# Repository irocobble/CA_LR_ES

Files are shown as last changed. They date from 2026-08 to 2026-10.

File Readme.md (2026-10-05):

# Acoustic Sensing Node

**Team:** Aninda Majumdar ([@irocobble](https://github.com/irocobble)) · Subham Basak · Kartik Kajra

A **two-board, field-deployable acoustic sensor** for search-and-rescue. The node
is placed in rubble or debris and listens for signs of a trapped person (voice,
tapping, banging). It works out **which direction** the sound came from and
sends a GPS-tagged alert over LoRa to a rescue dashboard.

Searching collapsed structures is a race against time, and the hardest question
is *where to dig*. Instead of sending people onto unstable rubble to listen, the
node sends the ears in first.

<p align="center">
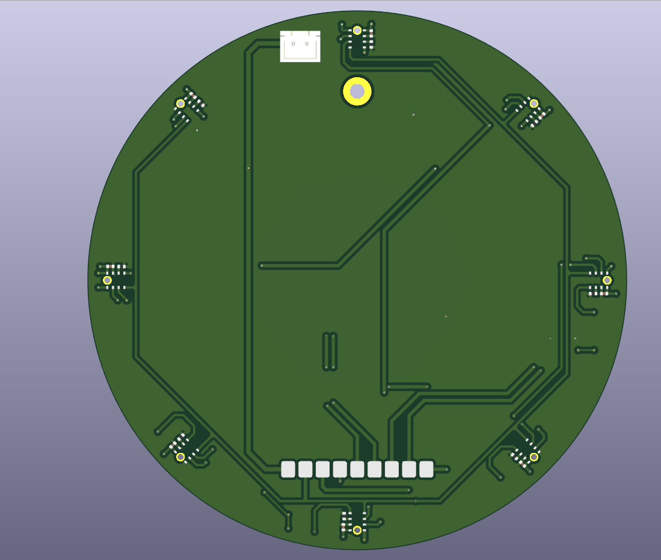
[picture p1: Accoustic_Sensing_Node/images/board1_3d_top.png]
Board 1 - microphone array, 3D render
  
  &nbsp;
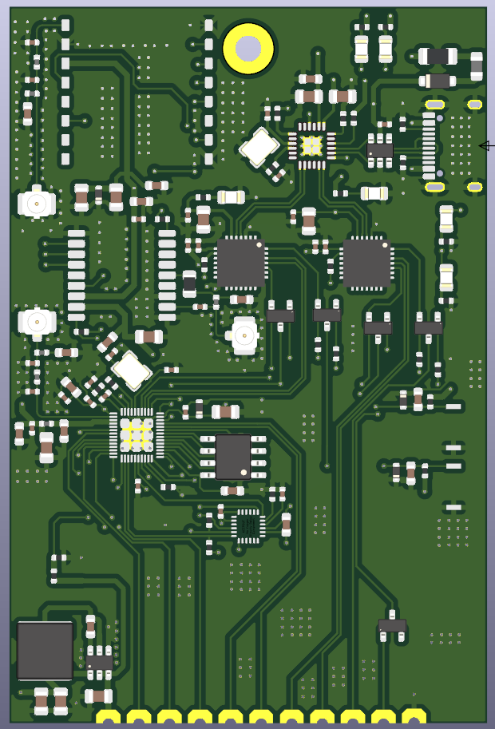
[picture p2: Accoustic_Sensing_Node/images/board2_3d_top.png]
Board 2 - main board, 3D render
  
  <br>
  <em>Left: Board 1, the 8-mic array (2-layer, Ø100 mm). Right: Board 2, the main board (4-layer, 50 × 75 mm).</em>
</p>

---

## Contents

1. [How it works](#how-it-works)
2. [Architecture](#architecture)
3. [Why two boards](#why-two-boards)
4. [Hardware](#hardware)
5. [Microphone array](#microphone-array)
6. [Board-to-board interface](#board-to-board-interface)
7. [Power](#power)
8. [Signal processing on the K210](#signal-processing-on-the-k210)
9. [Voice detection model](#voice-detection-model)
10. [Host software and dashboard](#host-software-and-dashboard)
11. [Prototype results](#prototype-results)
12. [Project status](#project-status)
13. [Open items](#open-items)
14. [Repository layout](#repository-layout)
15. [Getting started](#getting-started)
16. [Engineering notes](#engineering-notes)
17. [Roadmap](#roadmap)
18. [References](#references)

---

## How it works

```
 sound ──▶ 8 MEMS mics ──▶ K210 ──────────────────────────▶ ESP32 ──▶ LoRa ──▶ rescue dashboard
                           │ 1. capture all channels,          │ adds GPS position,
                           │    sampled on the same clock      │ IMU data, timestamp
                           │ 2. "is this a human voice?"       │
                           │ 3. "which direction?"             │
                           └─ sends only the result ───────────┘
                              (angle, confidence, voice yes/no)
```

1. **Listen.** Eight digital microphones sit on a 90 mm circle. They all run
   off one shared clock, so the tiny arrival-time differences between them are
   real and measurable.
2. **Decide.** A small voice-detection model running on the K210 decides
   continuously whether the sound looks like a human voice.
3. **Locate.** The K210 compares the signals from opposite microphones
   (GCC-PHAT) to find the arrival-time difference, then turns it into a bearing.
4. **Report.** Only the result (angle, confidence, level, voice flag) goes to the
   ESP32. No raw audio crosses between the boards.

The K210 stays **powered and listening all the time**. It is not duty-cycled.

---

## Architecture

The system is split across **two boards** that solder together along an 11-pin
castellated edge.

| Board | Layers | Size | Carries |
|---|---|---|---|
| **Board 1: Mic array** | 2 | Ø100 mm | 8× INMP441, Kendryte K210 (Sipeed M1), 12 V→5 V and 12 V→3V3 regulators |
| **Board 2: Main** | 4 | 50 × 75 mm | ESP32 (QFN-48), SX1262 LoRa, MAX-M10S GNSS, MPU-9250 IMU, USB-C hub + 2× USB-UART, 12 V→3V3 regulator |

| Processor | Role |
|---|---|
| **Kendryte K210** (Sipeed M1) | Everything acoustic: I2S master for the array, voice detection, direction finding |
| **ESP32** (QFN-48, 5 × 5 mm) | System host: LoRa, GNSS, IMU, USB, alert formatting |

**Why the K210?** A single K210 I2S peripheral has **four data inputs driven by
one clock generator**. With two microphones per data line, that is eight
channels sampled on exactly the same clock edges. Direction finding depends
entirely on that, and the K210 provides it with nothing to synchronise. It also
has a hardware FFT unit and an audio processor (APU) that can do beamforming,
which we plan to evaluate later.

```
                 ┌──────────────────────────────────────────┐
                 │  BOARD 1: Mic array  (2-layer, Ø100 mm)  │
   8× INMP441 ───┤                                          │
   circle,       │  I2S: 4 data lines, 1 shared clock       │
   r = 45 mm     │            ↓                             │
                 │  K210 / Sipeed M1  (always on)           │
                 │   · voice detection (3-feature model)    │
                 │   · direction of arrival (GCC-PHAT)      │
                 └───────────────┬──────────────────────────┘
                                 │  11-pin castellated edge
                                 │  12 V · mic clock · 2× UART · boot/reset
                 ┌───────────────┴──────────────────────────┐
                 │  BOARD 2: Main  (4-layer, 50 × 75 mm)    │
                 │  ESP32 ── SX1262 LoRa      → U.FL        │
                 │        ── MAX-M10S GNSS    → U.FL        │
                 │        ── MPU-9250 IMU                   │
                 │        ── Wi-Fi/BLE        → U.FL        │
                 │  USB-C → CH334F hub → 2× CP2102N         │
                 └──────────────────────────────────────────┘
```

The IMU is there on purpose. Tapping on rubble produces both a sound and a
vibration. Requiring both reduces false alarms in a way an acoustic-only system
cannot.

---

## Why two boards

The two halves of the design have **opposite needs**:

| | Mic array | Main electronics |
|---|---|---|
| What sets the size | **Physics**: the mics must be far apart to measure direction | **Density**: as small as routing allows |
| Area | Ø100 mm (≈ 7,850 mm²) | 50 × 75 mm (3,750 mm²) |
| Signals | Slow I2S lines, no RF | 3 RF paths, USB, fine-pitch parts |
| Layers needed | **2** | **4** |

On a single board, the whole area would have to be 4-layer, because the LoRa,
GNSS and Wi-Fi antenna feeds need a solid ground plane and 50 Ω traces. We
would be paying 4-layer prices for a large area whose only job is holding
microphones 45 mm from the centre.

### Real cost (as ordered)

Both boards were ordered from **Robu.in**. Prices include shipping.

| Board | Layers | Area | Price paid | Price per mm² |
|---|---|---|---|---|
| Board 1: Mic array | 2 | ≈ 7,850 mm² | **₹900** | ≈ ₹0.115 |
| Board 2: Main | 4 | 3,750 mm² | **₹1,800** | ≈ ₹0.48 |
| **Total (split design)** | | | **₹2,700** | |

On our order, **4-layer cost ≈ 4.2× more per mm² than 2-layer.**

What a single 4-layer board would have cost, at the same ₹0.48/mm²:

| Single-board option | Area | Estimated price | Saving from splitting |
|---|---|---|---|
| Ø100 mm round (smallest that holds the array) | ≈ 7,850 mm² | ≈ ₹3,770 | ≈ 28% |
| 100 × 100 mm (more realistic once both boards' parts fit) | 10,000 mm² | ≈ ₹4,800 | ≈ 44% |

**The split saves roughly 28–44% on bare PCBs.** This is an estimate: fabs have
minimum charges and quantity tiers, so price is not exactly proportional to area.
It is still a fair comparison because both quotes came from the same supplier.

Benefits that do not show up on the invoice:

- **Cheap iteration.** The array geometry is the least certain part of the
  design. Changing it means a new 2-layer board, not a new 4-layer one.
- **Contained failure.** A damaged mic board does not scrap the main board.
- **Assembly yield.** The finest-pitch parts (ESP32 QFN-48 at 0.35 mm,
  2× QFN-28, QFN-24) are all on the small board.
- **RF kept away from audio.** The three antennas are physically separated from
  the microphone traces.

**The trade-off:** the castellated joint is a new failure point and cannot be
probed once soldered. That is why only slow signals cross it: no RF, no
high-speed bus.

---

## Hardware

### Board 1: Mic array (`Board1_2layers/Mic+MPU/`)

| Function | Device | Ref |
|---|---|---|
| Acoustic processor | Sipeed M1 (Kendryte K210) | U12 |
| Microphones | 8× INMP441 I2S MEMS | U1–U6, U15, U16 |
| Buck 12 V → 5 V (K210) | AP63205WU | U14 |
| Buck 12 V → 3V3 (mics) | AP63203WU | U10 |
| Power input | JST-XH 2-pin, polarised | J1 |
| Board interface | 11-pin castellated, 3.2 mm pitch | J3 |
| Buttons | Boot, Reset | SW4, SW3 |

> The `Mic+MPU` folder name is historical. The MPU-9250 is on Board 2.

<p align="center">
  Board 1 top
  &nbsp;
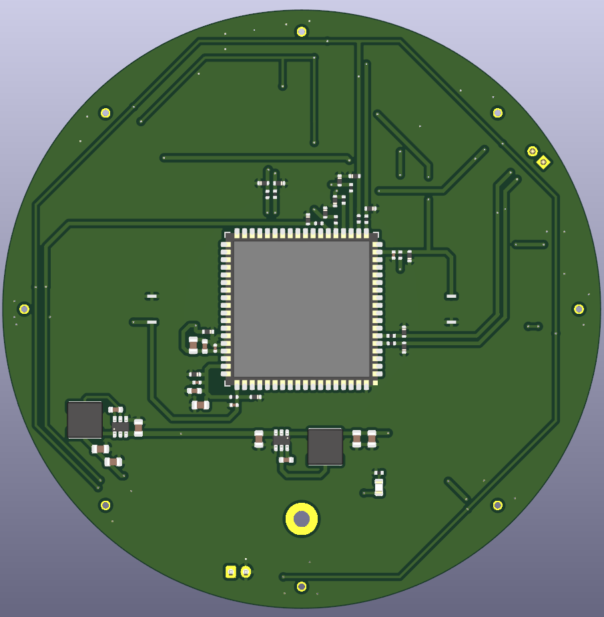
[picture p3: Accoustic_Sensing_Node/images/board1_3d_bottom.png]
Board 1 bottom, mic ports
  
  <br><em>Board 1, top and bottom. The microphone sound holes are on the bottom face.</em>
</p>

<p align="center">
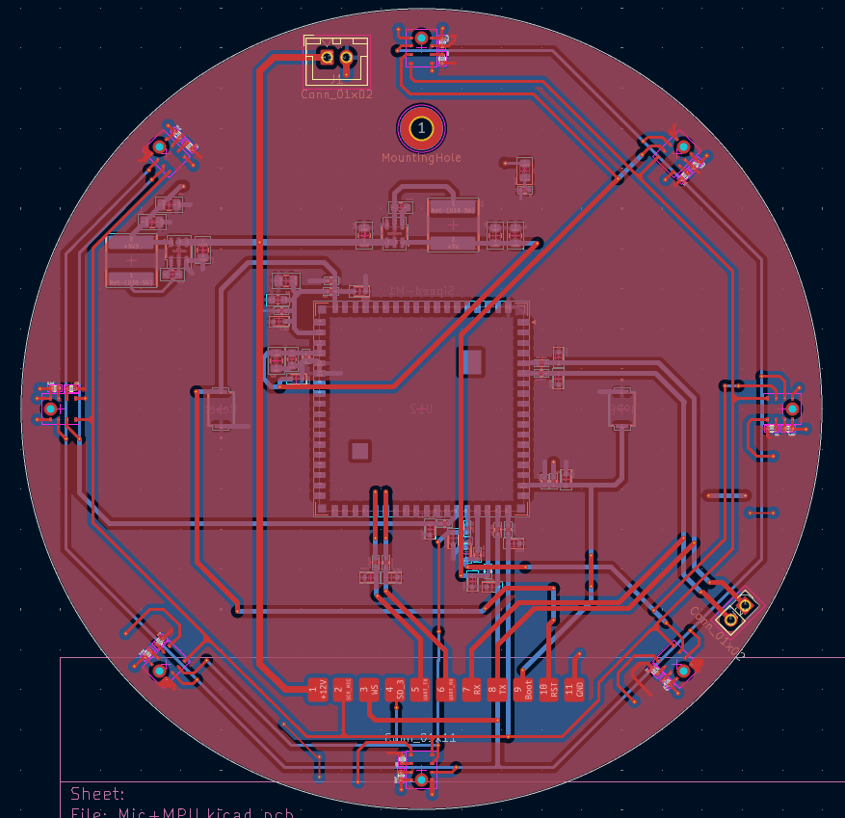
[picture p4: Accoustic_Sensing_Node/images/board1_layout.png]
Board 1 PCB layout
  
  <br><em>Board 1 layout in KiCad.</em>
</p>

### Board 2: Main (`board2_4layers/`)

| Function | Device | Ref |
|---|---|---|
| Host MCU | ESP32 (QFN-48, 5 × 5 mm) | U7 |
| External SPI flash | SPI NOR, SOIC-8 | U6 |
| LoRa transceiver | SX1262 module | U1 |
| GNSS receiver | u-blox MAX-M10S | U3 |
| IMU | MPU-9250 (9-axis) | U4 |
| USB hub | CH334F | CH334F1 |
| USB-UART bridges (ESP32 + K210) | 2× CP2102N | U8, U9 |
| USB ESD protection | USBLC6-4SC6 | U2 |
| Buck 12 V → 3V3 | AP63203WU | U5 |
| Antennas | 3× U.FL: LoRa, GNSS, Wi-Fi | J2, J4, J5 |
| USB connector | USB Type-C | J1 |
| Crystals | 40 MHz (ESP32), 12 MHz (hub) | Y2, Y1 |
| Buttons | EN, BOOT | SW1, SW2 |

Stack-up: GND on F.Cu, In1.Cu and B.Cu; +3V3 on In2.Cu.

<p align="center">
  Board 2 top
  &nbsp;
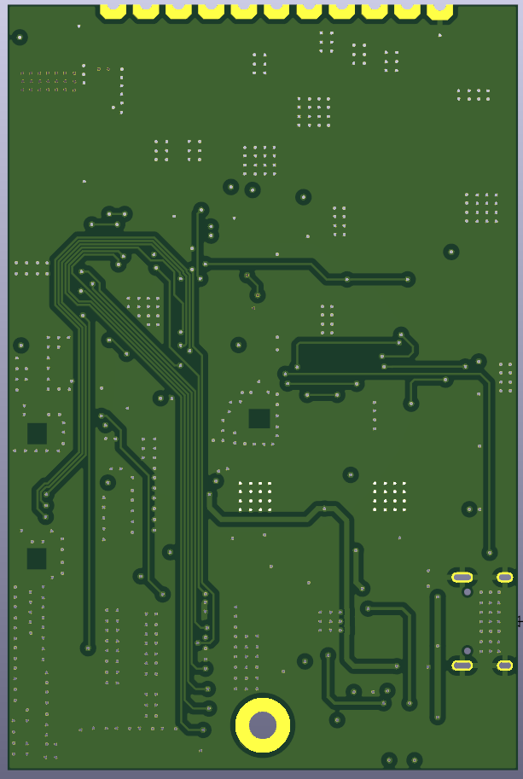
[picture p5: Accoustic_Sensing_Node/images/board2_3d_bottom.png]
Board 2 bottom
  
  <br><em>Board 2, top and bottom.</em>
</p>

<p align="center">
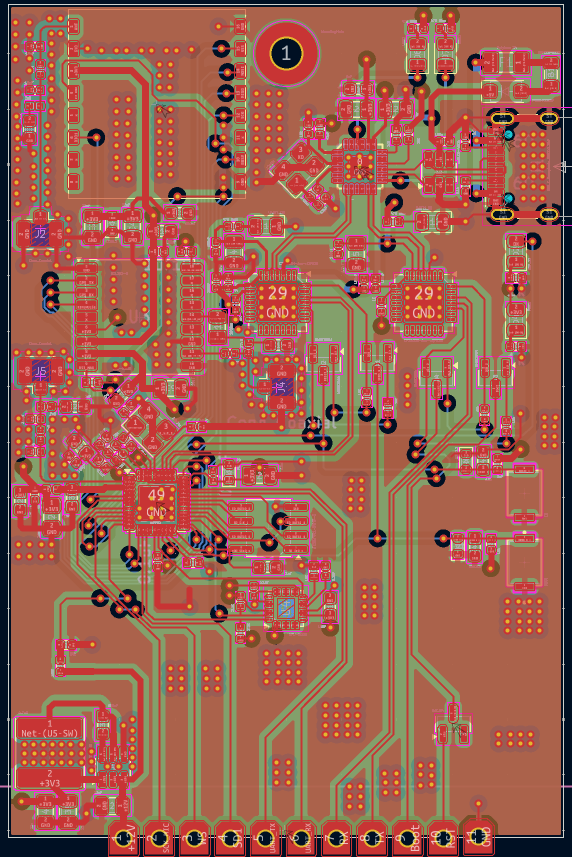
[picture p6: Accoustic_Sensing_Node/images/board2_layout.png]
Board 2 PCB layout
  
  <br><em>Board 2 layout in KiCad.</em>
</p>

---

## Microphone array

Eight INMP441 digital microphones on a circle of **radius 45.00 mm**, spaced
45° apart. Each one is rotated to face the centre, so every microphone has the
same trace shape back to the K210.

Two microphones share each data line. The INMP441's `L/R` pin decides which
half of the stereo frame each one uses: one takes the left slot, the other the
right.

| Data line | K210 pin | Mics | Angles |
|---|---|---|---|
| `SD_1` | IO20 | U1, U2 | 90°, 45° |
| `SD_2` | IO21 | U5, U6 | 0°, 315° |
| `SD_3` | IO22 | U15, U16 | 270°, 225° |
| `SD_4` | IO23 | U3, U4 | 180°, 135° |
| `SCK_MIC` | IO18 | shared bit clock | |
| `WS` | IO19 | shared word select | |

All eight sample on the same bit clock, so every channel is **phase-coherent**.
This is exactly what direction finding needs, and it is why digital MEMS mics
were chosen over analog mics behind a multiplexed ADC.

Every K210 IO used has a **200 Ω series resistor and an ESD diode**, as Sipeed
requires for the M1 module.

> **Sound enters from the bottom.** Each mic sits over a 1.05 mm hole through
> the PCB, so the openings in the enclosure must be on the bottom face.

**Geometry numbers:**

| Quantity | Value | Why it matters |
|---|---|---|
| Adjacent mic spacing | 2r·sin(22.5°) = 34.4 mm | Spatial aliasing above c / (2 × 0.0344) ≈ **5.0 kHz** |
| Opposite mic spacing | 90 mm | Longest baseline, best angle resolution |
| Max arrival-time difference | 90 mm / 343 m/s ≈ 262 µs | Only ≈ **4.2 samples** at 16 kHz, so sub-sample timing is required |

> **About IO20.** On the Sipeed **Maix development board**, IO20 is wired to the
> board's own onboard microphone, so it cannot be used for an external mic there.
> On our PCB the bare **M1 module** is used, which has no onboard microphone, so
> IO20 is free. This only matters if you test the firmware on a Maix board.

---

## Board-to-board interface

11 positions, 3.2 mm pitch, castellated. Board 2 solders directly onto Board 1,
with no connector and no cable.

| Pin | Net | Direction | Purpose |
|---|---|---|---|
| 1 | `+12V` | → Board 2 | Unregulated; each board regulates locally |
| 2 | `SCK_MIC` | K210 → ESP32 | Mic bit clock |
| 3 | `WS` | K210 → ESP32 | Mic word select |
| 4 | `SD1` | mics → ESP32 | Lets the ESP32 hear one mic pair (spare / diagnostics) |
| 5 | `UART_TX` | ESP32 → K210 | Commands |
| 6 | `UART_RX` | K210 → ESP32 | Results: voice flag, confidence, bearing |
| 7 | `RX` | K210 → CP2102N | K210 programming, transmit |
| 8 | `TX` | CP2102N → K210 | K210 programming, receive |
| 9 | `Boot` | CP2102N → K210 | IO16 boot-mode select |
| 10 | `RST` | CP2102N → K210 | Reset (1.8 V domain) |
| 11 | `GND` | | Return |

`TX` and `RX` on pins 7–8 are named **from the USB bridge's point of view** on
both boards.

Pins 2–4 were originally intended for a low-power wake detector on the ESP32.
Since the K210 now stays on all the time, that wake path is not needed. The
pins stay as a spare way for the ESP32 to listen to one mic pair. If used, the
ESP32 must be an I2S **slave**, because the K210 drives the clock.

**No raw audio crosses the joint in normal operation.** The mics feed the K210
directly; the UART carries only results.

---

## Power

```
12 V in (JST-XH, polarised)
   │
   ├── Board 1 ── AP63205 ──▶ +5V   → Sipeed M1 (K210)
   │           └─ AP63203 ──▶ +3V3  → 8× INMP441
   │
   └── via J3 pin 1 ──▶ Board 2 ── AP63203 ──▶ +3V3
                                     → ESP32, SX1262, MAX-M10S, MPU-9250, flash
```

Only 12 V and GND cross the joint, so no regulated rail loses voltage across it
and the RF and audio sections do not share regulator noise.

**Estimated ≈ 3.3 W total (≈ 320 mA at 12 V)**, mostly the K210 (≈ 1.5 W).
This is an estimate and will be measured once the boards are assembled.

---

## Signal processing on the K210

The firmware is plain C on the **kendryte-standalone-sdk**, in two CMake projects:

| Project | Build flag | Output | Use |
|---|---|---|---|
| Recorder | `-DPROJ=Recorder` | `Recorder.bin` | Streams raw mic audio to the PC for datasets and calibration |
| Detector | `-DPROJ=Detector` | `Detector.bin` | Runs voice detection and direction finding on the chip |

### Capture

- 16 kHz nominal. The K210's PLL gives a real rate of about **15,986 Hz**. The
  difference is small and does not affect the results.
- Samples are 32-bit from the INMP441, shifted down to 16-bit
  (`SAMPLE_SHIFT = 13`, the smallest shift where no channel clips).
- The conversion to 16-bit **saturates** instead of wrapping. A wrapped sample
  looks like a loose wire, which is very confusing during debugging.
- A **100 Hz high-pass filter** (4th-order Butterworth) removes rumble and DC
  before anything else.

### Direction of arrival (GCC-PHAT)

For each pair of opposite microphones:

1. Take a **1024-point FFT (64 ms)** of both channels.
2. Compute the cross-spectrum and divide each bin by its own magnitude
   (the **PHAT** weighting). This keeps only phase, which is what carries timing.
3. **Keep only 300–3400 Hz** (the speech band). Without this mask, the empty
   bins are amplified to the same weight as real ones and the answer is
   essentially random. Measured: a true delay of 1.50 samples was estimated as
   0.14 unmasked and 1.49 masked.
4. **Search for the delay directly at fractional lags.** A coarse pass in
   0.10-sample steps, then a fine pass in 0.01-sample steps around the best one.
   Each lag is evaluated with the FFT shift theorem, so no curve-fitting is
   needed. This matters because the whole array spans only about 4 samples of
   delay; whole-sample steps would give very coarse bearings.
5. The search range comes from the spacing:
   `max lag = spacing / c × fs × 1.4` (40% extra for echoes and measurement error).
6. Two perpendicular pairs give `lag_x` and `lag_y`, and the bearing is
   `atan2(lag_y, lag_x)`.
7. Results are rejected if the sound is too quiet (`-45 dB` level gate), the
   correlation is too weak (`< 0.08`), or the delay is impossibly large.

Direction finding runs on **any loud enough sound**, not only on speech. The
voice flag is reported alongside it.

**Calibration matters.** On the prototype, two I2S channels start on different
word-select edges, which adds a constant offset between them. We measured
`lag_x` bias = **−0.93** and `lag_y` bias = **+0.95** samples, and the firmware
subtracts them (`DOA_LAG_X_BIAS`, `DOA_LAG_Y_BIAS`).

### What the array can and cannot do

- It reports **one bearing per update**: the dominant sound source. Separating
  several people talking at once needs a much larger array (roughly 0.5 m or
  more across), which is not practical for a node this size.
- It gives **direction, not distance**. On the dashboard, how far a dot is from
  the centre shows **how old** the detection is, not how far away the source is.
- Distance comes from **combining several nodes** (triangulation), which is on
  the roadmap.

### Result packet (K210 → host)

20 bytes, sent at `REPORT_HZ = 20`:

```
[5A A6] [len=0x10] [seq] [angle×10 : i16] [conf×1000 : u16] [score×100 : i16]
[level_db×10 : i16] [speech : u8] [warm : u8] [lag_x×100 : i16] [lag_y×100 : i16] [xor] [pad]
```

Raw-audio frames from the Recorder use:

```
[5A A5] [seq : u8] [blk : u16] [nch : u8] [int16 samples × blk·nch] [sum16]
```

The sequence number lets the PC detect and count dropped bytes. Before framing,
one lost byte silently turned the rest of a recording into noise while the WAV
file still looked valid.

---

## Voice detection model

A **logistic regression on 3 hand-picked features**, small enough to run on the
K210 as a single dot product.

| Feature | What it measures |
|---|---|
| `harmonicity` | Strength of the pitch peak in the autocorrelation (human pitch range, lags 40–266 samples) |
| `voice_band_ratio` | Share of energy in 300–3400 Hz (512-point Hann-window FFTs) |
| `snr_db` | Level above a rolling noise floor (20th percentile over the last 8 s) |

- Trained in Python (`Accoustic_Sensing_Node/ML/`). The feature scaler is folded into the weights and
  exported as `vad3_model.h`, so the chip does no extra scaling.
- Decision threshold (logit) **2.389**, then smoothed over **3** consecutive
  decisions (`VAD_SMOOTH_K = 3`).
- `FEATURE_VERSION = 4`. The firmware and Python feature code must match. The
  version number makes a mismatch obvious.
- Evaluation uses **grouped cross-validation by recording file**, so clips from
  the same recording never appear in both training and test. The main metric is
  **recall at 5% false-positive rate**, because false alarms are what make
  rescuers stop trusting a sensor.

### Dataset status

Our own recordings (`INMP_441_Dataset/`) are combined with public datasets
(`Public_Dataset/`). Every file goes through a quality check (dropped bytes,
clipping, DC offset, rumble, SNR) before it is used.

We also run a **confound check**: a classifier trained only on the *background*
of each recording, with the speech removed. If it can still tell the classes
apart, the model could be learning *which session* a clip came from instead of
*whether someone is speaking*.

| Dataset version | Background-only AUC | Target |
|---|---|---|
| First dataset | 0.905 – 0.94 | < 0.65 |
| Latest | **0.812** | < 0.65 |

It is improving, but still above target. Recording speech and non-speech
**interleaved in the same session, room and distance** is the fix in progress.

---

## Host software and dashboard

Python tools on the PC, all reachable from one entry point:

```
python capstone.py --help
```

| Command | What it does |
|---|---|
| `status`, `devices`, `linktest`, `inspect` | Check setup, list serial ports, test the link, inspect captures |
| `record` | Record labelled clips from the board |
| `qc`, `filters` | Dataset quality check, filter tests |
| `train`, `train-corpus`, `export` | Train the model and export `vad3_model.h` |
| `predict` | Run the model on WAV files |
| `serve`, `monitor`, `gui` | Live API + dashboard, console monitor, desktop GUI (`sar_gui.py`) |

**API server** (`api_server.py`): reads the K210's result packets from serial
and serves them over HTTP on all interfaces (port 8000 by default), so a phone
on the same Wi-Fi hotspot can open the dashboard.

| Endpoint | Returns |
|---|---|
| `/api/detections` | Detections from the last 15 s |
| `/api/state` | Latest bearing, level, voice flag |
| `/api/threshold` | Read or change the detection threshold |
| `/api/health` | Server and serial-link status |
| `/` | `dashboard.html`, the radial display |

It uses a threaded server with HTTP/1.1 keep-alive, which fixed the lag we saw
on phones over a hotspot.

<p align="center">
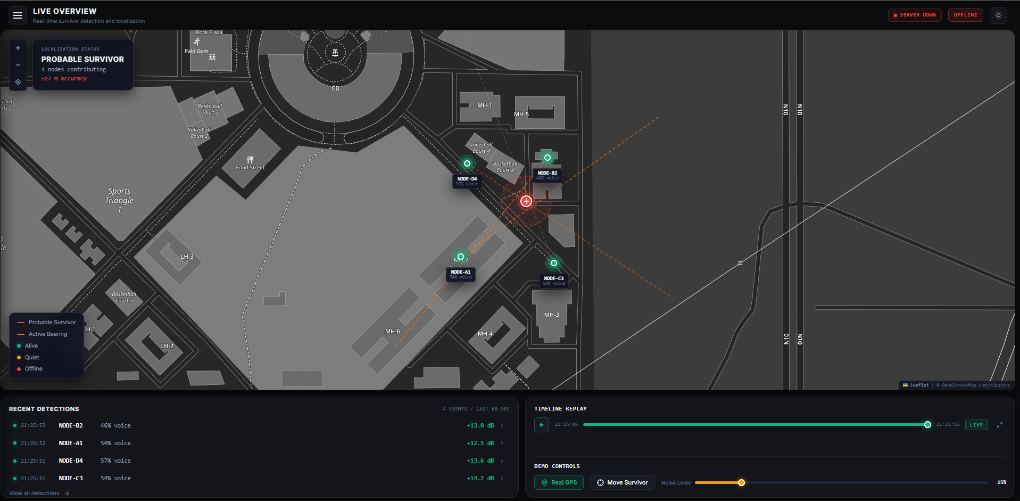
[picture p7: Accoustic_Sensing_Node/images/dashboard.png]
Live dashboard
  
  <br><em>Live dashboard in the browser.</em>
</p>

---

## Prototype results

Before the PCBs, the full pipeline was built on a breadboard: a Sipeed Maix
board with **4 INMP441 mics in a 40 mm square**. Opposite corners are paired, so
the baseline is the square's diagonal, **56.6 mm**.

<!-- Add the photo later: save it as Accoustic_Sensing_Node/images/prototype_breadboard.jpg and delete these comment markers
<p align="center">
  <img src="Accoustic_Sensing_Node/images/prototype_breadboard.jpg" width="60%" alt="Breadboard prototype">
  <br><em>Breadboard prototype: Maix board + 4 INMP441 in a 40 mm square.</em>
</p>
-->

What works on the prototype:

- Phase-coherent 4-channel capture on one I2S peripheral
- On-chip voice detection and GCC-PHAT bearing, streamed live to the dashboard
- North and West bearings accurate before calibration; East and South were
  tilted until the cross-channel bias correction was added

**A measured accuracy table (true angle vs reported angle, several distances)
will be added once the PCB is assembled.** Numbers from the breadboard are not
representative of the final board, so they are not published here.

---

## Project status

### Hardware

- [x] Board 1 schematic and layout complete; 8 mics at exact geometry (r = 45.000 mm)
- [x] Board 1: K210 power, programming, boot/reset, 1.8 V reset domain; 200 Ω + ESD on every IO
- [x] Board 2 schematic and layout complete, DRC clean
- [x] Board 2: ESP32 core, LoRa, GNSS (active-antenna bias-T), IMU, USB-C hub with auto boot/reset for both processors
- [x] **Both boards ordered** (Robu.in)
- [ ] Assembly and bring-up
- [ ] Measured power consumption

### Firmware (K210)

- [x] `Recorder` and `Detector` CMake projects
- [x] Framed, checksummed audio stream with sequence numbers
- [x] On-chip 3-feature voice detector (`vad3_model.h`, `FEATURE_VERSION = 4`)
- [x] Working 4-mic GCC-PHAT direction finding on the prototype, with bias calibration
- [ ] 8-channel capture on the new array
- [ ] Re-measure all DOA constants on the circular array
- [ ] Evaluate the K210 APU hardware beamformer

### Firmware (ESP32)

- [ ] LoRa, GNSS and IMU drivers
- [ ] UART link to the K210 and alert formatting
- [ ] Sound + vibration fusion

### Host software

- [x] `capstone.py` single entry point, `sar_gui.py` desktop GUI
- [x] API server + dashboard, 15 s detection window, keep-alive
- [x] Dataset QC, training, grouped evaluation, C-header export
- [ ] Multi-node triangulation view

---

## Open items

| # | Item | Where | What to do |
|---|---|---|---|
| 1 | **DOA constants are for the 4-mic breadboard** | Firmware | `DOA_SPACING_MM`, `SAMPLE_SHIFT` and both lag biases must be re-measured on the circular array (opposite pair = 90 mm) |
| 2 | **Every opposite pair spans two data lines** | Firmware | e.g. 0° is on `SD_2` and 180° on `SD_4`. Each data line may have its own timing offset, so calibrate a **per-data-line offset** at bring-up (the prototype needed ≈ ±0.9 samples) |
| 3 | **Channel order is not ring order** | Firmware | K210 inputs D0–D3 = `SD_4`, `SD_3`, `SD_2`, `SD_1`. Build the channel→angle table and confirm it with a tap test at each mic |
| 4 | Dataset confound | ML | Background-only AUC 0.812, target < 0.65. Record both classes interleaved in the same session |
| 5 | Measured DOA accuracy table | Testing | After PCB assembly |
| 6 | Flash part name | Board 2 | U6 value field shows `AT25SF081`; update it to the part actually fitted |
| 7 | CP2102N no-connect pins | Board 2 | Add no-connect flags on U8/U9 pin 10 (cosmetic, clean ERC) |
| 8 | Stale BOM export | Board 2 | `Accoustic_Sensing_Node.csv` is from an older revision; re-export from KiCad |
| 9 | Battery operation | Both | Node runs from 12 V only; battery + boost planned |
| 10 | One M2.5 mounting hole per board | Both | Add more before the enclosure is fixed |
| 11 | Enclosure | Mechanical | Sound openings on the bottom face, antenna clearance, survives drops |

---

## Repository layout

Everything for the acoustic node lives in the `Accoustic_Sensing_Node/` folder:

```text
Accoustic_Sensing_Node/
├── README.md                     ← copy of this file
├── images/                       ← all pictures used in this README
│
├── Board1_2layers/
│   ├── Mic+MPU/                  KiCad project: mic array board (2-layer)
│   │   ├── Mic.pretty/           INMP441 footprint (with sound hole)
│   │   ├── Connectors.pretty/    11-pin castellated footprint
│   │   └── output/               Gerbers as ordered
│   └── mic/INMP441.kicad_mod
│
├── board2_4layers/               KiCad project: main board (4-layer)
│   ├── *.pretty/                 custom footprints (LoRa, GNSS, USB hub, edge pads)
│   └── Output/                   Gerbers + drill as ordered
│
├── Recording_Via_IOT_Devices/
│   ├── firmware/
│   │   ├── K210/src/Recorder/    raw multi-channel streaming
│   │   ├── K210/src/Detector/    main_detector.c, sar_features.c, sar_doa.c, vad3_model.h
│   │   └── esp32_1mic/           single-mic ESP32 recorder (dataset collection)
│   ├── record.py, devices.py     recorder and per-board serial settings
│   ├── api_server.py             HTTP API + serial reader
│   ├── dashboard.html            radial live display
│   ├── detector_monitor.py       console monitor
│   └── link_test.py              serial link test
│
├── ML/                           features, training, QC, export to C header
├── capstone.py                   single entry point for all tools
├── sar_gui.py                    desktop GUI
├── requirements.txt
├── run_gui.bat, build_exe.bat
└── BUILD.md                      building the firmware and the .exe
```

Datasets (`INMP_441_Dataset/`, `Public_Dataset/`) are **not** stored in the repo
because of their size.

---

## Getting started

Run everything from inside the acoustic folder:

```bash
cd Accoustic_Sensing_Node
```

### 1. Python tools

```bash
pip install -r requirements.txt
python capstone.py status
```

Try the dashboard with no hardware:

```bash
python Recording_Via_IOT_Devices/api_server.py --demo
# open http://localhost:8000
```

### 2. Build and flash the K210 firmware

```bash
cd Recording_Via_IOT_Devices/firmware/K210
mkdir build && cd build
cmake .. -DPROJ=Detector -DTOOLCHAIN=/opt/kendryte-toolchain/bin
make
kflash -p COM12 -b 1500000 Detector.bin
```

> **Delete the `build/` folder when switching between `Recorder` and
> `Detector`.** CMake caches the project name, so otherwise it silently builds
> the old one again.

See `BUILD.md` for Windows details.

### 3. Run live

```bash
python Recording_Via_IOT_Devices/api_server.py --port COM12
# optional: --capture session.bin  (save the raw stream to replay later)
#           --wav heard.wav        (save what the detector is hearing)
#           --replay session.bin   (replay a saved session, no hardware)
```

Then open `http://<pc-ip>:8000` on any device on the same network.

---

## Engineering notes

Things learned the hard way, kept here so they are not learned twice:

- **Measure, don't assume.** Every DOA constant on the prototype came from
  measurement, not a datasheet. Mic spacing is measured between the actual
  sound holes, in **millimetres**.
- **Serial port settings.** pyserial asserts DTR and RTS by default. That
  resets the ESP32 and puts the K210 into its bootloader, where it sends
  nothing. `devices.py` clears both before opening the port.
- **UART pins.** The ESP32 transmits on GPIO5, so the K210 uses **IO31 as RX and
  IO30 as TX**.
- **ESP32 GPIO12 stays unconnected.** It sets the flash voltage at reset; high
  selects 1.8 V.
- **K210 IO voltages.** IO0–IO35 are 3.3 V, IO36–IO47 are 1.8 V. Every signal
  used is IO35 or below.
- **ESP32 flash mode.** Start in DIO; QIO needs chip-specific setup.
- **Faulty mics happen.** During prototyping one INMP441 was dead and one had
  a blocked sound hole (≈ 6.6 dB quieter). Check every channel's level before
  trusting a bearing.

---

## Roadmap

- Assemble both boards; bring up 8-channel capture
- Re-calibrate DOA on the circular array and publish a measured accuracy table
- Compare the K210 APU hardware beamformer with software GCC-PHAT
- Move the voice model to the 8-mic front end
- ESP32: LoRa, GNSS, IMU and the end-to-end alert path
- Combine sound and vibration (IMU) to reduce false alarms
- Multi-node triangulation on the dashboard
- Battery power (the K210 stays always on, so battery size is set by its ≈ 1.5 W)
- Enclosure: sound openings, antenna clearance, drop survival

---

## Applications

**Main use:** search-and-rescue: locating people trapped under collapsed
buildings. Several nodes across a site turn a large, uncertain search area into
a short list of places worth digging.

**Other uses:** perimeter and intrusion detection, wildlife monitoring, noise
source mapping, remote sensor networks with human-presence detection.

---

## References

- C. Knapp and G. Carter, *The Generalized Correlation Method for Estimation of
  Time Delay*, IEEE Trans. ASSP, 1976 (GCC-PHAT)
- J. DiBiase, *A High-Accuracy, Low-Latency Technique for Talker Localization
  in Reverberant Environments Using Microphone Arrays*, PhD thesis, Brown
  University, 2000 (SRP-PHAT)
- Sipeed M1 datasheet: module pinout, IO voltages, reset constraints
- Kendryte K210 datasheet and kendryte-standalone-sdk
- InvenSense INMP441 datasheet
- Espressif *ESP32 Hardware Design Guidelines*

---

## License

Under active development. License to be decided.

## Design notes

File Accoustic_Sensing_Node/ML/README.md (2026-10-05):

# ML

Three features. That is the whole input.

```
python qc.py                      check the dataset first
python train_basic.py             fit and cross-validate
python predict.py --wav x.wav     run it on a file
python predict.py --port COM12    run it live
```

## Files

- `features3.py` — the three features, written to be read. Each one has the
  idea in plain words, the steps, and a note on what the C version looks like.
- `qc.py` — per-file health plus the confound probe.
- `train_basic.py` — your own recordings only. Grouped cross-validation,
  recall@5%FPR, and a single-threshold baseline for comparison.
- `train_corpus.py` — your recordings plus `Public_Dataset`, every source
  budgeted by window count.
- `predict.py` — file and live inference, with smoothing and hangover.
- `filter_test.py` — compares front-end filter settings against your data
  and against synthetic confusers. Run it before changing the filtering.

## The high-pass is not optional

Everything is filtered at 100 Hz before any feature is computed. Without it,
`harmonicity` measures the microphone's low-frequency rumble instead of the
voice. Measured on the first dataset:

| | speech | non-speech | d-prime |
|---|---|---|---|
| no high-pass | 0.691 | 0.696 | **0.03** |
| 100 Hz high-pass | 0.660 | 0.377 | **2.43** |

The firmware removes DC only, at about 5 Hz, so this has to happen here.
Filtering on the device is irreversible; filtering here is a line you can
change.

## Read the d-prime table before the accuracy

`train_basic.py` prints how well each feature separates the classes on its
own. Above 1 is useful, above 2 is strong. If a feature sits near 0 it is
contributing nothing and something upstream is wrong — that table is what
caught the missing high-pass.

## Why not accuracy

Accuracy on an imbalanced, cost-asymmetric problem rewards guessing the
majority class. Report **recall at 5% false-alarm rate**: how many voices you
catch, at a stated cost in false alarms.

Also: PR-AUC is only comparable between runs with the same class balance,
because its chance baseline *is* the positive rate. Use ROC-AUC or
recall@FPR when comparing across datasets.

## Growing past three features

Add a fourth only when you can name the failure it fixes. The previous
version of this project reached 52 features, and an ablation showed the two
largest-weighted ones could be deleted with a cost of 0.001 — they were
collinear with features already present. More features mostly buys more ways
to be wrong.

## Budget by windows, never by files

`train_corpus.py` caps each source by **window count**, and this is the whole
reason it exists. Window yield per file differs by three orders of magnitude:

| source | typical file | windows per file |
|---|---|---|
| MUSAN speech | ~8 min | ~1000 |
| MUSAN music | ~2 min | ~450 |
| ESC-50 | 5 s | 9 |
| Speech Commands | 1 s | 1 |

Cap every source at 1200 *files* and MUSAN takes 99.4% of the positive
windows while Speech Commands contributes 0.6% — the speaker diversity that
was the entire reason for adding it never reaches the model. The per-source
percentage table printed at startup is there so this is visible immediately.

Two other things it handles that a naive loader would not: ESC-50 is 44.1 kHz
while everything else is 16 kHz, so it resamples; and Speech Commands clips
are exactly one window long, which makes `snr_db` degenerate, so short clips
are concatenated into longer pseudo-recordings first.

## The feature-subset table

Every run prints recall@5%FPR for all seven combinations of the three
features. If a two-feature row is within about 0.02 of all three, drop the
third — one fewer feature is one fewer thing to port to C and one fewer thing
to test for numerical parity.

## Should you add a low-pass?

Run `python filter_test.py` rather than guessing. The measured answer so far:

**A low-pass does not help, and can backfire.** Narrowband signals
autocorrelate well, so restricting the band makes *everything* look more
periodic. Measured on synthetic confusers, white noise harmonicity climbs
from 0.152 to 0.330 as the low-pass tightens from none to 1 kHz — the feature
becomes less able to reject the thing it exists to reject.

**Pre-emphasis is the change that helps.** `y[n] = x[n] - 0.97·x[n-1]`, one
multiply-add, flattens a 1/f spectrum. 1/f noise is concentrated at low
frequencies and therefore looks narrowband, which is why rumble scores as
"periodic" when it is nothing of the sort:

| confuser | HP100 only | HP100 + pre-emphasis |
|---|---|---|
| pink noise | 0.625 | **0.182** |
| wind rumble | 0.452 | **0.142** |
| speech | 0.812 | 0.787 |

Margin against the worst confuser goes from −0.038 to **+0.058**, the only
configuration tested that reaches positive.

**But the two tests disagree, so this is not settled.** On the first dataset,
pre-emphasis *lowered* harmonicity d-prime from 2.43 to 1.57 — because that
dataset's negatives are rumble-dominated room tone, and its confound is partly
rumble, so removing rumble removes some of the (spurious) separation. Believe
the synthetic test until your own negatives contain wind, machinery and 1/f
rumble, and re-run both once `qc.py`'s probe passes.

## The limit no filter fixes

A steady tonal source — a generator, the canonical rubble-site confuser —
scores **0.850** harmonicity against speech's 0.812, under every filter
setting tested. That is not a bug: a generator genuinely is periodic.

The cue that separates them is syllable-rate modulation. Speech fluctuates at
2–8 Hz because of syllables; a generator does not. Add that fourth feature
when you have recorded a generator and can show it is needed — not before.

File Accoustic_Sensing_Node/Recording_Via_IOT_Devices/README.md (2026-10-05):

# Recording_Via_IOT_Devices

```
python record.py --list
python record.py --device esp32 --port COM12 --label speech --minutes 2 \
                 --speaker 1 --room lab --set 1 --distance 2m
```

## Files

- `record.py` — the recorder. Handles all three boards.
- `devices.py` — baud rate, frame format and DTR/RTS policy per board.
  Adding a board means adding one entry here.
- `firmware/esp32_1mic/esp32_1mic.ino` — one INMP441, framed output.
- `firmware/k210_1mic/k210_1mic.c` — same, for the Kendryte SDK.

## Wire formats

ESP32 / STM32 (`v2`):
```
[0x5A][0xA5][seq16][count16][int16 payload × count][xor8]
```

K210 (`k210`):
```
[0x5A][0xA5][seq8][blk16][nch8][int16 payload × blk·nch][sum16]
```

The magic word alone is **not** a sync point: `0x5A 0xA5` occurs by chance
inside int16 audio in about 1.6% of blocks, and locking onto a false one at an
odd byte offset shifts every sample boundary afterwards. So four things are
checked before a frame is accepted — the shape fields are sane, the channel
count matches, the checksum matches, and the sequence advanced by exactly one.
A false magic fails at least one of them nearly always.

The sequence number is the point. Raw unframed PCM has no way to recover from
a dropped byte: lose one and the 16-bit sample boundary flips, so every
sample afterwards is noise at the Nyquist frequency — while the WAV header
stays valid and the file still plays. Three files in the first dataset failed
exactly this way and it took weeks to notice. With sequence numbers the
recorder **counts** what was lost and tells you while you are still standing
there.

Watch the `dropped=` counter during capture. If it climbs, stop: lower the
baud rate or shorten the USB cable before recording anything you intend to
keep.

## Two board-specific traps

**Both boards must have DTR and RTS deasserted before the port opens.**
pyserial asserts both by default. On the ESP32 that reboots the board
mid-capture; on the K210 it drops into the ISP bootloader, where it sends
nothing at all and the capture reads zero bytes forever. `devices.py` sets
both to `False`.

**The CH552/CH340 bridge on the K210 ignores the configured baud rate.**
Throughput is fixed and lower than requested regardless of what you ask for,
which makes the K210 a poor choice for streaming audio. Prefer the ESP32 for
dataset collection.

## Before trusting any audio

The firmware prints `#` diagnostic lines at boot: which I2S slot the mic is
actually in, the min/max sample values, and the measured sample rate.
`record.py` shows them. Healthy means min and max swing on both sides of
zero, not all-zero, not pinned at the rails. Slot and shift are worth
observing rather than assuming — on the earlier bring-up the datasheet alone
was not enough and both had to be settled by dumping raw words.

## K210: only one slot is transmitted

One I2S data line always carries two slots — 64 bit-clocks per frame, not
configurable. So `k210_1mic.c` still *captures* both and keeps the one the
microphone is in. That halves the payload:

| | frame | throughput | share of the 921600 link |
|---|---|---|---|
| both slots | 1032 B | 64.5 kB/s | 70% |
| one slot | 520 B | 32.5 kB/s | **35%** |

The CH552-class bridge has no flow control back to the K210, so headroom is
the only defence against drops. This is the largest reliability gain available
without changing hardware.

**Set `MIC_SLOT` from the tap test, not from the datasheet.** The diagnostic
window reads both slots and marks the one being kept with `*`. Tap the
housing: exactly one should jump. The wrong slot records the undriven line —
near-silence, valid header, plays fine, trains a useless model.

## The K210 high-pass was moved from 300 Hz to 20 Hz

The array firmware filtered at 300 Hz, which was correct there: across a
100 mm baseline a 1 m wavelength carries no usable timing information.

For single-microphone voice detection it breaks the main feature. Harmonicity
finds the pitch period, and 300 Hz sits *above* the fundamental of every adult
voice — 85–155 Hz male, 165–255 Hz female. Autocorrelation can still work off
the harmonics, but it weakens and becomes prone to octave errors.

So the firmware now removes DC and nothing else. The real 100 Hz high-pass
lives in `ML/features3.py`, where it is a line you can change rather than a
reflash.

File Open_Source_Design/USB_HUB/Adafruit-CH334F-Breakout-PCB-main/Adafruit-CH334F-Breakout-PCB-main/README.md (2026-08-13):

## Adafruit CH334F Mini USB Hub Breakouts PCB

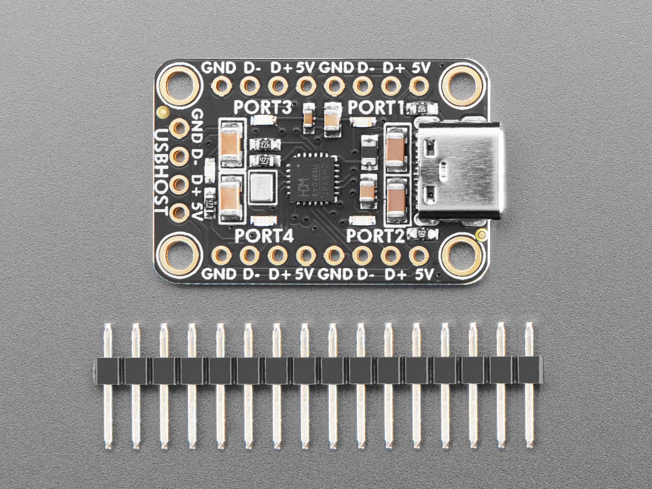
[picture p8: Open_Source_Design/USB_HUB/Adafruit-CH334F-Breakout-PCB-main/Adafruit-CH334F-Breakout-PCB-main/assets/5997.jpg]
<a href="http://www.adafruit.com/products/5997"><br/>
Click here to purchase one from the Adafruit shop</a>
<br>
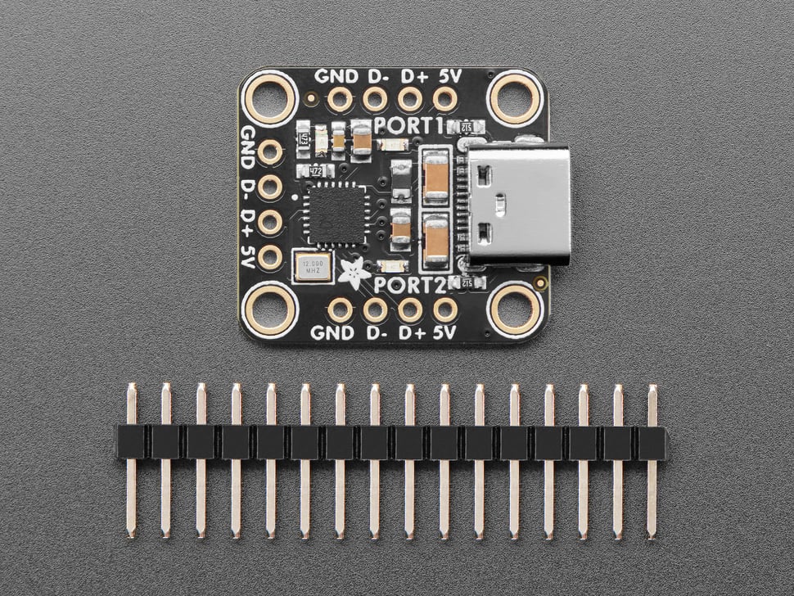
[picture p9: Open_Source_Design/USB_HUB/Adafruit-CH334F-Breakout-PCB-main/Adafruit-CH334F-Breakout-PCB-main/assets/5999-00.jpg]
<a href="http://www.adafruit.com/products/5999"><br/>
Click here to purchase one from the Adafruit shop</a>

PCB files for the Adafruit CH334F Mini USB Hub Breakouts

Format is EagleCAD schematic and board layout
* https://www.adafruit.com/product/5997
* https://www.adafruit.com/product/5999

### Description

Sometimes you've got something with USB host, like a embedded linux board, and you want to connect more than one thing. Or maybe you want to turn something like a keyboard into a multi-device USB peripheral. The Adafruit CH334F Mini 4-Port USB Hub Breakout will do that for you! it features a CH334F USB 2.1 hub chip which converts one high-speed port into four.

Most folks who use a USB hub get one that comes in an enclosure with connectors or cables included. But, those hubs are going to be bulky - they're meant for external use. This breakout board is designed to be compact, so it can easily be embedded into an enclosure or existing device. There's four mounting holes but other than that, we tried to keep it as compact as possible.

Part of how we kept it small is not including downstream ports! The breakout has either 0.1" header or USB C for the upstream, and then four 4-pin ports for peripheral connections. We expect folks to solder directly to the pads or use our 'simple' USB-breakout cables.

You get one fully assembled/tested boards and some extra header if you happen to want to plug it into a breadboard. Other than that, just keep in mind there's no USB ports for the 4 downstreams - if you need those take a look at some of the other hubs we stock.

### License

Adafruit invests time and resources providing this open source design, please support Adafruit and open-source hardware by purchasing products from [Adafruit](https://www.adafruit.com)!

Designed by Limor Fried/Ladyada for Adafruit Industries.

Creative Commons Attribution/Share-Alike, all text above must be included in any redistribution. 
See license.txt for additional details.

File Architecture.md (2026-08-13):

# System Architecture

## Introduction

The **Acoustic Sensing Node** is a single-board embedded platform for acoustic
search-and-rescue. It is designed to be physically inserted into rubble or
debris, detect human distress signals, estimate the direction those signals came
from, and relay a GPS-tagged alert over a long-range radio link — fully
self-contained, with no cable, no network, and no operator nearby.

All subsystems — microphone array, edge inference, positioning, inertial sensing,
radio, and power — are consolidated onto one PCB. Integration over modularity is
deliberate: a unit that gets thrown or dropped into debris has fewer failure
points with fewer interconnects.

---

## Design Goals

### Direction, Not Just Detection

The node's headline output is a **bearing**, not a boolean. A rescue team acting
on "survivor at bearing 42° from node 3" can dig in a specific place; a team
acting on "sound detected" cannot. This drove the choice of a six-microphone
phase-coherent array and a processor with hardware array-processing support.

### Hardware-Accelerated Acoustic Processing

The Kendryte K210's **APU (Audio Processing Unit)** implements microphone-array
processing in silicon: sound source localization, beamforming, and voice
detection, backed by a dedicated FFT accelerator. Doing direction-of-arrival in
hardware rather than in a DSP loop keeps the compute budget available for
classification.

### Split of Concerns Across Two Processors

The K210 owns the acoustic path end-to-end — it is the I2S master for the mic
array and runs beamforming and classification. The ESP32-S3 owns everything else
— radio, positioning, inertial sensing, USB and power. Neither processor
duplicates the other's work, and the link between them carries results only.

### Cross-Modal False-Positive Rejection

A 9-axis IMU sits alongside the acoustic front end. Tapping and banging produce
both an acoustic signature and a mechanical impact signature; requiring both
substantially reduces false alarms from wind, settling debris, and machinery.

### Field Deployability

GNSS positioning and timestamping, LoRa reporting, onboard power regulation, and
a ruggedized enclosure allow the node to operate unattended in an outdoor,
uncontrolled environment.

---

## System Overview

The schematic is organized into five functional blocks:

| Block | Contents |
|---|---|
| **ESP32** | ESP32-S3 MCU, 40 MHz crystal, W25Q128 flash, decoupling |
| **K210 Module** | Sipeed M1 module, CP2102N USB-UART bridge, boot/reset |
| **Communication** | SX1262 LoRa, MAX-M10S GNSS, CH334F USB hub |
| **Other** | 6× INMP441 microphone array, MPU-9250 IMU, status LEDs |
| **USB + Power** | USB-C receptacle, ESD, 12 MHz crystal, AP63203 buck |

```text
        ┌──────────────────────────────────────────────────────────┐
        │                   ACOUSTIC SENSING NODE                  │
        │                                                          │
        │   ┌──────────────┐                                       │
        │   │ 6x INMP441   │                                       │
        │   │ mic array    │   SCK_MIC · WS · SD_1 · SD_2 · SD_3   │
        │   └──────┬───────┘                                       │
        │          │ I2S (K210 = master)                           │
        │          ▼                                               │
        │   ┌──────────────────────┐                               │
        │   │  K210 / Sipeed M1    │◀── CP2102N ◀── USB hub        │
        │   │  · APU beamforming   │      (ISP)         ▲          │
        │   │  · DoA estimation    │                    │          │
        │   │  · classification    │                    │          │
        │   └──────────┬───────────┘                    │          │
        │              │ QSPI ×6 (results only)         │          │
        │              ▼                                │          │
        │   ┌──────────────────────┐                    │          │
        │   │     ESP32-S3         │◀── native USB ─────┤          │
        │   │  · alert formatting  │                    │          │
        │   │  · system control    │              ┌─────┴──────┐   │
        │   └──┬────────┬───────┬──┘              │  CH334F    │   │
        │      │ SPI    │ UART  │ I2C             │  USB hub   │   │
        │      ▼        ▼       ▼                 └─────┬──────┘   │
        │  ┌───────┐ ┌──────┐ ┌──────────┐              │          │
        │  │SX1262 │ │MAX-  │ │MPU-9250  │        ┌─────┴──────┐   │
        │  │ LoRa  │ │M10S  │ │  IMU     │        │  USB-C     │   │
        │  └───┬───┘ └──┬───┘ └──────────┘        │  + ESD     │   │
        │      │        │                         └─────┬──────┘   │
        │     J4       J1                               │          │
        │   (ANT)    (GNSS)                        AP63203 buck    │
        │                                          5V → 3V3        │
        └──────────────────────────────────────────────────────────┘
```

---

# Hardware Architecture

## Processing Subsystem

### K210 / Sipeed M1 — Acoustic Processor

**Responsibilities**

- I2S master for the six-microphone array — drives `SCK_MIC` and `WS`, reads
  three data lines
- Beamforming and direction-of-arrival estimation via the APU
- Spectrogram generation and acoustic event classification
- Reporting results to the ESP32-S3 over QSPI

The module accepts **5 V** and generates its own internal 1.8 V and 3.3 V rails.
Pins 53 and 54 are regulator *outputs*, not inputs.

The K210's FPIOA (Field Programmable IO Array) maps any peripheral function to
any of IO0–IO47 in firmware, so pin assignment was chosen for layout convenience
rather than fixed silicon constraints. Pins 56–71 (LCD_D0–7, DVP_D0–7) are
dedicated interfaces outside the FPIOA and are unused in this design.

### ESP32-S3 — System Host

**Responsibilities**

- Receiving detection results from the K210 over QSPI
- Driving the SX1262 LoRa radio over SPI
- Reading GNSS position and time from the MAX-M10S over UART
- Reading the MPU-9250 IMU over I2C for impact cross-validation
- Formatting and queueing GPS-tagged alerts for transmission
- USB enumeration, status indication, and power sequencing

Programming and debug use the **native USB Serial/JTAG controller** on GPIO19/20,
reached through port 1 of the CH334F hub. No external bridge is required for the
S3.

---

## Acoustic Sensing Subsystem

### Microphone Array

Six INMP441 digital I2S MEMS microphones in a fixed-geometry array. Each
microphone's `L/R` pin selects which half of a stereo frame it drives, allowing
two microphones to share one data line:

| Data line | K210 pin | Left (L/R → GND) | Right (L/R → 3V3) |
|---|---|---|---|
| `SD_1` | IO24 | U1 | U2 |
| `SD_2` | IO25 | U5 | U6 |
| `SD_3` | IO26 | U15 | U16 |

| Clock | K210 pin |
|---|---|
| `WS` (word select) | IO23 |
| `SCK_MIC` (bit clock) | IO27 |

All six microphones sample off a single shared bit clock, so every channel is
**phase-coherent by construction**. This is the property direction-of-arrival
estimation depends on, and it is why digital MEMS microphones were selected over
an analog array behind a multiplexed SAR ADC — a multiplexed converter samples
channels sequentially, injecting inter-channel skew directly into the timing
measurement the algorithm is trying to recover.

Each microphone has a local 0.1 µF decoupling capacitor and a 10 k pull-up on
`EN`.

### Direction-of-Arrival

Direction is recovered from **time difference of arrival** across the array: a
wavefront reaches each microphone at a slightly different instant, and the
inter-microphone delays determine the source angle. The K210's APU implements
this in hardware.

### Classification

A lightweight classifier distinguishes human distress signatures (tapping,
banging, shouting) from background noise, consuming spectrogram features
generated on the K210. The `gray8` library produces 8-bit palette-indexed
spectrogram images for training-data capture and offline inspection; the dB
window (`g8_scale_init`) is the dominant readability parameter.

---

## Wireless Communication Subsystem

An SX1262 LoRa transceiver driven by the ESP32-S3 over SPI.

| Signal | ESP32-S3 | SX1262 |
|---|---|---|
| `NSS` | GPIO4 | pin 15 |
| `SCK` | GPIO5 | pin 12 |
| `MOSI` | GPIO6 | pin 14 |
| `MISO` | GPIO7 | pin 13 |
| `BUSY` | GPIO9 | pin 10 |
| `DIO1` (IRQ) | GPIO10 | pin 6 |

The antenna path leaves via `ANT` (pin 1) through a matching network to coaxial
connector J4.

**Payload constraints.** LoRa is a low-bandwidth link. Only derived results cross
it — event class, confidence, bearing, GNSS fix and timestamp. Spectrograms and
raw audio are never transmitted; a full spectrogram BMP is roughly 51 KB and is
suitable only for local storage.

**Planned:** migration to a pre-certified LoRa module to simplify RF design and
regulatory compliance.

---

## Positioning Subsystem

A u-blox MAX-M10S GNSS receiver on UART to the ESP32-S3.

| Signal | GNSS | ESP32-S3 |
|---|---|---|
| GNSS TXD | pin 2 | GPIO16 |
| GNSS RXD | pin 3 | GPIO15 |

An active-antenna bias-T (L1 27 nH, R8 10 Ω) feeds `VCC_RF` from the antenna
node at coaxial connector J1.

**Available data:** latitude, longitude, altitude, UTC time, ground speed,
satellite count, fix status. GNSS time timestamps detected events; position
geotags them before transmission.

---

## Inertial Subsystem

An MPU-9250 9-axis IMU (accelerometer, gyroscope, magnetometer) in I2C mode —
`CS` is strapped to 3V3, with 2.2 k pull-ups on SDA and SCL.

Its role is cross-modal validation: an impact signature coincident with an
acoustic detection is far stronger evidence of a survivor tapping than either
alone. It also detects the node's own settling or displacement within the rubble.

---

## Storage Subsystem

A W25Q128JVS 128 Mbit QSPI flash on the ESP32-S3's dedicated SPI0 pins, with
series termination resistors (R15–R19) on the bus. Used for firmware,
configuration, OTA images, and model storage.

---

## USB Interface

A single USB Type-C receptacle feeds a CH334F hub, giving both processors
programming access over one physical connection without opening the enclosure.

| Hub port | Endpoint | Purpose |
|---|---|---|
| Port 1 | ESP32-S3 GPIO19/20 | Native USB — flash, serial, JTAG |
| Port 4 | CP2102N | Serial ISP for the K210 |

The K210 has no USB peripheral; it boots over serial, which is why the CP2102N
bridge exists. Type-C CC1/CC2 carry 5.1 k sink resistors; a USBLC6-4SC6 provides
ESD protection on the upstream data pair.

---

## Power Management

```text
USB-C VBUS ──▶ F2 (2 A polyfuse) ──▶ FB2 ──▶ D11 ──▶ +5V
                                    (ferrite)  (Schottky,
                                                reverse block)
                                                    │
                        ┌───────────────────────────┤
                        ▼                           ▼
                 AP63203WU buck              K210 module (5V in)
                        │
                        ▼
                      +3V3 ──▶ ESP32-S3, SX1262, MAX-M10S,
                               MPU-9250, flash, mic array
```

Local decoupling is placed at every subsystem, which matters given the mixed
digital/RF/analog nature of the board.

**Planned for the next revision**

- Li-Po connector, charge IC and protection, OR-ed into the system rail at D11
- Battery voltage monitoring via a divider into **ADC1** (GPIO1–GPIO10 only;
  ADC2 is unusable while Wi-Fi is active)
- 5 V boost from battery plus a load switch gating the K210, enabling duty-cycled
  operation — the K210 draws roughly 300–400 mW under load, so gating it is the
  difference between half a day and weeks of runtime
- RTC backup supply for GNSS warm starts

---

## Inter-Processor Link — QSPI

A six-wire quad SPI bus between the K210 and the ESP32-S3, ESD-protected on every
line (D15–D20).

| Signal | ESP32-S3 GPIO | S3 pin | K210 IO | M1 pin |
|---|---|---|---|---|
| `QSPI_CLK` | GPIO37 | 42 | IO36 | 37 |
| `QSPI_CS` | GPIO38 | 43 | IO37 | 38 |
| `QSPI_D0` | GPIO33 | 38 | IO32 | 33 |
| `QSPI_D1` | GPIO34 | 39 | IO33 | 34 |
| `QSPI_D2` | GPIO35 | 40 | IO34 | 35 |
| `QSPI_D3` | GPIO36 | 41 | IO35 | 36 |

**Direction: K210 is master, ESP32-S3 is slave.** The K210's SPI slave peripheral
supports standard mode only — it has no quad slave mode — so making the ESP32 the
master would silently degrade the link to a single data line. On the ESP32-S3
this requires **SPI Slave HD** (half-duplex) mode, which does support quad lines.
A handshake line should be added so the slave can signal data-ready rather than
being polled blind.

GPIO33–37 are the ESP32-S3's `SPIIO4`–`SPIIO7`/`SPIDQS` pins. They are free on a
bare die and on quad-PSRAM variants, but are consumed internally on **octal**
PSRAM variants (R8). The chosen variant must be confirmed before layout. Because
these pins belong to the flash/PSRAM controller, the link is driven by **SPI2
through the GPIO matrix**, not by the flash peripheral.

**No raw audio crosses this link.** The microphone array feeds the K210 directly,
so the bus carries only derived results.

---

## Known Open Items

Outstanding in the current schematic; all must be closed before layout.

| # | Item |
|---|---|
| 1 | K210 pins 53/54 (1V8 and 3V3 module **outputs**) are tied to rails already driven by U12 and U14 — two regulators output-to-output on each rail |
| 2 | No battery or charging block; `+5V` is USB-only, so the K210 cannot run untethered |
| 3 | The `RST` net is shared between LoRa reset, K210 reset and CP2102N RTS — no independent reset control, and opening a serial port resets the radio |
| 4 | CP2102N TXD / RXD / DTR are unconnected — the K210 cannot be flashed |
| 5 | GNSS `RF_IN` (U4.11) is unconnected; the bias-T feeds `VCC_RF` but no DC-blocked path reaches the receiver input |
| 6 | LoRa DIO2/DIO3 drive status LEDs — on most SX1262 modules DIO2 is RF-switch control and DIO3 is the TCXO supply |
| 7 | LoRa `TX_EN` / `RX_EN` are no-connect |
| 8 | IMU SDA/SCL never reach the ESP32-S3; `AD0` (address select) and `INT` are floating |
| 9 | Approximately 52 K210 pins lack no-connect flags, making ERC output unusable |
| 10 | GNSS UART nets are still named `C+` / `C-`, colliding with USB-C naming conventions |

---

## Mechanical

A custom enclosure protects the assembly during insertion into rubble while
allowing sound to reach the microphone ports with minimal attenuation or
reflection.

**Requirements**

- Acoustic ports aligned to all six microphone locations, sealed against dust and
  water without damping the acoustic path
- Clearance and keep-out for the GNSS and LoRa antennas
- Impact tolerance — the node is thrown or dropped into debris
- Ingress protection appropriate to a wet, dusty, unstable environment
- Mounting holes and board retention that survive shock loading

Mounting holes, mic port cutouts, and antenna keep-out regions must be placed
during PCB layout, not retrofitted afterwards.

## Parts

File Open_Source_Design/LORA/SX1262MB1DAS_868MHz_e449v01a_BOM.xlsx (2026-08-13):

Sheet: SX1262MB1DAS
 |  |  | SX1262MB1DAS RF Module - 4-Layers 868MHz BOM |  |  | BOM # V1a
 |  |  |  |  |  | SCH # e449v01a
 |  |  | 2023-09-25 | EMr | Version e449v01a | PCB # e449v01a
RefDes | MPN | Geom | Value | Qty | Description | Manufacturer
U1 | SX1262IMLTRT | VQFN24 4x4mm | SX1262 | 1 | 150MHz to 960MHz Low Power Long Range Transceiver | Semtech
U2 | PE4259 | SC70-6 | PE4259 | 1 | SPDT High Power UltraCMOS 10 MHz - 3.0 GHz RF Switch | Peregrine
Resistors
R2 | CRCW06030000Z0EAHP | 0603 | 0R | 1 | Thick Film Resistor ±1%, 1/4W | Vishay/Dale
R3 | CRCW0402100RFKED | 0402 | 100R | 1 | Thick Film Resistor ±1%, 1/16W | Vishay/Dale
R4 | CRCW0402100RFKED | 0402 | 100R | 1 | Thick Film Resistor ±1%, 1/16W | Vishay/Dale
R5 | CRCW0402220RJNED | 0402 | 220R | 1 | Thick Film Resistor ±5%, 1/16W | Vishay/Dale
R12 | CRCW04020000Z0ED | 0402 | 0R | 1 | Thick Film Resistor ±1%, 1/16W | Vishay/Dale
R13 | CRCW040210K0FKED | 0402 | 10k | 1 | Thick Film Resistor ±1%, 1/16W | Vishay/Dale
R15 | CRCW0402330RFKED | 0402 | 330R | 1 | Thick Film Resistor ±1%, 1/16W | Vishay/Dale
R16 | CRCW0402330RFKED | 0402 | 330R | 1 | Thick Film Resistor ±1%, 1/16W | Vishay/Dale
R18 | CRCW04020000Z0ED | 0402 | 0R | 1 | Thick Film Resistor ±1%, 1/16W - Configuration for SX1262 | Vishay/Dale
R868 | CRCW04020000Z0ED | 0402 | 0R | 1 | Thick Film Resistor ±1%, 1/16W | Vishay/Dale
SX1262 | CRCW040210K0FKED | 0402 | 10k | 1 | Thick Film Resistor ±1%, 1/16W | Vishay/Dale
FR0 | CRCW040210K0FKED | 0402 | 10k | 1 | Thick Film Resistor ±1%, 1/16W | Vishay/Dale
TCXO | CRCW04020000Z0ED | 0402 | 0R | 1 | Thick Film Resistor ±1%, 1/16W | Vishay/Dale
Capacitors
C1 | GRM155R71C473KA01D | 0402 | 47nF | 1 | Multilayer ceramic capacitors X7R ±10%, 16V | Murata
C2 | GJM1555C1H470JB01D | 0402 | 47pF | 1 | Multilayer ceramic capacitors C0G ±5%, 50V | Murata
C4 | GJM1555C1H3R3BB01D | 0402 | 3.3pF | 1 | Multilayer ceramic capacitors C0G ±0.1pF, 50V | Murata
C5 | GJM1555C1H5R6CB01D | 0402 | 5.6pF | 1 | Multilayer ceramic capacitors C0G ±0.25pF, 50V | Murata
C6 | GJM1555C1H390JB01D | 0402 | 39pF | 1 | Multilayer ceramic capacitors C0G ±5%, 50V | Murata
C7 | GJM1555C1H2R2BB01D | 0402 | 2.2pF | 1 | Multilayer ceramic capacitors C0G ±0.1pF, 50V | Murata
C8 | GJM1555C1H390JB01D | 0402 | 39pF | 1 | Multilayer ceramic capacitors C0G ±5%, 50V | Murata
C9 | GJM1555C1H3R3BB01D | 0402 | 3.3pF | 1 | Multilayer ceramic capacitors C0G ±0.1pF, 50V | Murata
C10 | GJM1555C1H3R3BB01D | 0402 | 3.3pF | 1 | Multilayer ceramic capacitors C0G ±0.1pF, 50V | Murata
C11 | GJM1555C1H2R4BB01D | 0402 | 2.4pF | 1 | Multilayer ceramic capacitors C0G ±0.1pF, 50V | Murata
C12 | GJM1555C1H1R8BB01D | 0402 | 1.8pF | 1 | Multilayer ceramic capacitors C0G ±0.1pF, 50V | Murata
C14 | GRM155R72A102KA01D | 0402 | 1nF | 1 | Multilayer ceramic capacitors X7R ±10%, 100V | Murata
C15 | GRM155R72A102KA01D | 0402 | 1nF | 1 | Multilayer ceramic capacitors X7R ±10%, 100V | Murata
C16 | GRM155R61C105KA12D | 0402 | 1uF | 1 | Multilayer ceramic capacitors X5R ±10%, 16V | Murata
C17 | GRM155R71A474KE01D | 0402 | 470nF | 1 | Multilayer ceramic capacitors X7R ±10%, 10V | Murata
C18 | GRM155R71H104KE14D | 0402 | 100nF | 1 | Multilayer ceramic capacitors X7R ±10%, 50V | Murata
C20 | GRM155R61C105KA12D | 0402 (0603) | 1uF | 1 | Multilayer ceramic capacitors X5R ±10%, 16V | Murata
C21 | GRM155R61C105KA12D | 0402 (0603) | 1uF | 1 | Multilayer ceramic capacitors X5R ±10%, 16V | Murata
C22 | GRM188Z71A106KA73D | 0603 (0805) | 10uF | 1 | Multilayer ceramic capacitors X7R ±10%, 10V | Murata
C23 | GRM155R71H104KE14D | 0402 | 100nF | 1 | Multilayer ceramic capacitors X7R ±10%, 50V | Murata
C24 | GRM155R61C105KA12D | 0402 | 1uF | 1 | Multilayer ceramic capacitors X5R ±10%, 16V | Murata
C26 | GRM188Z71A106KA73D | 0603 (0805) | 10uF | 1 | Multilayer ceramic capacitors X7R ±10%, 10V | Murata
C27 | GJM1555C1H100JB01D | 0402 | 10pF | 1 | Multilayer ceramic capacitors C0G ±5%, 50V | Murata
C28 | GRM155R71H104KE14D | 0402 | 100nF | 1 | Multilayer ceramic capacitors X7R ±10%, 50V | Murata
Inductors & Ferrites
L1 | LQW15AN47NJ00D | 0402 | 47nH | 1 | Wirewound Inductor ±5% | Murata
L2 | CRCW04020000Z0ED | 0402 | 0R | 1 | Thick Film Resistor ±1%, 1/16W | Vishay/Dale
L3 | LQW15AN2N5C00D | 0402 | 2.5nH | 1 | Wirewound Inductor ±0.2nH | Murata
L4 | LQW15AN4N7C00D | 0402 | 4.7nH | 1 | Wirewound Inductor ±0.2nH | Murata
L5 | LQW15AN9N1H00D | 0402 | 9.1nH | 1 | Wirewound Inductor ±3% | Murata
L6 | LQW15AN15NH00D | 0402 | 15nH | 1 | Wirewound Inductor ±3% | Murata
L7 | MLZ2012M150W | 0805 | 15uH | 1 | MLZ2012 Multilayer Shielded Inductor ±20% (populated) | TDK
or | MLZ1608N100LT000 | 0603 (0805) | 10uH | - | MLZ1608 Multilayer Shielded Inductor ±20% (recommended for new design) | TDK
or | MLZ1608N150LT000 | 0603 (0805) | 15uH | - | MLZ1608 Multilayer Shielded Inductor ±20% (recommended for new design) | TDK
FB1 | BLM15PG100SN1D | 0402 | 10R @100MHz | 1 | Ferrite Bead 1A | Murata
LEDs and Diodes
Rx | LTST-C193KGKT-5A | SMT 1.6x0.8mm | GREEN | 1 | SMD LED 20mA or equivalent LED type | Lite ON
Tx | LTST-C193KRKT-5A | SMT 1.6x0.8mm | RED | 1 | SMD LED 20mA or equivalent LED type | Lite ON
Crystal & TCXO
Q2 | NT2016SF 32MHz END4263D | 2.0x1.6mm | 32.000MHz | - | 32.000MHz TCXO - NDK Reference: END4263D (new reference) | NDK
or | RST2016N | 2.0x1.6mm | 32.000MHz | - | 32.000MHz TCXO - Rakon Reference: T6393 (new reference) | Rakon
Connectors and others (or P/N equivalent)
RFIO | 142-0701-841 | SMA End Launch | 50 Ohms | 1 | SMA End launch jack receptacle for PCB mount | Cinch Connectivity Sol Johnson
J1 | 68000-108HLF | Header 1x8 | 8 pins | 1 | 8 Pins - Through hole single row male connector, Bottom side | FCI
J2 | 68000-110HLF | Header 1x10 | 10 pins | 1 | 10 Pins - Through hole single row male connector, Bottom side | FCI
J3 | 68000-108HLF | Header 1x8 | 8 pins | 1 | 8 Pins - Through hole single row male connector, Bottom side | FCI
J4 | 68000-106HLF | Header 1x6 | 6 pins | 1 | 6 Pins - Through hole single row male connector, Bottom side | FCI
J1_DISP | 75915-308LF | Receptacle 1x8 | 8 pins | 1 | 8 Pins - Through hole single row female receptacle, Top side | FCI
J2_DISP | 75915-310LF | Receptacle 1x10 | 10 pins | 1 | 10 Pins - Through hole single row female receptacle, Top side | FCI
J3_DISP | 75915-308LF | Receptacle 1x8 | 8 pins | 1 | 8 Pins - Through hole single row female receptacle, Top side | FCI
J4_DISP | 75915-306LF | Receptacle 1x6 | 6 pins | 1 | 6 Pins - Through hole single row female receptacle, Top side | FCI
VDD_RADIO | 68000-102HLF | Bridge 2p 2.54mm | 2 pins | 1 | 2 Pins - Through hole single row male connector, Top side | FCI
Additional or optional components
- | M7566-05 | Jumper 2.54mm | - | 1 | Red Jumper Socket 2.54mm on VDD_RADIO for DC supply or equivalent | Harwin
- | BMI-S-209-F | Shield | - | 0 | Standard Surface Mount Shield in two parts with BMI-S-209-C cover (optional) | Laird Technologies
Remarks: components not listed in the BOM or 0 quantity, are not populated on the module.
It is recommended to use Semtech TVS diode model RClamp2451ZA placed close to the antenna connectors, to protect sensitive RF ports from damage or latch-up due to ESD, EFT, and EOS.
Murata GRM15 Multilayer ceramic capacitors series with values ≤ 47pF were replaced from previous BOM to new GJM15 series, as replacement with same capacitance value, voltage rating and tolerance.
GRM15 series ≤ 47pF are not recommended for new designs according to Murata.

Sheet: Release
 |  | SX1262MB1DAS RF Module - 4-Layers 868MHz BOM |  |  |  | BOM # V1a
 |  |  |  |  |  | SCH # e449v01a
 |  | 2023-09-25 | EMr | Version e449v01a |  | PCB # e449v01a
Release history
Version | Change notes |  |  |  | By
pcb_e449v01a | Based on PCB_E428V03A BOM version - SX1262 module - 4-layers with TCXO only |  |  |  | EMr
 | Updated BOM for 868 Operations only
 | Changed R868 (instead of R915) and FR0 for 868MHz freq band - 22.03.18 |  |  |  | EMr
 | Updated obsolete P/N for large capacitor values (>1.0uF) |  |  |  | EMr
 | Updated GJM capacitor type |  |  |  | 2023-09-25

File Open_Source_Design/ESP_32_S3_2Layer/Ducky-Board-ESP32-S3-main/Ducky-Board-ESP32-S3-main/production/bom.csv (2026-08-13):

Designator | Footprint | Quantity | Value | LCSC Part #
+3V3 | TestPoint_Pad_D1.0mm | 1 | +3V3
AE1 | Texas_SWRA117D_2.4GHz_Left | 1 | Antenna
BTN1 | SW_Push_1P1T_XKB_TS-1187A | 1 | BTN
C10, C11, C15, C18, C19, C22, C32, C35 | 0402 | 8 | 0.1uF
C13, C26, C39 | 0402 | 3 | 1uF
C16, C17, C2, C20, C25, C3, C36, C6, C7, C8 | 0402 | 10 | 10uF
C31, DNP1 | 0402 | 2 | 15pF
C33, C37, C38, C4 | 0402 | 4 | 12pF
C40 | 0402 | 1 | 10nF
D1, D2, D3 | 0603 | 3 | LED
D4 | D_SMA | 1 | SS14
FLASH1 | SW_Push_1P1T_XKB_TS-1187A | 1 | Flash
GND1 | TestPoint_Pad_D1.0mm | 1 | GND
J1 | USB_C_Receptacle_HCTL_HC-TYPE-C-16P-01A | 1 | USB_C_Receptacle_USB2.0_14P
J2 | PinSocket_1x02_P2.54mm_Vertical | 1 | Conn_01x02_Pin
J3, J5 | PinHeader_1x18_P2.54mm_Vertical | 2 | Conn_01x18_Pin
L3 | 0402 | 1 | 2nH
L6 | 0402 | 1 | 4.7nH
Q1 | SOT-23 | 1 | AO3401A
R1 | 0402 | 1 | 2K
R12, R19 | 0402 | 2 | 200K
R14, R17 | 0402 | 2 | 5.1K
R15 | 0402 | 1 | 1K
R16, R24, R25 | 0402 | 3 | 470R
R18, R2 | 0402 | 2 | 33R
R20 | 0402 | 1 | 100K
R21, R22, R4 | 0402 | 3 | 10K
R23, R26, R27, R28, R29, R30 | 0402 | 6 | 0R
RESET1 | SW_Push_1P1T_XKB_TS-1187A | 1 | Reset
U1 | QFN-56-1EP_7x7mm_P0.4mm_EP4x4mm | 1 | ESP32-S3
U2 | SOIC-8_5.3x5.3mm_P1.27mm | 1 | W25Q128JVS
U3 | SOT-23-5 | 1 | MCP73831-2-OT
U4 | SOT-223-3_TabPin2 | 1 | AMS1117-3.3
Y1 | Crystal_SMD_3215-2Pin_3.2x1.5mm | 1 | 32.768 kHz
Y2 | Crystal_SMD_2520-4Pin_2.5x2.0mm | 1 | 40MHz(10ppm)

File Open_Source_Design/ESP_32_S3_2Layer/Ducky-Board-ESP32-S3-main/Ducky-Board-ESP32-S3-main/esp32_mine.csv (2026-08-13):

Reference | Qty | Value | DNP | Footprint | Datasheet | MNF PART NUMBER | LCSC Part #
+3V3 | 1 | +3V3 |  | TestPoint:TestPoint_Pad_D1.0mm | ~
AE1 | 1 | Antenna |  | RF_Antenna:Texas_SWRA117D_2.4GHz_Left | ~
C14 | 1 | DNP |  | Capacitor_SMD:C_0402_1005Metric | ~
GND1 | 1 | GND |  | TestPoint:TestPoint_Pad_D1.0mm | ~
J2 | 1 | Conn_01x02_Pin |  | Connector_PinSocket_2.54mm:PinSocket_1x02_P2.54mm_Vertical | ~
J3,J5 | 2 | Conn_01x18_Pin |  | Connector_PinHeader_2.54mm:PinHeader_1x18_P2.54mm_Vertical | ~
L5 | 1 | DNP |  | Inductor_SMD:L_0402_1005Metric | ~
R31 | 1 | DNP |  | Resistor_SMD:R_0402_1005Metric | ~ | 1 | 1
C10,C11,C15,C18,C19,C22,C32,C35 | 8 | 0.1uF |  | Capacitor_SMD:C_0402_1005Metric | ~ | C1525 | C1525
C4,C33,C37,C38 | 4 | 12pF |  | Capacitor_SMD:C_0402_1005Metric | ~ | C1547 | C1547
C31,DNP1 | 2 | 15pF |  | Capacitor_SMD:C_0402_1005Metric | ~ | C1548 | C1548
D1,D2,D3 | 3 | LED |  | LED_SMD:LED_0603_1608Metric | ~ | C2286 | C2286
D4 | 1 | SS14 |  | Diode_SMD:D_SMA | https://www.vishay.com/docs/88746/ss12.pdf | C2480 | C2480
R1 | 1 | 2K |  | Resistor_SMD:R_0402_1005Metric | ~ | C4109 | C4109
U4 | 1 | AMS1117-3.3 |  | Package_TO_SOT_SMD:SOT-223-3_TabPin2 | http://www.advanced-monolithic.com/pdf/ds1117.pdf | C6186 | C6186
R15 | 1 | 1K |  | Resistor_SMD:R_0402_1005Metric | ~ | C11702 | C11702
L6 | 1 | 4.7nH |  | Inductor_SMD:L_0402_1005Metric | ~ | C13595 | C13595
Q1 | 1 | AO3401A |  | Package_TO_SOT_SMD:SOT-23 | http://www.aosmd.com/pdfs/datasheet/AO3401A.pdf | C15127 | C15127
C40 | 1 | 10nF |  | Capacitor_SMD:C_0402_1005Metric | ~ | C15195 | C15195
C2,C3,C6,C7,C8,C16,C17,C20,C25,C36 | 10 | 10uF |  | Capacitor_SMD:C_0402_1005Metric | ~ | C15525 | C15525
R23,R26,R27,R28,R29,R30 | 6 | 0R |  | Resistor_SMD:R_0402_1005Metric | ~ | C17168 | C17168
R2,R18 | 2 | 33R |  | Resistor_SMD:R_0402_1005Metric | ~ | C25105 | C25105
R16,R24,R25 | 3 | 470R |  | Resistor_SMD:R_0402_1005Metric | ~ | C25117 | C25117
R20 | 1 | 100K |  | Resistor_SMD:R_0402_1005Metric | ~ | C25741 | C25741
R4,R21,R22 | 3 | 10K |  | Resistor_SMD:R_0402_1005Metric | ~ | C25744 | C25744
R12,R19 | 2 | 200K |  | Resistor_SMD:R_0402_1005Metric | ~ | C25764 | C25764
R14,R17 | 2 | 5.1K |  | Resistor_SMD:R_0402_1005Metric | ~ | C25905 | C25905
Y1 | 1 | 32.768 kHz |  | Crystal:Crystal_SMD_3215-2Pin_3.2x1.5mm | ~ | C32346 | C32346
C13,C26,C39 | 3 | 1uF |  | Capacitor_SMD:C_0402_1005Metric | ~ | C52923 | C52923
L3 | 1 | 2nH |  | Inductor_SMD:L_0402_1005Metric | ~ | C77103 | C77103
U2 | 1 | W25Q128JVS |  | Package_SO:SOIC-8_5.3x5.3mm_P1.27mm | https://www.winbond.com/resource-files/w25q128jv_dtr%20revc%2003272018%20plus.pdf | C97521 | C97521
BTN1 | 1 | BTN |  | Button_Switch_SMD:SW_Push_1P1T_XKB_TS-1187A | ~ | C318884 | C318884
Flash1 | 1 | Flash |  | Button_Switch_SMD:SW_Push_1P1T_XKB_TS-1187A | ~ | C318884 | C318884
Reset1 | 1 | Reset |  | Button_Switch_SMD:SW_Push_1P1T_XKB_TS-1187A | ~ | C318884 | C318884
U1 | 1 | ESP32-S3 |  | Package_DFN_QFN:QFN-56-1EP_7x7mm_P0.4mm_EP4x4mm | https://www.espressif.com/sites/default/files/documentation/esp32-s3_datasheet_en.pdf | C2913196 | C2913196
Y2 | 1 | 40MHz(10ppm) |  | Crystal:Crystal_SMD_2520-4Pin_2.5x2.0mm | ~ | C5261125 | C5261125
U3 | 1 | MCP73831-2-OT |  | Package_TO_SOT_SMD:SOT-23-5 | http://ww1.microchip.com/downloads/en/DeviceDoc/20001984g.pdf | C7472804 | C7472804
J1 | 1 | USB_C_Receptacle_USB2.0_14P |  | Connector_USB:USB_C_Receptacle_HCTL_HC-TYPE-C-16P-01A | https://www.usb.org/sites/default/files/documents/usb_type-c.zip | C19274016 | C19274016

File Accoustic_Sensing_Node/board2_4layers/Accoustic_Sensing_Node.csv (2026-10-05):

Reference | Qty | Value | DNP | Exclude from BOM | Exclude from Board | Footprint | Datasheet
C1,C2,C10,C11,C16,C17,C18,C19,C20,C22,C24,C30,C31,C33,C52,C53,C54,C56,C60 | 19 | 0.1uF |  |  |  | Capacitor_SMD:C_0402_1005Metric | ~
C3,C5,C8,C21,C42 | 5 | 100nF |  |  |  | Capacitor_SMD:C_0603_1608Metric | ~
C4,C6,C13,C34,C39,C50 | 6 | 10uF |  |  |  | Capacitor_SMD:C_0603_1608Metric | ~
C7,C15,C51 | 3 | 1uF |  |  |  | Capacitor_SMD:C_0402_1005Metric | ~
C9,C29 | 2 | 10nF |  |  |  | Capacitor_SMD:C_0603_1608Metric | ~
C12,C14 | 2 | 18pF |  |  |  | Capacitor_SMD:C_0402_1005Metric | ~
C23 | 1 | 10nF |  |  |  | Capacitor_SMD:C_0402_1005Metric | ~
C25,C26,C32 | 3 | 1uF |  |  |  | Capacitor_SMD:C_0603_1608Metric | ~
C27,C28 | 2 | 100nF |  |  |  | Capacitor_SMD:C_0402_1005Metric | ~
C35 | 1 | 33pF |  |  |  | Capacitor_SMD:C_0402_1005Metric | ~
C36 | 1 | 22uF |  |  |  | Capacitor_SMD:C_0603_1608Metric | ~
C38 | 1 | 100n |  |  |  | Capacitor_SMD:C_0402_1005Metric | ~
C40,C41 | 2 | 12pF |  |  |  | Capacitor_SMD:C_0402_1005Metric | ~
C43,C44 | 2 | 22u |  |  |  | Capacitor_SMD:C_0603_1608Metric | ~
C55 | 1 | 4.7uF |  |  |  | Capacitor_SMD:C_0603_1608Metric | ~
C57,C58,C61,C62 | 4 | 1.5pF |  |  |  | Capacitor_SMD:C_0402_1005Metric | ~
C59,C63 | 2 | 1uF | DNP |  |  | Capacitor_SMD:C_0603_1608Metric | ~
CH334F1 | 1 | ~ |  |  |  | USB_HUB:QFN24_4MM
D1,D2,D4,D5,D7,D8,D12,D14,D17,D18,D19,D20,D21 | 13 | ESD3.3 |  |  |  | Diode_SMD:SODFL1006X40N | https://www.onsemi.com/pub/Collateral/ESD9B-D.PDF
D3 | 1 | Power |  |  |  | LED_SMD:LED_0805_2012Metric | ~
D6 | 1 | UART1_ON |  |  |  | LED_SMD:LED_0805_2012Metric | ~
D9 | 1 | USB1 |  |  |  | LED_SMD:LED_0805_2012Metric | ~
D10 | 1 | USB2 |  |  |  | LED_SMD:LED_0805_2012Metric | ~
D11 | 1 | PMEG4020EP |  |  |  | Diode_SMD:D_SOD-123F | http://www.vishay.com/docs/88946/b120.pdf
D13 | 1 | ESD5 |  |  |  | Diode_SMD:SODFL1006X40N | https://www.onsemi.com/pub/Collateral/ESD9B-D.PDF
F2 | 1 | Polyfuse 2A |  |  |  | Fuse:Fuse_1206_3216Metric | ~
FB2 | 1 | BLM21PG220 |  |  |  | Inductor_SMD:L_0805_2012Metric | ~
J1 | 1 | Conn_Coaxial |  |  |  |  | ~
J2,J4 | 2 | Conn_Coaxial |  |  |  | Connector_Coaxial:SMA_Amphenol_132289_EdgeMount | ~
J3 | 1 | USB_C_Receptacle_USB2.0_16P |  |  |  | Connector_USB:USB_C_Receptacle_HCTL_HC-TYPE-C-16P-01A | https://www.usb.org/sites/default/files/documents/usb_type-c.zip
L1 | 1 | 27nH |  |  |  | Inductor_SMD:L_0402_1005Metric | ~
L2,L3,L5 | 3 | 2nH |  |  |  | Inductor_SMD:L_0402_1005Metric | ~
L4 | 1 | 4.7uH |  |  |  | Inductor_SMD:L_Coilcraft_XAL4030-XXX | ~
L6,L7 | 2 | 2nH | DNP |  |  | Inductor_SMD:L_0402_1005Metric | ~
R1,R2,R6,R7,R9,R10,R12,R20,R23,R27,R31,R32,R33,R34,R35 | 15 | 10k |  |  |  | Resistor_SMD:R_0402_1005Metric | ~
R3,R4,R36,R37,R38,R39,R40,R41,R42 | 9 | 100 Ohms |  |  |  | Resistor_SMD:R_0402_1005Metric | ~
R5 | 1 | 1k |  |  |  | Resistor_SMD:R_0402_1005Metric | ~
R8 | 1 | 10Ohm |  |  |  | Resistor_SMD:R_0805_2012Metric | ~
R11 | 1 | 0 Ohms |  |  |  | Resistor_SMD:R_0402_1005Metric | ~
R13 | 1 | 1K |  |  |  | Resistor_SMD:R_0402_1005Metric | ~
R14,R24,R25 | 3 | 470 Ohm |  |  |  | Resistor_SMD:R_0402_1005Metric | ~
R15,R16,R17,R18,R19 | 5 | 0kOhm |  |  |  | Resistor_SMD:R_0402_1005Metric | ~
R21,R22 | 2 | 2.2K |  |  |  | Resistor_SMD:R_0402_1005Metric | ~
R26 | 1 | 10k | DNP |  |  | Resistor_SMD:R_0402_1005Metric | ~
R28,R29 | 2 | 5.1k |  |  |  | Resistor_SMD:R_0402_1005Metric | ~
R30 | 1 | 0 Ohm |  |  |  | Resistor_SMD:R_0402_1005Metric | ~
SW1 | 1 | BOOT |  |  |  | Button_Switch_SMD:SW_CS1213AGF260_CRS | ~
SW2,SW3 | 2 | Reset |  |  |  | Button_Switch_SMD:SW_CS1213AGF260_CRS | ~
SW4 | 1 | Boot |  |  |  | Button_Switch_SMD:SW_CS1213AGF260_CRS | ~
U1 | 1 | MIC1 |  |  |  | Mic:INMP441
U2 | 1 | MIC3 |  |  |  | Mic:INMP441
U3 | 1 | SX1262 |  |  |  | LORA:SX1262-B
U4 | 1 | MAX-M10S |  |  |  | RF_GPS:ublox_MAX | https://content.u-blox.com/sites/default/files/MAX-M10S_DataSheet_UBX-20035208.pdf
U5,U15 | 2 | MIC2 |  |  |  | Mic:INMP441
U6,U16 | 2 | MIC4 |  |  |  | Mic:INMP441
U7 | 1 | W25Q128JVS |  |  |  | Package_SO:SOIC-8_5.3x5.3mm_P1.27mm | https://www.winbond.com/resource-files/w25q128jv_dtr%20revc%2003272018%20plus.pdf
U8 | 1 | ESP32-S3 |  |  |  | Package_DFN_QFN:QFN-56-1EP_7x7mm_P0.4mm_EP4x4mm | https://www.espressif.com/sites/default/files/documentation/esp32-s3_datasheet_en.pdf
U9 | 1 | Sipeed-M1 |  |  |  | Module:Sipeed-M1 | https://dl.sipeed.com/MAIX/HDK/Sipeed-M1&M1W/Specifications
U10 | 1 | MPU-9250 |  |  |  | Sensor_Motion:InvenSense_QFN-24_3x3mm_P0.4mm | https://invensense.tdk.com/wp-content/uploads/2015/02/PS-MPU-9250A-01-v1.1.pdf
U11 | 1 | CP2102N-Axx-xQFN28 |  |  |  | Package_DFN_QFN:QFN-28-1EP_5x5mm_P0.5mm_EP3.35x3.35mm | https://www.silabs.com/documents/public/data-sheets/cp2102n-datasheet.pdf
U13 | 1 | USBLC6-4SC6 |  |  |  | Package_TO_SOT_SMD:SOT-23-6 | https://www.st.com/resource/en/datasheet/usblc6-4.pdf
U14 | 1 | AP63203WU |  |  |  | Package_TO_SOT_SMD:TSOT-23-6 | https://www.diodes.com/assets/Datasheets/AP63200-AP63201-AP63203-AP63205.pdf
Y1 | 1 | 40MHz |  |  |  | Crystal:Crystal_SMD_3225-4Pin_3.2x2.5mm | ~
Y2 | 1 | 12MHz |  |  |  | Crystal:Crystal_SMD_3225-4Pin_3.2x2.5mm | ~

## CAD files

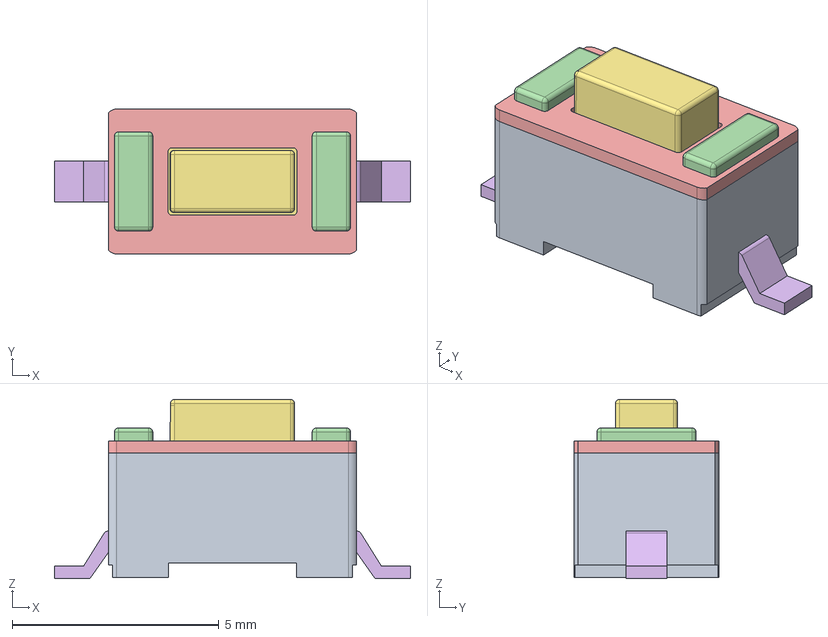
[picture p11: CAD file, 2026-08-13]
Assets/3dmodels/Button.stp
8.60 x 3.50 x 4.33 mm
PTS636SM43SMTRLFS_PART1
PTS636SM43SMTRLFS_PART2
PTS636SM43SMTRLFS_PART3
PTS636SM43SMTRLFS_PART4
PTS636SM43SMTRLFS_PART5
PTS636SM43SMTRLFS_PART6
PTS636SM43SMTRLFS_PART7
PTS636SM43SMTRLFS_PART8
PTS636SM43SMTRLFS_PART9
PTS636SM43SMTRLFS_PART10

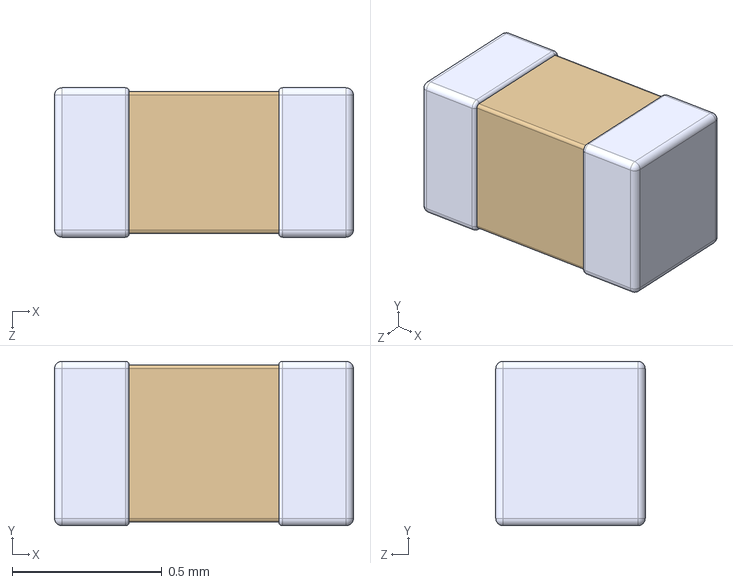
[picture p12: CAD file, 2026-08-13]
Assets/3dmodels/Polyfuse.step
1.00 x 0.55 x 0.5 mm

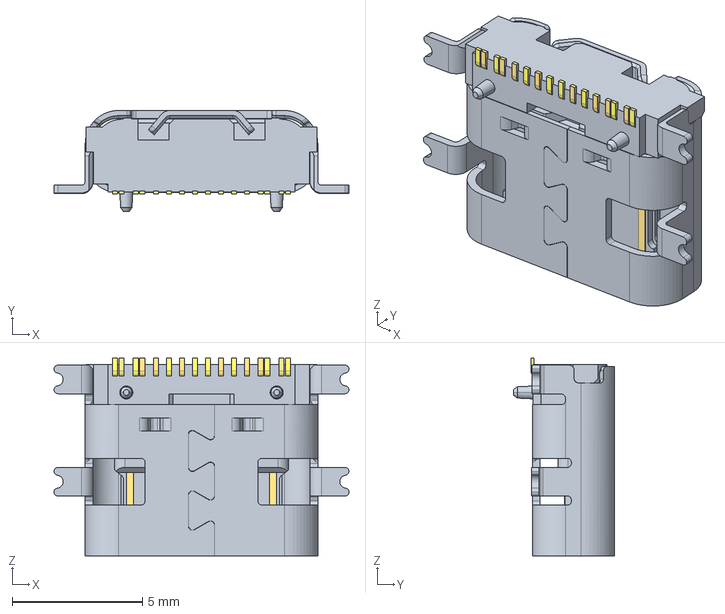
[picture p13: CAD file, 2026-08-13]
Assets/3dmodels/USB_C.stp
11.3 x 3.89 x 7.60 mm

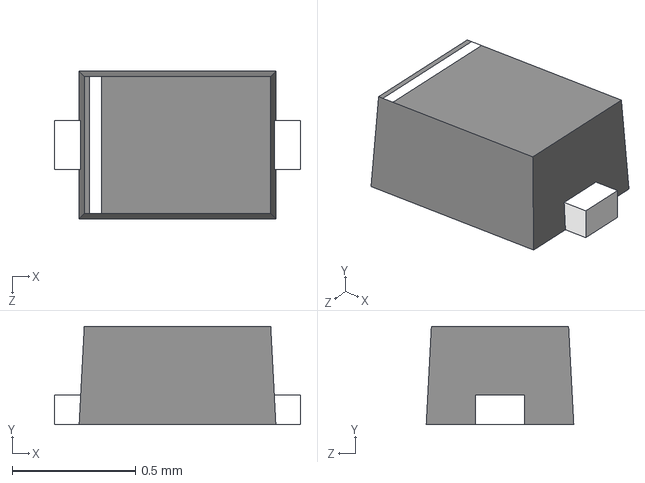
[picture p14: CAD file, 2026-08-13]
Assets/3dmodels/ESD.step
1 x 0.4 x 0.6 mm

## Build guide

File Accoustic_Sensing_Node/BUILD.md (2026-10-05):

# Build and run, step by step

Two firmware projects share one SDK tree. Pick one with `-DPROJ=`.

| project | what it does | when |
|---|---|---|
| `Recorder` | probes the mics, streams ONE at a time to the PC | wiring checks, dataset collection |
| `Detector` | 4 mics simultaneously, VAD + DOA on device, sends 16-byte results | the actual system |

---

## 0. One-time setup

```
pip install -r requirements.txt
```

Toolchain at `C:\Code\Cmake\kendryte-toolchain\bin` (adjust paths below to match).
Adding that folder to PATH saves typing `-DTOOLCHAIN` every time.

---

## 1. Verify the microphones — `Recorder`

Skip this only if all four slots have already passed.

```
cd Recording_Via_IOT_Devices\firmware\K210
rmdir /s /q build
mkdir build
cd build
cmake .. -DPROJ=Recorder -G "Unix Makefiles" -DTOOLCHAIN=C:/Code/Cmake/kendryte-toolchain/bin
C:\Code\Cmake\kendryte-toolchain\bin\make.exe
kflash -p COM12 -b 1500000 Main.bin
```

Press the board's reset button after flashing — kflash leaves it in ISP mode,
where it sends nothing and a capture reads zero bytes forever.

```
python -m serial.tools.miniterm COM12 1500000
```

Read, in this order:

1. `#i2s rate=15986 OK` — if this is bad, nothing below it means anything.
2. `#shift` table — pick the **smallest** `sh` with `clip=0` on **every** slot,
   set `SAMPLE_SHIFT`, rebuild.
3. `#stat` lines — tap each mic. Each slot must respond to **its own** mic.

| verdict | meaning |
|---|---|
| both slots move together | reading one mic twice — L/R strapping fault |
| `FLOATING/RANDOM` | nothing driving that half-frame |
| `CLIPPING` | raise `SAMPLE_SHIFT` |
| `UNDRIVEN` | no clock, no power, or wrong pin |

Keys while it runs: `0`–`3` lock to one mic, `c` cycle, `p` stats, `?` help.

**Do not continue until all four slots respond independently.** A wrong slot
map gives a confident bearing rotated by an unknown amount, and nothing on
screen will hint at it.

---

## 2. Collect a dataset — still `Recorder`

```
cd ..\..\..\..
python capstone.py record --device k210 --port COM12 --label speech ^
  --minutes 2 --speaker 1 --room lab --set 1 --distance 2m
python capstone.py record --device k210 --port COM12 --label non_speech ^
  --minutes 2 --speaker 1 --room lab --set 1 --distance 2m
```

Alternate the two **without touching the mic, gain or position**. Watch the
`dropped=` counter: if it climbs, the recording is not trustworthy.

---

## 3. Check the dataset — the gate

```
python capstone.py qc
```

The confound probe at the bottom trains on background noise only, with
speech removed and level divided out. **It must come back under 0.65.**
Above 0.80 means your two classes differ by recording conditions rather
than by speech, and every number after that is fiction.

---

## 4. Train and export

```
python capstone.py train
python capstone.py train-corpus --budget 6000     (optional, needs Public_Dataset)
python ML\export_to_c_header.py --model ML\vad3_model.joblib ^
       --out Recording_Via_IOT_Devices\firmware\K210\src\Detector\vad3_model.h
```

`features3.py` is at `FEATURE_VERSION = 4`. If you change it, delete
`feature_cache`, retrain, and regenerate the header — otherwise the weights
describe features the device no longer computes.

---

## 5. Build the detector

Set the slot map in `src/Detector/main_detector.c` from what step 1 showed:

```c
#define MIC_EAST   0
#define MIC_WEST   1
#define MIC_NORTH  2
#define MIC_SOUTH  3
#define SAMPLE_SHIFT 13
```

East/West must be one opposing pair, North/South the other, and **both
baselines equal** — the bearing comes from a ratio of two delays, so the
absolute 40 mm cancels but a mismatch between the axes does not.

```
cd Recording_Via_IOT_Devices\firmware\K210
rmdir /s /q build
mkdir build
cd build
cmake .. -DPROJ=Detector -G "Unix Makefiles" -DTOOLCHAIN=C:/Code/Cmake/kendryte-toolchain/bin
C:\Code\Cmake\kendryte-toolchain\bin\make.exe
kflash -p COM12 -b 1500000 Main.bin
```

Delete `build` between switching projects. A stale `CMakeCache.txt` pins the
old `PROJ` and will happily rebuild and flash the wrong firmware.

---

## 6. Read the output

```
python -m serial.tools.miniterm COM12 1500000
```

16-byte packets, `5A A5 10 seq | angle×10 | conf×1000 | score×100 | level×10 |
speech | warm | xor | pad`.

`warm=0` for the first ~8 s while the noise floor fills — scores before that
are not trustworthy. `angle=-1` means no confident bearing.

---

## What to expect

| | |
|---|---|
| bearing accuracy | 2–3° at broadside, 5–12 dB SNR |
| worst case | 45° diagonals, ~6° |
| near endfire | degrades sharply — sensitivity is `(d/c)·sin θ` |
| CPU | under 2% of a 400 MHz core |

Beamforming is **not** included and is not worth building at this size: the
array spans 57 mm diagonally, which at 1 kHz is 0.17 of a wavelength. Delay-
and-sum would sum four nearly identical signals — 6 dB of noise averaging,
no directivity. Call it 4-channel averaging if you use it at all.

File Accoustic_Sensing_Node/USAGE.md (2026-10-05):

# Acoustic Survivor Detection

Detecting trapped people by sound, on a K210 at the edge. Four INMP441
microphones in a 40 mm square: a three-feature voice detector decides
*whether* someone is there, and GCC-PHAT time-difference-of-arrival decides
*which direction*. No audio leaves the device — just a 16-byte result packet.

---

## Why three features and not fifty-two

An earlier version of this project used 52 features. An ablation showed the
two largest-weighted ones could be deleted at a cost of 0.001 — they were
collinear with features already present. More features mostly bought more
ways to be wrong, and every one is another thing to reimplement in C and
verify for numerical parity.

| feature | question it answers | why it earns its place |
|---|---|---|
| `harmonicity` | does the waveform repeat? | a voice is periodic; a door slam and a packet header are not |
| `voice_band_ratio` | is the energy at 300–3400 Hz? | rejects hum, rumble and wind |
| `snr_db` | is it above this room's background? | ignores what is too quiet to matter |

All three are ratios, so microphone gain cancels. All three are a short loop
in C. `ML/features3.py` explains each one line by line with a note on what
the C version looks like.

The model is logistic regression: three weights, one bias, one dot product.
`ML/export_to_c_header.py` folds the scaler into the weights and emits
`vad3_model.h`, so the device does no normalisation at all.

---

## What the array can and cannot do

40 mm spacing at 16 kHz gives a maximum delay of **1.87 samples** across one
axis. Integer-lag correlation would give four distinguishable values in
total, so sub-sample interpolation is the entire mechanism, not a
refinement.

Simulated GCC-PHAT accuracy, 64 ms windows, 300–3400 Hz:

| SNR | delay RMSE | bearing RMSE at broadside |
|---|---|---|
| 20 dB | 0.020 samples | 0.6° |
| 10 dB | 0.055 | 1.7° |
| 5 dB | 0.102 | 3.1° |
| 0 dB | 0.226 | 6.9° |

Measured across nine known bearings at 10 dB: **mean error 2.6°**, worst at
the 45° diagonals where both axes work at reduced sensitivity.

**Beamforming is deliberately not implemented.** The array spans 57 mm
diagonally; at 1 kHz that is 0.17 of a wavelength. Delay-and-sum would sum
four nearly identical signals — √4 = 6 dB of noise averaging and no
directivity. If you use it, call it 4-channel averaging and be honest.

Near endfire the array goes blind: sensitivity is `(d/c)·sin θ`, which
vanishes as θ → 0. The firmware reports a confidence value; use it.

---

## Layout

```
capstone.py                 one entry point for the host-side pipeline
sar_gui.py                  desktop app: live detection, per-mic recording
BUILD.md                    step-by-step build and flash

ML/                         features, training, QC, C-header export
INMP_441_Dataset/           your own recordings (speech / non_speech)
Public_Dataset/             MUSAN, ESC-50, Speech Commands (optional)

Recording_Via_IOT_Devices/
  record.py                 capture audio, any of three boards
  detector_monitor.py       read the Detector's result packets
  devices.py                per-board baud, framing, DTR/RTS policy
  firmware/K210/
    src/Recorder/           probe the mics, stream one at a time
    src/Detector/           4 mics at once, VAD + DOA on device
```

Two firmware projects share one SDK tree. `-DPROJ=Recorder` or
`-DPROJ=Detector`. Delete `build/` between them — a stale `CMakeCache.txt`
pins the old `PROJ` and will rebuild the wrong firmware without complaint.

---

## Quick start

```bash
pip install -r requirements.txt
python capstone.py status          # what exists, and what to do next
```

Full sequence in [BUILD.md](BUILD.md): probe → record → QC → train → export
→ flash → monitor.

---

## The measurement discipline

This is the part worth copying, more than the code.

**A confound probe gates every dataset.** `capstone.py qc` trains a
classifier on background noise only — quietest frames, level divided out, no
speech present at all. If it can still separate the two folders, they differ
by recording conditions rather than by speech, and any accuracy measured
afterwards is fiction. The first dataset scored **0.905**. It should be near
0.500.

**Splits are grouped by source file, never by window.** Windows cut from one
recording are near-duplicates; splitting them randomly grades the model on
data it has already seen.

**Recall at 5% false-alarm rate, not accuracy.** A missed victim and a false
alarm are not the same cost, so one accuracy figure cannot describe both.
PR-AUC is only comparable between runs of equal prevalence — its chance
baseline *is* the positive rate — so cross-run comparisons use ROC-AUC or
recall@FPR.

**Corpora are budgeted by window count, not file count.** One MUSAN speech
file yields ~1000 analysis windows; one Speech Commands clip yields 1. An
equal file cap left MUSAN with 99.4% of the positive mass and the speaker
diversity never reached the model.

---

## Things that cost real time, recorded so they don't again

**Unframed PCM cannot survive a dropped byte.** Lose one and the 16-bit
sample boundary flips: every sample afterwards is noise near Nyquist, while
the WAV header stays valid and the file still plays. Three files failed this
way and it went unnoticed for weeks. Every frame now carries a sequence
number and a checksum, so a loss is *counted* instead of silent.

**The magic word is not a sync point.** `0x5A 0xA5` occurs by chance inside
int16 audio in about 1.6% of blocks. Four things are checked before a frame
is accepted: shape fields sane, channel count matching, checksum good, and
sequence advancing by exactly one.

**`(int16_t)x` truncates, it does not clamp.** An overloaded sample wraps to
the opposite rail, so a sine becomes a sawtooth — and a sawtooth has
mean|x|/peak near 0.5, the same fingerprint as random noise. A wrapping
channel looks exactly like a floating pin while the clip counter reads zero.

**A floating pin reads as random bits**, not as a constant, so checks for
all-zero and all-ones both miss it. Its signature is mean|x| ≈ 16384 with
peak-to-peak pinned at full scale, unchanging no matter what you do to the
microphones.

**PHAT must be band-masked.** Whitening divides every bin by its own
magnitude, so bins outside the signal band — holding only numerical noise —
get amplified to unit weight alongside the real ones. Unmasked, a true delay
of 1.50 samples was estimated as 0.14. Masked: 1.49.

**`i2s_set_sample_rate` returns the bit clock**, 64× the sample rate.
Comparing it against 16000 reports a mismatch on a perfectly healthy chain.

**16000 is not a power of two.** `voice_band_ratio` originally took one
16000-point FFT, which no K210 implementation reproduces. The framed
approximation differed by 0.065 — against a model weight of 4.03, that is
0.26 of logit, roughly 11% of the decision margin, lost silently on device.
Both sides now use 512-point frames and agree to 9.3e-6.

---

## Status

| | |
|---|---|
| 4-mic capture, per-slot diagnostics | working on hardware |
| 3-feature VAD, host and device | parity verified to 1e-6 (harmonicity), 0.013 dB (SNR) |
| DOA | verified in simulation, **not yet on hardware** |
| Dataset confound | 0.812 on the latest recordings — still above the 0.65 target |
| Beamforming | not implemented, and not worth it at this aperture |

The open item is the dataset. Until the confound probe passes, device-side
accuracy numbers are not measurements.

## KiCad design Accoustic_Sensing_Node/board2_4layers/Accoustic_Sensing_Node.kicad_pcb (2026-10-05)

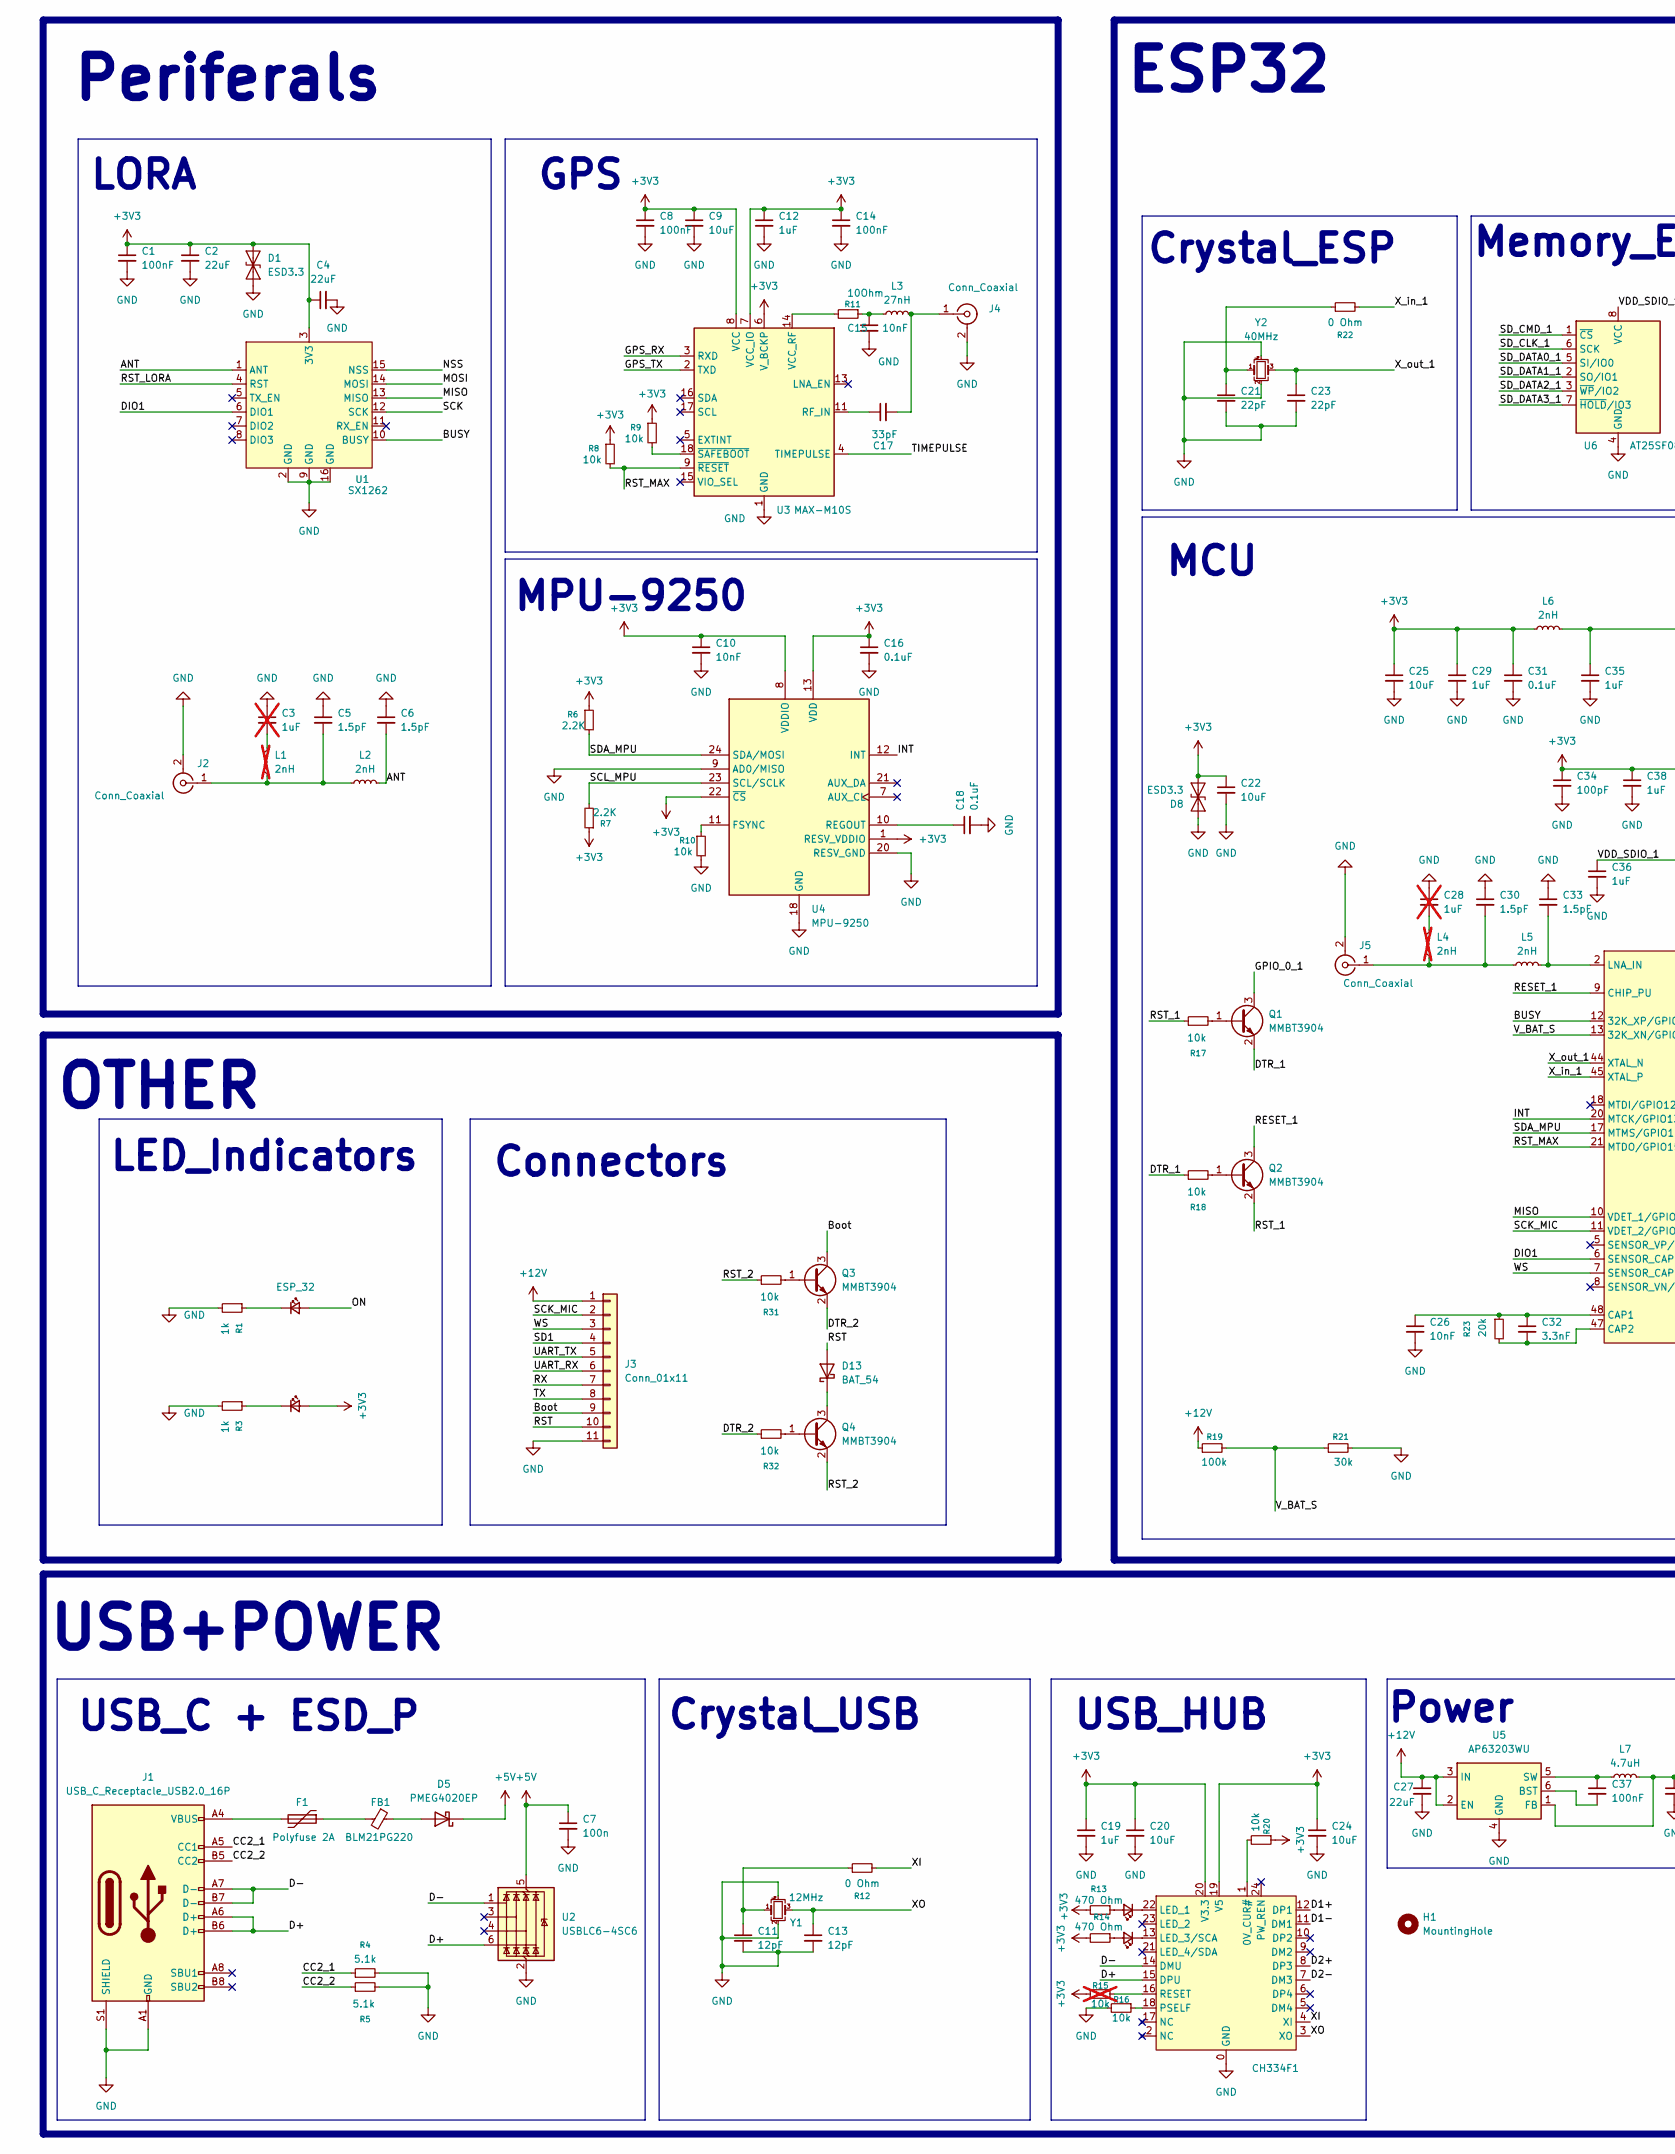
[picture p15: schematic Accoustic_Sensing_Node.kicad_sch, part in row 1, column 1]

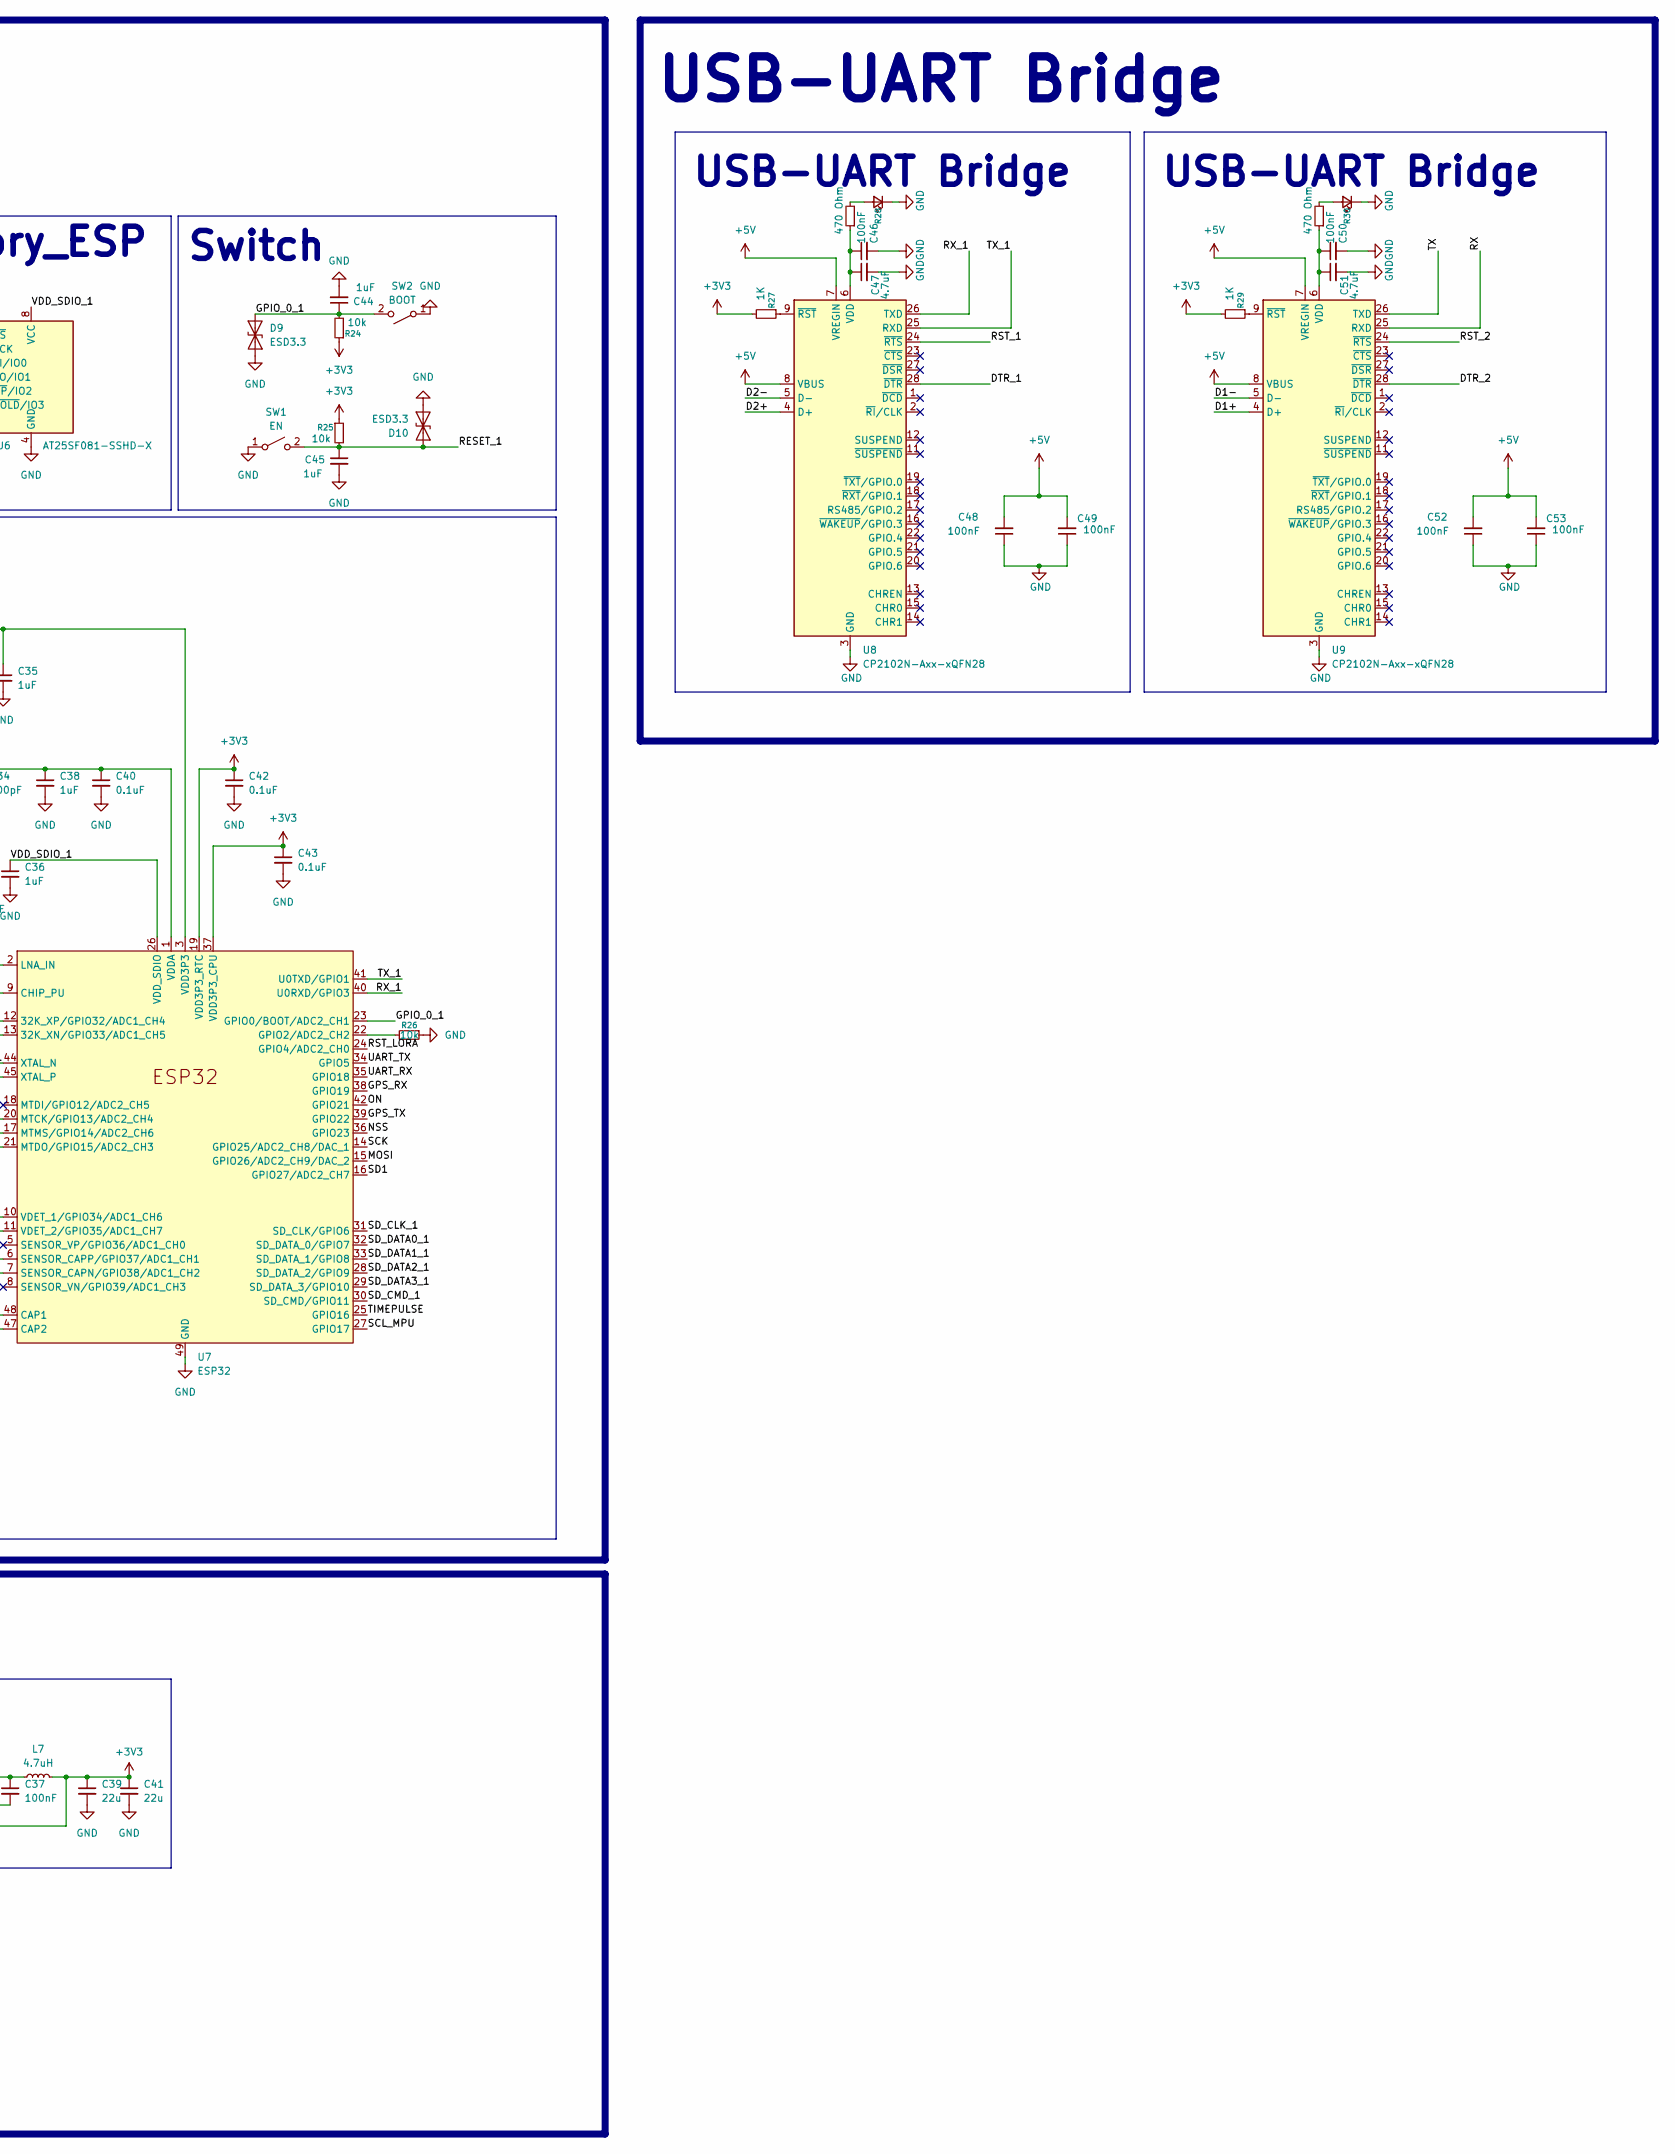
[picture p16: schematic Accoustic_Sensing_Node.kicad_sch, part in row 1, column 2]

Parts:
C1, C8, C14, C37: 100nF; C_0603_1608Metric
C2, C4, C27: 22uF; C_0805_2012Metric
C3, C28: 1uF; C_0603_1608Metric; not fitted
C5, C6, C30, C33: 1.5pF; C_0402_1005Metric
C7: 100n; C_0402_1005Metric
C9, C20, C22, C24: 10uF; C_0805_2012Metric
C10, C15: 10nF; C_0603_1608Metric
C11, C13: 12pF; C_0402_1005Metric
C12: 1uF; C_0402_1005Metric
C16, C18, C31, C40, C42, C43: 0.1uF; C_0402_1005Metric
C17: 33pF; C_0402_1005Metric
C19, C29, C35, C36, C38, C44, C45: 1uF; C_0603_1608Metric
C21, C23: 22pF; C_0402_1005Metric
C25: 10uF; C_0805_2012Metric_Pad1.18x1.45mm_HandSolder
C26: 10nF; C_0402_1005Metric
C32: 3.3nF; C_0402_1005Metric
C34: 100pF; C_0402_1005Metric
C39, C41: 22u; C_0805_2012Metric
C46, C48, C49, C50, C52, C53: 100nF; C_0402_1005Metric
C47, C51: 4.7uF; C_0805_2012Metric
CH334F1: QFN24_4MM
D1, D8, D9, D10: ESD3.3; D_SOD-523
D2: ESP_32; LED_0805_2012Metric
D4: Power; LED_0805_2012Metric
D5: PMEG4020EP; D_SOD-123F
D6: USB1; LED_0805_2012Metric
D7: USB2; LED_0805_2012Metric
D11, D12: UART1_ON; LED_0805_2012Metric
D13: BAT_54; SOT-23
F1: Polyfuse 2A; Fuse_1206_3216Metric
FB1: BLM21PG220; L_0805_2012Metric
H1: MountingHole; MountingHole_2.7mm_M2.5_Pad_TopBottom
J1: USB_C_Receptacle_USB2.0_16P; USB_C_Receptacle_HCTL_HC-TYPE-C-16P-01A
J2, J4, J5: Conn_Coaxial; U.FL_Hirose_U.FL-R-SMT-1_Vertical
J3: Conn_01x11; Castellated_Edge_11P_2.54
L1, L4: 2nH; L_0402_1005Metric; not fitted
L2, L5, L6: 2nH; L_0402_1005Metric
L3: 27nH; L_0402_1005Metric
L7: 4.7uH; L_Sunlord_SWPA6020S
Q1, Q2, Q3, Q4: MMBT3904; SOT-23
R1, R3: 1k; R_0402_1005Metric
R4, R5: 5.1k; R_0402_1005Metric
R6, R7: 2.2K; R_0402_1005Metric
R8, R9, R10, R16, R17, R18, R20, R24, R25, R26, R31, R32: 10k; R_0402_1005Metric
R11: 10Ohm; R_0805_2012Metric
R12, R22: 0 Ohm; R_0402_1005Metric
R13, R14, R28, R30: 470 Ohm; R_0402_1005Metric
R15: 10k; R_0402_1005Metric; not fitted
R19: 100k; R_0402_1005Metric
R21: 30k; R_0402_1005Metric
R23: 20k; R_0402_1005Metric
R27, R29: 1K; R_0402_1005Metric
SW1: EN; SW_CS1213AGF260_CRS
SW2: BOOT; SW_CS1213AGF260_CRS
U1: SX1262; SX1262-B
U2: USBLC6-4SC6; SOT-23-6
U3: MAX-M10S; ublox_MAX
U4: MPU-9250; InvenSense_QFN-24_3x3mm_P0.4mm
U5: AP63203WU; TSOT-23-6
U6: AT25SF081-SSHD-X; SOIC-8_3.9x4.9mm_P1.27mm
U7: ESP32; QFN-48-1EP_5x5mm_P0.35mm_EP3.7x3.7mm
U8, U9: CP2102N-Axx-xQFN28; QFN-28-1EP_5x5mm_P0.5mm_EP3.35x3.35mm
Y1: 12MHz; Crystal_SMD_3225-4Pin_3.2x2.5mm
Y2: 40MHz; Crystal_SMD_3225-4Pin_3.2x2.5mm

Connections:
+3V3: C1.1, C2.1, C4.1, C8.1, C9.1, C10.1, C12.1, C14.1, C16.1, C19.1, C20.1, C22.1, C24.1, C25.1, C29.1, C31.1, C34.1, C38.1, C39.1, C40.1, C41.1, C42.1, C43.1, CH334F1.19 (V5), CH334F1.20 (V3.3), D1.2 (A2), D4.2 (A), D8.1 (A1), L6.1, L7.2, R6.1, R7.1, R8.1, R9.1, R13.2, R14.2, R15.2, R20.1, R24.1, R25.1, R27.2, R29.2, U1.3 (3V3), U3.6 (V_BCKP), U3.7 (VCC_IO), U3.8 (VCC), U4.1 (RESV_VDDIO), U4.8 (VDDIO), U4.13 (VDD), U4.22 (~CS), U5.1 (FB), U7.1 (VDDA), U7.19 (VDD3P3_RTC), U7.37 (VDD3P3_CPU), U7.43 (VDDA), U7.46 (VDDA)
+5V: C7.1, C48.2, C49.2, C52.2, C53.2, D5.1 (K), U2.5 (VBUS), U8.7 (VREGIN), U8.8 (VBUS), U9.7 (VREGIN), U9.8 (VBUS)
+12V: C27.1, J3.1, R19.1, U5.2 (EN), U5.3 (IN)
/ANT: C6.2, L2.2, U1.1 (ANT)
/BUSY: U1.10 (BUSY), U7.12 (32K_XP/GPIO32/ADC1_CH4)
/Boot: J3.9, Q3.3 (C)
/CC2_1: J1.A5 (CC1), R4.1
/CC2_2: J1.B5 (CC2), R5.1
/D1+: CH334F1.12 (DP1), U9.4 (D+)
/D1-: CH334F1.11 (DM1), U9.5 (D-)
/D2+: CH334F1.8 (DP3), U8.4 (D+)
/D2-: CH334F1.7 (DM3), U8.5 (D-)
/D+: CH334F1.15 (DPU), J1.A6 (D+), J1.B6 (D+), U2.6 (I/O4)
/D-: CH334F1.14 (DMU), J1.A7 (D-), J1.B7 (D-), U2.1 (I/O1)
/DIO1: U1.6 (DIO1), U7.6 (SENSOR_CAPP/GPIO37/ADC1_CH1)
/DTR_1: Q1.2 (E), R18.1, U8.28 (~DTR)
/DTR_2: Q3.2 (E), R32.1, U9.28 (~DTR)
/GPIO_0_1: C44.1, D9.2 (A2), Q1.3 (C), R24.2, SW2.2 (B), U7.23 (GPIO0/BOOT/ADC2_CH1)
/GPS_RX: U3.3 (RXD), U7.38 (GPIO19)
/GPS_TX: U3.2 (TXD), U7.39 (GPIO22)
/INT: U4.12 (INT), U7.20 (MTCK/GPIO13/ADC2_CH4)
/MISO: U1.13 (MISO), U7.10 (VDET_1/GPIO34/ADC1_CH6)
/MOSI: U1.14 (MOSI), U7.15 (GPIO26/ADC2_CH9/DAC_2)
/NSS: U1.15 (NSS), U7.36 (GPIO23)
/ON: D2.2 (A), U7.42 (GPIO21)
/RESET_1: C45.1, D10.2 (A2), Q2.3 (C), R25.2, SW1.2 (B), U7.9 (CHIP_PU)
/RST: D13.2 (A), J3.10
/RST_1: Q2.2 (E), R17.1, U8.24 (~RTS)
/RST_2: Q4.2 (E), R31.1, U9.24 (~RTS)
/RST_LORA: U1.4 (RST), U7.24 (GPIO4/ADC2_CH0)
/RST_MAX: R8.2, U3.9 (~RESET), U7.21 (MTDO/GPIO15/ADC2_CH3)
/RX: J3.7, U9.25 (RXD)
/RX_1: U7.40 (U0RXD/GPIO3), U8.26 (TXD)
/SCK: U1.12 (SCK), U7.14 (GPIO25/ADC2_CH8/DAC_1)
/SCK_MIC: J3.2, U7.11 (VDET_2/GPIO35/ADC1_CH7)
/SCL_MPU: R7.2, U4.23 (SCL/SCLK), U7.27 (GPIO17)
/SD1: J3.4, U7.16 (GPIO27/ADC2_CH7)
/SDA_MPU: R6.2, U4.24 (SDA/MOSI), U7.17 (MTMS/GPIO14/ADC2_CH6)
/SD_CLK_1: U6.6 (SCK), U7.31 (SD_CLK/GPIO6)
/SD_CMD_1: U6.1 (~CS), U7.30 (SD_CMD/GPIO11)
/SD_DATA0_1: U6.5 (SI/IO0), U7.32 (SD_DATA_0/GPIO7)
/SD_DATA1_1: U6.2 (SO/IO1), U7.33 (SD_DATA_1/GPIO8)
/SD_DATA2_1: U6.3 (~WP/IO2), U7.28 (SD_DATA_2/GPIO9)
/SD_DATA3_1: U6.7 (~HOLD/IO3), U7.29 (SD_DATA_3/GPIO10)
/TIMEPULSE: U3.4 (TIMEPULSE), U7.25 (GPIO16)
/TX: J3.8, U9.26 (TXD)
/TX_1: U7.41 (U0TXD/GPIO1), U8.25 (RXD)
/UART_RX: J3.6, U7.35 (GPIO18)
/UART_TX: J3.5, U7.34 (GPIO5)
/VDD_SDIO_1: C36.1, U6.8 (VCC), U7.26 (VDD_SDIO)
/V_BAT_S: R19.2, R21.1, U7.13 (32K_XN/GPIO33/ADC1_CH5)
/WS: J3.3, U7.7 (SENSOR_CAPN/GPIO38/ADC1_CH2)
/XI: CH334F1.4 (XI), R12.2
/XO: C13.1, CH334F1.3 (XO), Y1.3
/X_in_1: R22.2, U7.45 (XTAL_P)
/X_out_1: C23.1, U7.44 (XTAL_N), Y2.3
GND: C1.2, C2.2, C3.1, C4.2, C5.1, C6.1, C7.2, C8.2, C9.2, C10.2, C11.2, C12.2, C13.2, C14.2, C15.2, C16.2, C18.2, C19.2, C20.2, C21.2, C22.2, C23.2, C24.2, C25.2, C26.2, C27.2, C28.1, C29.2, C30.1, C31.2, C33.1, C34.2, C35.2, C36.2, C38.2, C39.2, C40.2, C41.2, C42.2, C43.2, C44.2, C45.2, C46.2, C47.2, C48.1, C49.1, C50.2, C51.2, C52.1, C53.1, CH334F1.0 (GND), D1.1 (A1), D8.2 (A2), D9.1 (A1), D10.1 (A1), D11.1 (K), D12.1 (K), J1.A1 (GND), J1.A12 (GND), J1.B1 (GND), J1.B12 (GND), J1.S1 (SHIELD), J2.2 (Ext), J3.11, J4.2 (Ext), J5.2 (Ext), R1.2, R3.2, R4.2, R5.2, R10.2, R16.2, R21.2, R26.1, SW1.1 (A), SW2.1 (A), U1.2 (GND), U1.9 (GND), U1.16 (GND), U2.2 (GND), U3.1 (GND), U3.10 (GND), U3.12 (GND), U4.9 (AD0/MISO), U4.18 (GND), U4.20 (RESV_GND), U5.4 (GND), U6.4 (GND), U7.49 (GND), U8.3 (GND), U8.29 (GND), U9.3 (GND), U9.29 (GND), Y1.2, Y1.4, Y2.2, Y2.4
unnamed: C3.2, L1.2
unnamed: C11.1, R12.1, Y1.1
unnamed: C15.1, L3.1, R11.1
unnamed: C21.1, R22.1, Y2.1
unnamed: C28.2, L4.2
unnamed: C35.1, L6.2, U7.3 (VDD3P3), U7.4 (VDD3P3)
unnamed: CH334F1.1 (0V_CUR#), R20.2
unnamed: CH334F1.22 (LED_1), D6.1 (K)
unnamed: CH334F1.13 (LED_3/SCA), D7.1 (K)
unnamed: CH334F1.18 (PSELF), R16.1
unnamed: CH334F1.16 (RESET), R15.1
unnamed: D2.1 (K), R1.1
unnamed: D4.1 (K), R3.1
unnamed: D5.2 (A), FB1.1
unnamed: D6.2 (A), R13.1
unnamed: D7.2 (A), R14.1
unnamed: D11.2 (A), R28.2
unnamed: D12.2 (A), R30.2
unnamed: D13.1 (K), Q4.3 (C)
unnamed: F1.1, FB1.2
unnamed: F1.2, J1.A4 (VBUS), J1.A9 (VBUS), J1.B4 (VBUS), J1.B9 (VBUS)
unnamed: C5.2, J2.1 (In), L1.1, L2.1
unnamed: C17.2, J4.1 (In), L3.2
unnamed: C30.2, J5.1 (In), L4.1, L5.1
unnamed: Q1.1 (B), R17.2
unnamed: Q2.1 (B), R18.2
unnamed: Q3.1 (B), R31.2
unnamed: Q4.1 (B), R32.2
unnamed: C17.1, U3.11 (RF_IN)
unnamed: R11.2, U3.14 (VCC_RF)
unnamed: R9.2, U3.18 (~SAFEBOOT)
unnamed: R10.1, U4.11 (FSYNC)
unnamed: C18.1, U4.10 (REGOUT)
unnamed: C37.2, U5.6 (BST)
unnamed: C37.1, L7.1, U5.5 (SW)
unnamed: C26.1, C32.1, R23.1, U7.48 (CAP1)
unnamed: C32.2, R23.2, U7.47 (CAP2)
unnamed: R26.2, U7.22 (GPIO2/ADC2_CH2)
unnamed: C33.2, L5.2, U7.2 (LNA_IN)
unnamed: C46.1, C47.1, R28.1, U8.6 (VDD)
unnamed: R27.1, U8.9 (~RST)
unnamed: C50.1, C51.1, R30.1, U9.6 (VDD)
unnamed: R29.1, U9.9 (~RST)

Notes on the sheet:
Switch
OTHER
MPU-9250
Power
MCU
USB-UART Bridge
Crystal_ESP
GPS
USB+POWER
Crystal_USB
ESP32
Memory_ESP
LED_Indicators
USB_HUB
Connectors
USB_C + ESD_P
Periferals
LORA

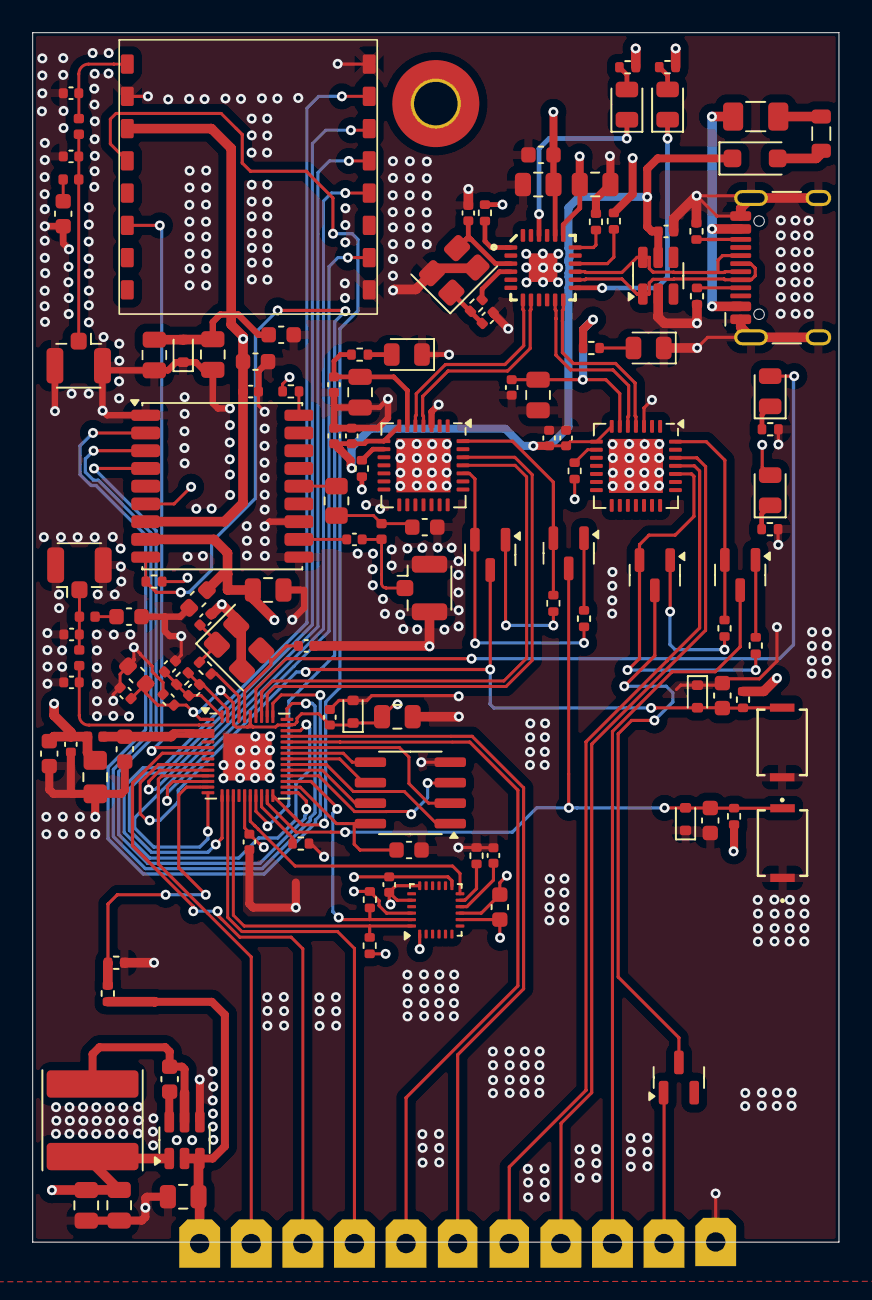
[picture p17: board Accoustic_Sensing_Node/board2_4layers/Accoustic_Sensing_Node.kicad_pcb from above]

Board: 4 copper layers, 50.0 x 75.0 mm, 129 parts (0 on the bottom side), 100 nets.

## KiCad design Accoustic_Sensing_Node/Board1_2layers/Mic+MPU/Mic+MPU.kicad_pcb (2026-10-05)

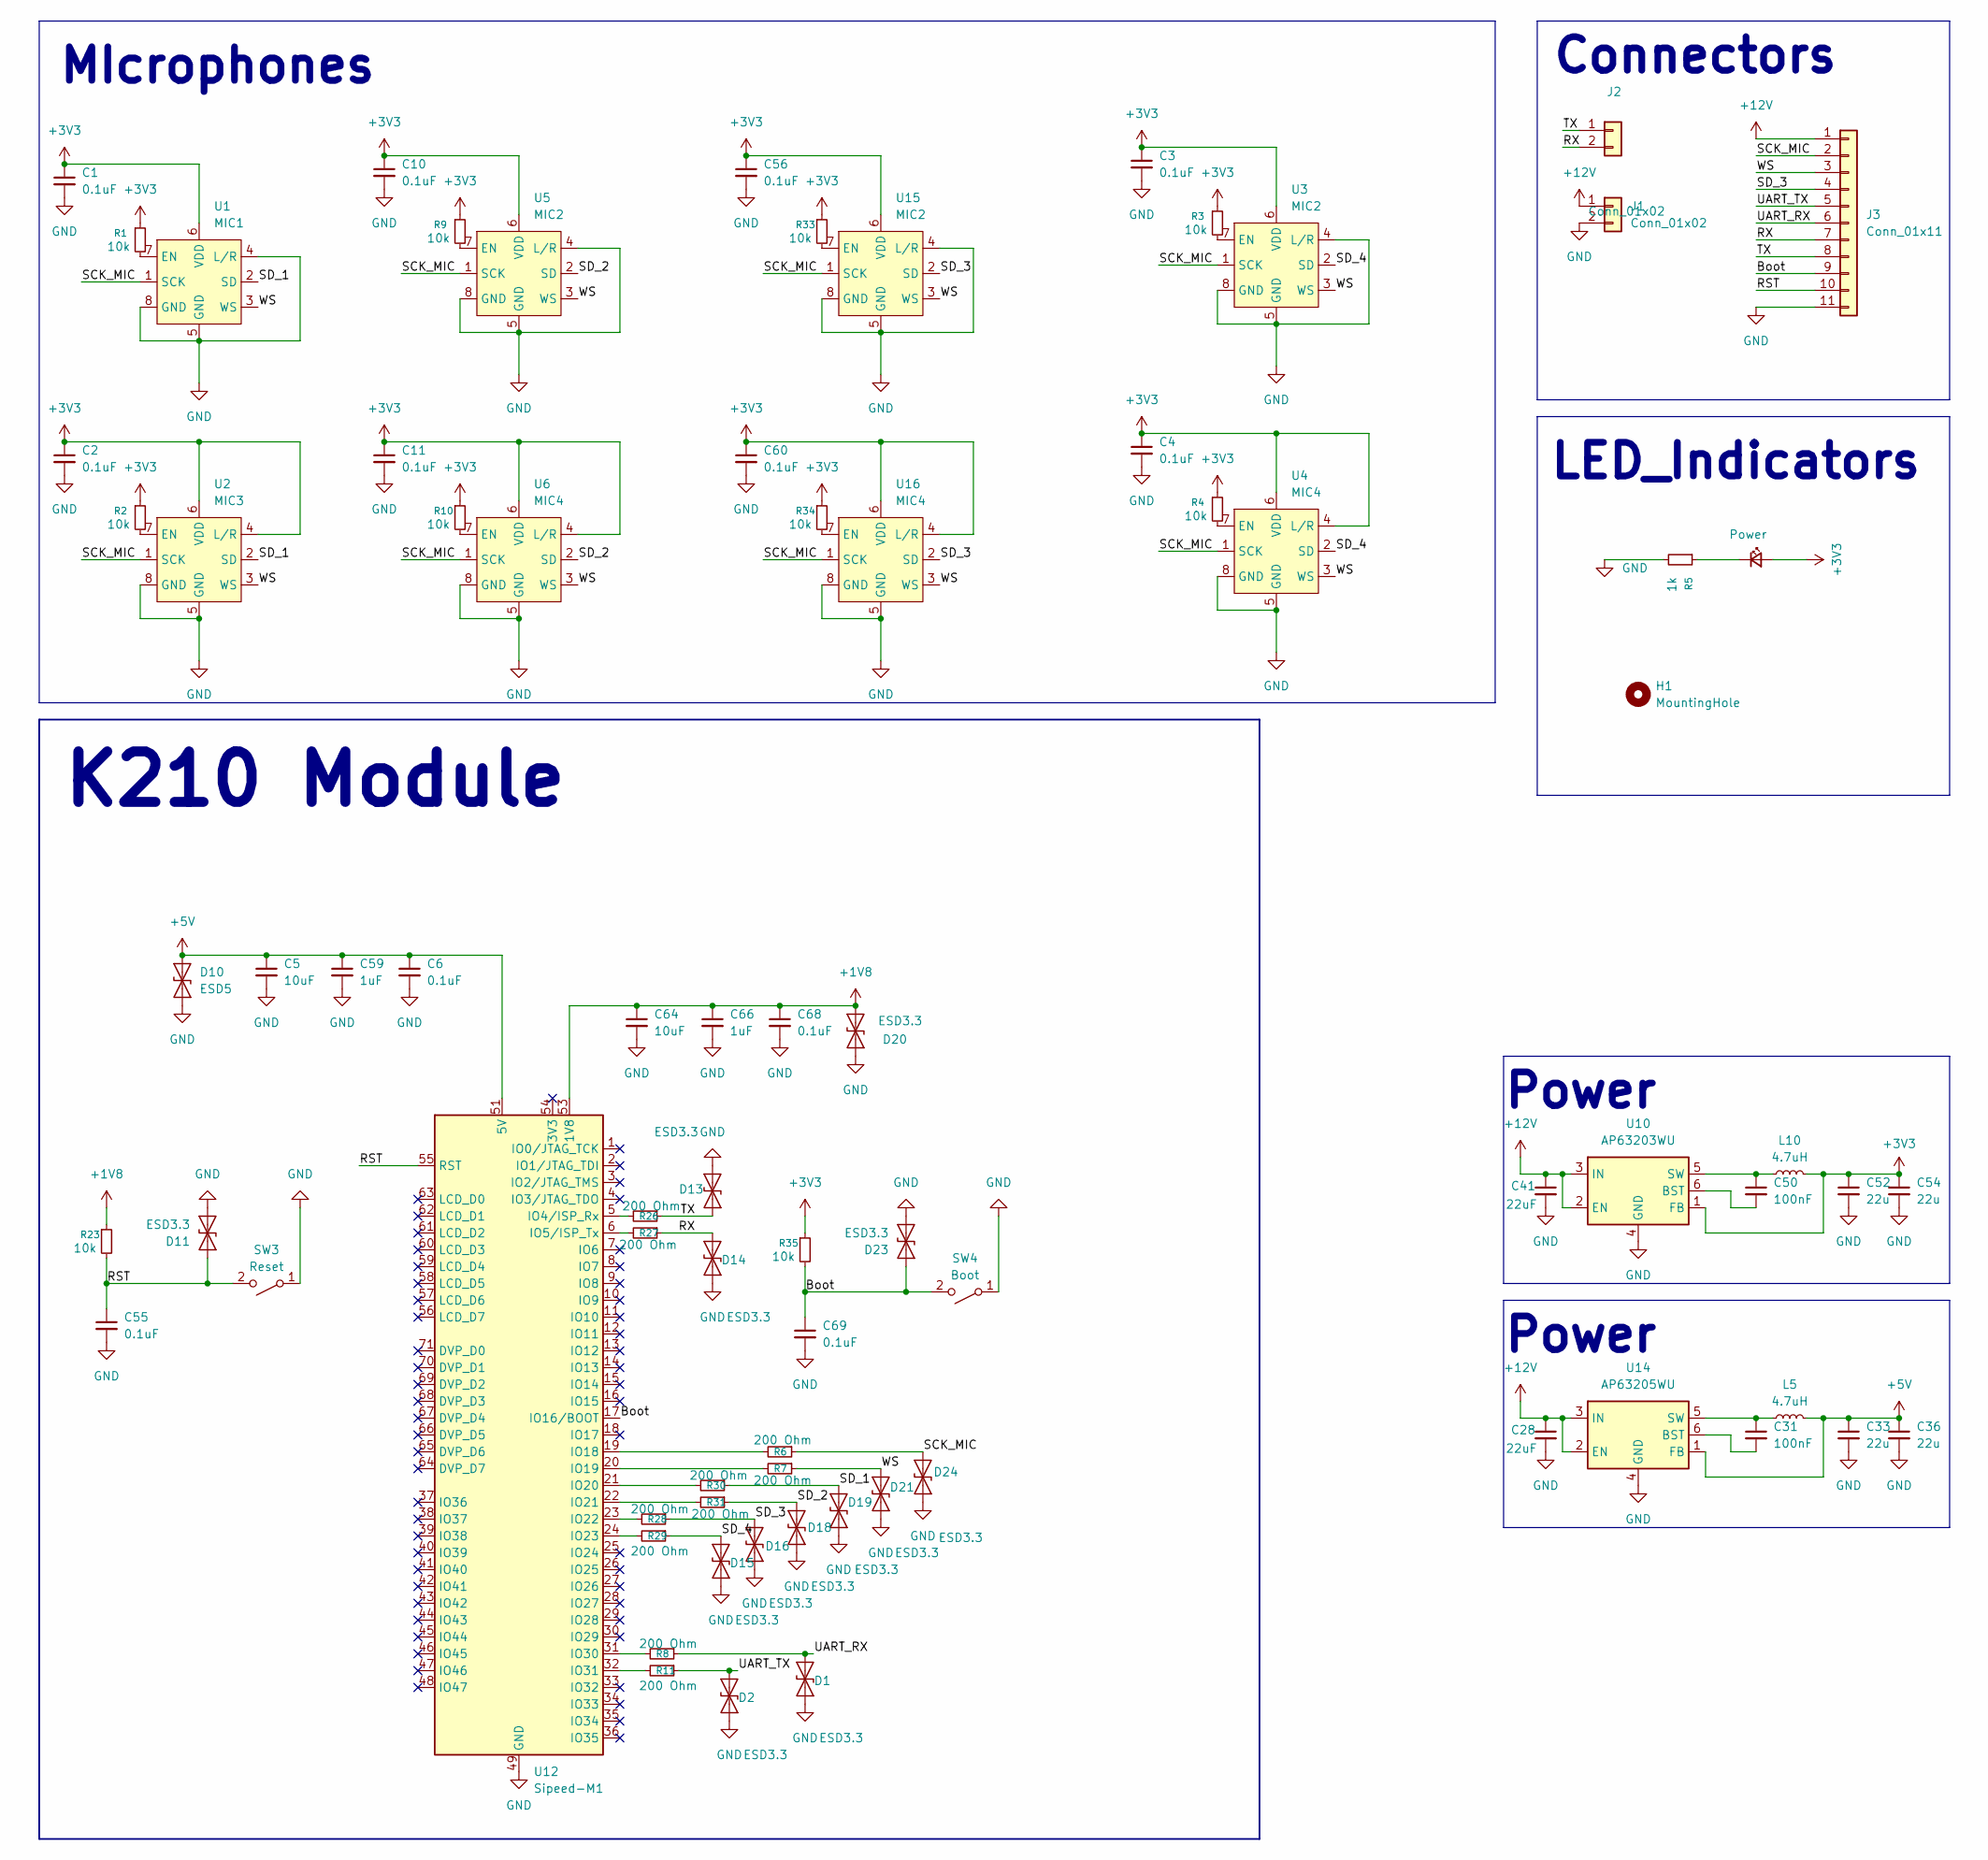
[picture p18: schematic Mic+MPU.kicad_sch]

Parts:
C1, C2, C3, C4, C6, C10, C11, C55, C56, C60, C68, C69: 0.1uF; C_0402_1005Metric
C5, C64: 10uF; C_0805_2012Metric
C28, C41: 22uF; C_0805_2012Metric
C31, C50: 100nF; C_0603_1608Metric
C33, C36, C52, C54: 22u; C_0805_2012Metric
C59, C66: 1uF; C_0603_1608Metric
D1, D2, D11, D13, D14, D15, D16, D18, D19, D20, D21, D23, D24: ESD3.3; D_SOD-523
D3: Power; LED_0805_2012Metric
D10: ESD5; D_SOD-523
H1: MountingHole; MountingHole_2.7mm_M2.5_Pad_TopBottom
J1: Conn_01x02; JST_XH_B2B-XH-A_1x02_P2.50mm_Vertical
J2: Conn_01x02; PinHeader_1x02_P2.54mm_Vertical
J3: Conn_01x11; Con_01x011
L5, L10: 4.7uH; L_Sunlord_SWPA6020S
R1, R2, R3, R4, R9, R10, R23, R33, R34, R35: 10k; R_0402_1005Metric
R5: 1k; R_0402_1005Metric
R6, R7, R8, R11, R26, R27, R28, R29, R30, R31: 200 Ohm; R_0402_1005Metric
SW3: Reset; SW_CS1213AGF260_CRS
SW4: Boot; SW_CS1213AGF260_CRS
U1: MIC1; INMP441
U2: MIC3; INMP441
U3, U5, U15: MIC2; INMP441
U4, U6, U16: MIC4; INMP441
U10: AP63203WU; TSOT-23-6
U12: Sipeed-M1
U14: AP63205WU; TSOT-23-6

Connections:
+1V8: C64.1, C66.1, C68.1, D20.1 (A1), R23.1, U12.53 (1V8)
+3V3: C1.1, C2.1, C3.1, C4.1, C10.1, C11.1, C52.1, C54.1, C56.1, C60.1, D3.2 (A), L10.2, R1.1, R2.1, R3.1, R4.1, R9.1, R10.1, R33.1, R34.1, R35.1, U1.6 (VDD), U2.4 (L/R), U2.6 (VDD), U3.6 (VDD), U4.4 (L/R), U4.6 (VDD), U5.6 (VDD), U6.4 (L/R), U6.6 (VDD), U10.1 (FB), U15.6 (VDD), U16.4 (L/R), U16.6 (VDD)
+5V: C5.1, C6.1, C33.1, C36.1, C59.1, D10.2 (A2), L5.2, U12.51 (5V), U12.52 (5V), U14.1 (FB)
+12V: C28.1, C41.1, J1.1, J3.1, U10.2 (EN), U10.3 (IN), U14.2 (EN), U14.3 (IN)
/Boot: C69.1, D23.2 (A2), J3.9, R35.2, SW4.2 (B), U12.17 (IO16/BOOT)
/RST: C55.1, D11.2 (A2), J3.10, R23.2, SW3.2 (B), U12.55 (RST)
/RX: D14.2 (A2), J2.2, J3.7, R27.1
/SCK_MIC: D24.2 (A2), J3.2, R6.1, U1.1 (SCK), U2.1 (SCK), U3.1 (SCK), U4.1 (SCK), U5.1 (SCK), U6.1 (SCK), U15.1 (SCK), U16.1 (SCK)
/SD_1: D19.2 (A2), R30.1, U1.2 (SD), U2.2 (SD)
/SD_2: D18.2 (A2), R31.1, U5.2 (SD), U6.2 (SD)
/SD_3: D16.2 (A2), J3.4, R28.1, U15.2 (SD), U16.2 (SD)
/SD_4: D15.2 (A2), R29.1, U3.2 (SD), U4.2 (SD)
/TX: D13.2 (A2), J2.1, J3.8, R26.1
/UART_RX: D1.2 (A2), J3.6, R8.1
/UART_TX: D2.2 (A2), J3.5, R11.1
/WS: D21.2 (A2), J3.3, R7.1, U1.3 (WS), U2.3 (WS), U3.3 (WS), U4.3 (WS), U5.3 (WS), U6.3 (WS), U15.3 (WS), U16.3 (WS)
GND: C1.2, C2.2, C3.2, C4.2, C5.2, C6.2, C10.2, C11.2, C28.2, C33.2, C36.2, C41.2, C52.2, C54.2, C55.2, C56.2, C59.2, C60.2, C64.2, C66.2, C68.2, C69.2, D1.1 (A1), D2.1 (A1), D10.1 (A1), D11.1 (A1), D13.1 (A1), D14.1 (A1), D15.1 (A1), D16.1 (A1), D18.1 (A1), D19.1 (A1), D20.2 (A2), D21.1 (A1), D23.1 (A1), D24.1 (A1), J1.2, J3.11, R5.2, SW3.1 (A), SW4.1 (A), U1.4 (L/R), U1.5 (GND), U1.8 (GND), U2.5 (GND), U2.8 (GND), U3.4 (L/R), U3.5 (GND), U3.8 (GND), U4.5 (GND), U4.8 (GND), U5.4 (L/R), U5.5 (GND), U5.8 (GND), U6.5 (GND), U6.8 (GND), U10.4 (GND), U12.49 (GND), U12.50 (GND), U12.72 (GND), U14.4 (GND), U15.4 (L/R), U15.5 (GND), U15.8 (GND), U16.5 (GND), U16.8 (GND)
unnamed: D3.1 (K), R5.1
unnamed: R1.2, U1.7 (EN)
unnamed: R2.2, U2.7 (EN)
unnamed: R3.2, U3.7 (EN)
unnamed: R4.2, U4.7 (EN)
unnamed: R9.2, U5.7 (EN)
unnamed: R10.2, U6.7 (EN)
unnamed: C50.2, U10.6 (BST)
unnamed: C50.1, L10.1, U10.5 (SW)
unnamed: R26.2, U12.5 (IO4/ISP_Rx)
unnamed: R27.2, U12.6 (IO5/ISP_Tx)
unnamed: R6.2, U12.19 (IO18)
unnamed: R7.2, U12.20 (IO19)
unnamed: R30.2, U12.21 (IO20)
unnamed: R31.2, U12.22 (IO21)
unnamed: R28.2, U12.23 (IO22)
unnamed: R29.2, U12.24 (IO23)
unnamed: R8.2, U12.31 (IO30)
unnamed: R11.2, U12.32 (IO31)
unnamed: C31.2, U14.6 (BST)
unnamed: C31.1, L5.1, U14.5 (SW)
unnamed: R33.2, U15.7 (EN)
unnamed: R34.2, U16.7 (EN)

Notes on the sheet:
K210 Module
Power
Connectors
LED_Indicators
MIcrophones

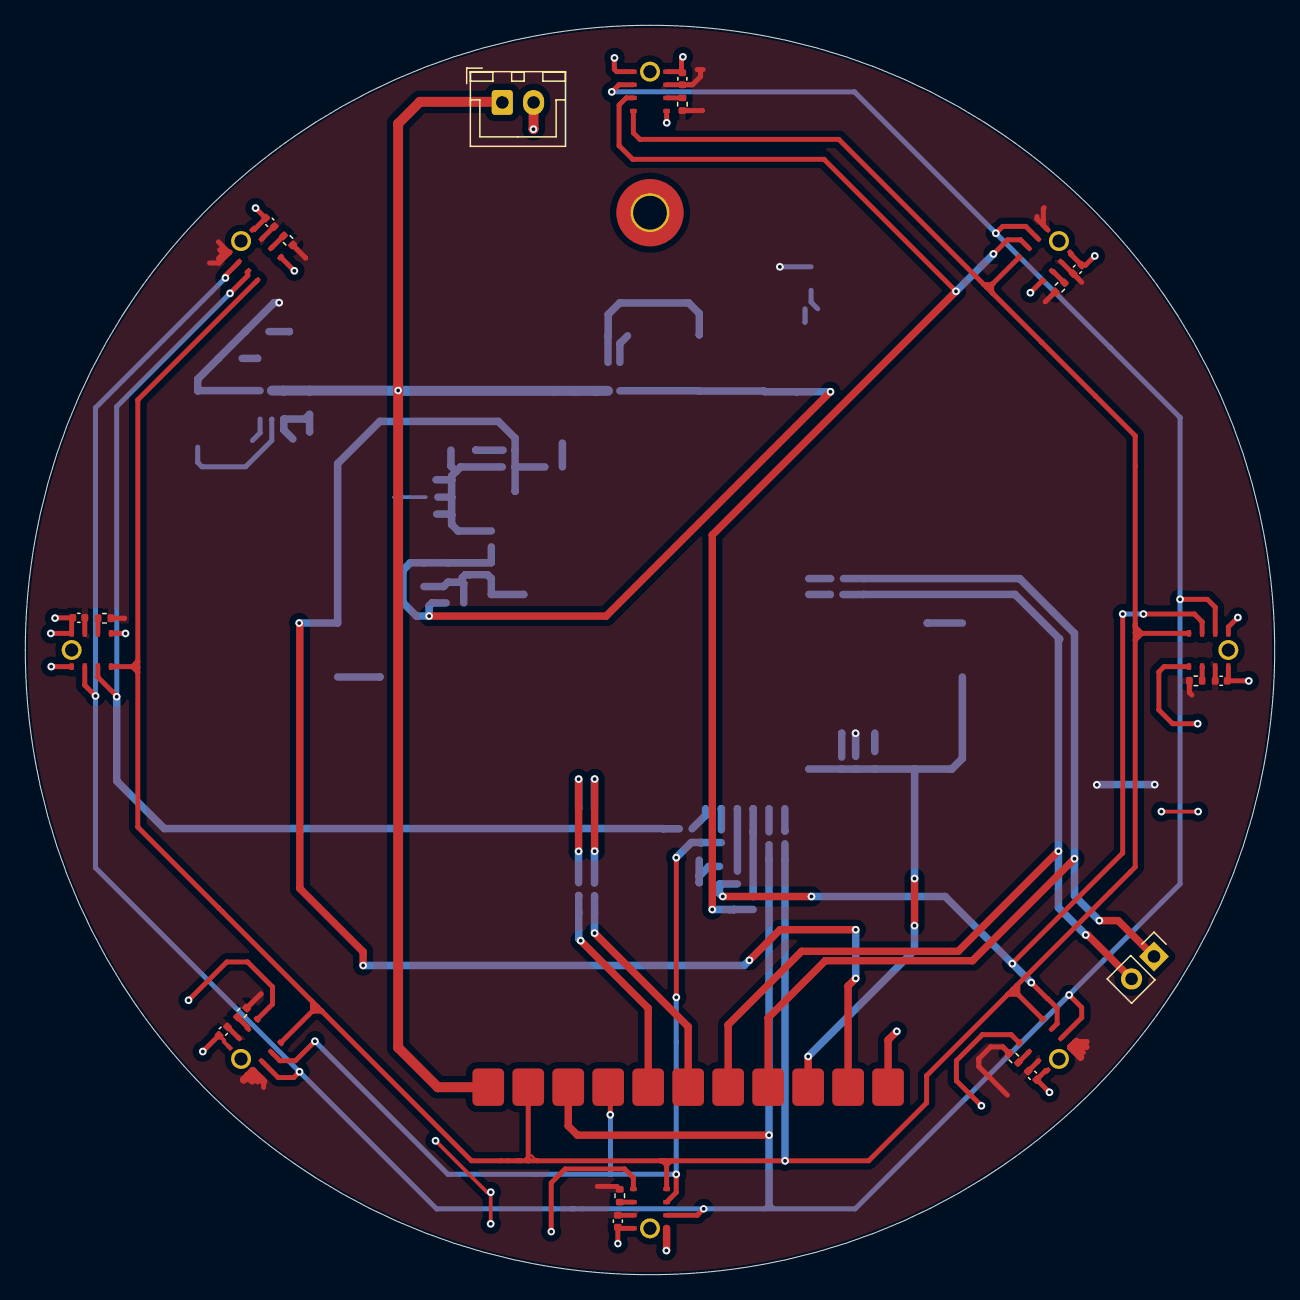
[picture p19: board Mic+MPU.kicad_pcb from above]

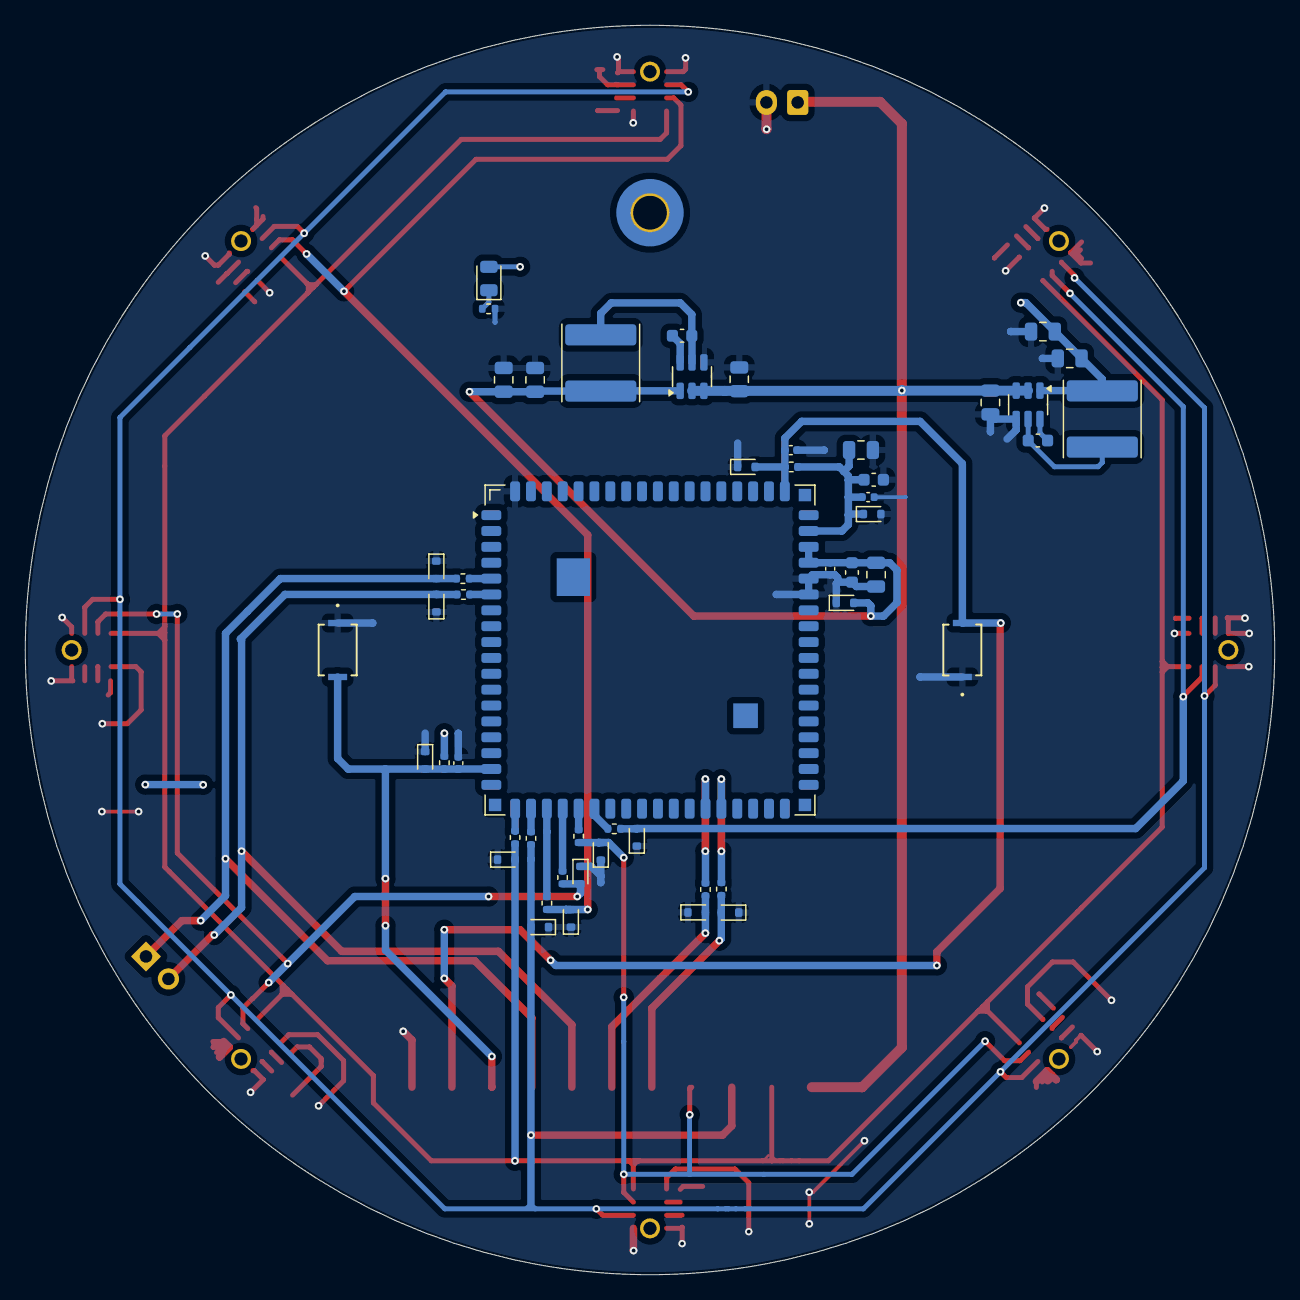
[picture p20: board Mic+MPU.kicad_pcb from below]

Board: 2 copper layers, 100.0 x 100.0 mm, 79 parts (51 on the bottom side), 40 nets.

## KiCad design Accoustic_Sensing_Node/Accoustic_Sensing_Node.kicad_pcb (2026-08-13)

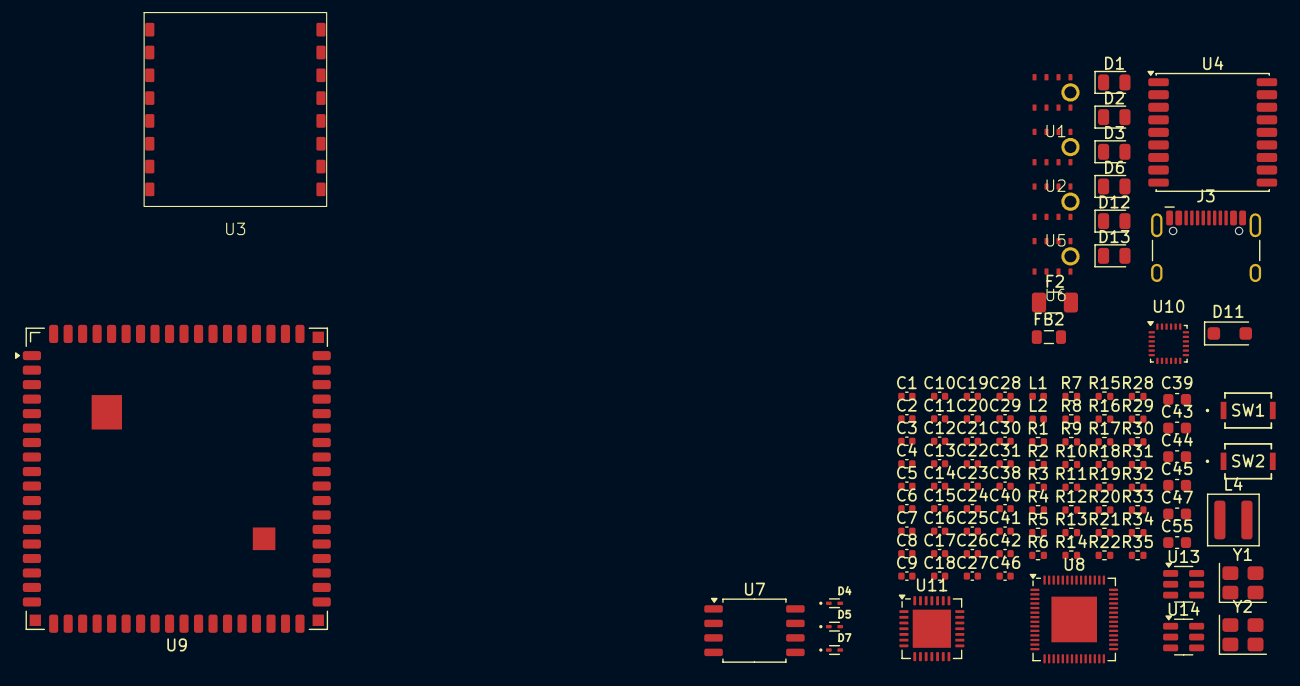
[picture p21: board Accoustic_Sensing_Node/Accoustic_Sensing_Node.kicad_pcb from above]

Board: 2 copper layers, 105 parts (0 on the bottom side), 65 nets, no tracks yet.

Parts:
C1, C2, C10, C11, C16, C17, C18, C19, C20, C22, C24, C30, C31, C46: 0.1uF; C_0402_1005Metric
C3, C5, C8, C21, C27, C28, C42: 100nF; C_0402_1005Metric
C4, C13: 10uF; C_0402_1005Metric
C6, C7, C15, C25, C26: 1uF; C_0402_1005Metric
C9, C23, C29: 10nF; C_0402_1005Metric
C12, C14: 30pF; C_0402_1005Metric
C38: 100n; C_0402_1005Metric
C39, C47: 10uF; C_0603_1608Metric
C40, C41: 12pF; C_0402_1005Metric
C43, C44: 22u; C_0603_1608Metric
C45: 1uF; C_0603_1608Metric
C55: 4.7uF; C_0603_1608Metric
D1: LORA_ON; LED_0805_2012Metric
D2: LORA_OFF; LED_0805_2012Metric
D3: Power; LED_0805_2012Metric
D4, D5, D7: ESD3.3; SODFL1006X40N
D6: UART1_ON; LED_0805_2012Metric
D11: PMEG4020EP; D_SOD-123F
D12: USB1; LED_0805_2012Metric
D13: USB2; LED_0805_2012Metric
F2: Polyfuse 2A; Fuse_1206_3216Metric
FB2: BLM21PG220; L_0805_2012Metric
J3: USB_C_Receptacle_USB2.0_16P; USB_C_Receptacle_HCTL_HC-TYPE-C-16P-01A
L1: 27nH; L_0402_1005Metric
L2: 2nH; L_0402_1005Metric
L4: 4.7uH; L_Coilcraft_XAL4030-XXX
R1, R2, R6, R7, R9, R10, R12, R20, R33, R34, R35: 10k; R_0402_1005Metric
R3, R4, R14, R31, R32: 470 Ohm; R_0402_1005Metric
R5: 1k; R_0402_1005Metric
R8: 10Ohm; R_0402_1005Metric
R11: 100 Ohm; R_0402_1005Metric
R13: 1K; R_0402_1005Metric
R15, R16, R17, R18, R19: 0kOhm; R_0402_1005Metric
R21, R22: 2.2K; R_0402_1005Metric
R28, R29: 5.1k; R_0402_1005Metric
R30: 0 Ohm; R_0402_1005Metric
SW1: BOOT; SW_CS1213AGF260_CRS
SW2: Reset; SW_CS1213AGF260_CRS
U1: MIC1; INMP441
U2: MIC3; INMP441
U3: SX1262; SX1262-B
U4: MAX-M10S; ublox_MAX
U5: MIC2; INMP441
U6: MIC4; INMP441
U7: W25Q128JVS; SOIC-8_5.3x5.3mm_P1.27mm
U8: ESP32-S3; QFN-56-1EP_7x7mm_P0.4mm_EP4x4mm
U9: Sipeed-M1
U10: MPU-9250; InvenSense_QFN-24_3x3mm_P0.4mm
U11: CP2102N-Axx-xQFN28; QFN-28-1EP_5x5mm_P0.5mm_EP3.35x3.35mm
U13: USBLC6-4SC6; SOT-23-6
U14: AP63203WU; TSOT-23-6
Y1: 40MHz; Crystal_SMD_3225-4Pin_3.2x2.5mm
Y2: 12MHz; Crystal_SMD_3225-4Pin_3.2x2.5mm

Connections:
+5V: C27.2, C28.2, C38.1, C39.1, D11.1 (K), U11.7 (VREGIN), U11.8 (VBUS), U13.5 (VBUS), U14.2 (EN), U14.3 (IN)
/BUSY: U3.10 (BUSY), U8.14 (GPIO9)
/CC2_1: J3.A5 (CC1), R28.1
/CC2_2: J3.B5 (CC2), R29.1
/D+: J3.A6 (D+), J3.B6 (D+), U13.6 (I/O4)
/D-: J3.A7 (D-), J3.B7 (D-), U13.1 (I/O1)
/DIO1: U3.6 (DIO1), U8.15 (GPIO10)
/LED_LORA_Green: D1.2 (A), U3.7 (DIO2)
/LED_LORA_red: D2.2 (A), U3.8 (DIO3)
/MISO: U3.13 (MISO), U8.12 (GPIO7)
/MOSI: U3.14 (MOSI), U8.11 (GPIO6)
/NSS: U3.15 (NSS), U8.9 (GPIO4)
/SCK: U3.12 (SCK), U8.10 (GPIO5)
/SCK_MIC: U1.1 (SCK), U2.1 (SCK), U5.1 (SCK), U6.1 (SCK), U8.19 (GPIO14)
/SD_1: U1.2 (SD), U5.2 (SD), U8.18 (GPIO13)
/SD_2: U2.2 (SD), U6.2 (SD), U8.17 (GPIO12)
/WS: U1.3 (WS), U2.3 (WS), U5.3 (WS), U6.3 (WS), U8.16 (GPIO11)
/XO: C41.1, Y2.3
/X_in_1: R11.2, U8.54 (XTAL_P)
/X_out_1: C14.1, U8.53 (XTAL_N), Y1.3
GND: C1.2, C2.2, C3.2, C4.2, C5.2, C6.2, C7.2, C8.2, C9.2, C10.2, C11.2, C12.2, C13.2, C14.2, C15.2, C16.2, C17.2, C18.2, C19.2, C20.2, C21.2, C22.2, C23.2, C24.2, C25.2, C26.2, C27.1, C28.1, C29.2, C30.2, C31.2, C38.2, C39.2, C40.2, C41.2, C43.2, C44.2, C45.2, C46.2, C47.2, C55.2, D4.1 (A1), D5.1 (A1), D6.1 (K), D7.1 (A1), J3.A1 (GND), J3.A12 (GND), J3.B1 (GND), J3.B12 (GND), J3.S1 (SHIELD), R3.2, R4.2, R5.2, R28.2, R29.2, R34.2, SW1.1 (A), SW2.1 (A), U1.4 (L/R), U1.5 (GND), U1.8 (GND), U2.4 (L/R), U2.5 (GND), U2.8 (GND), U3.2 (GND), U3.9 (GND), U3.16 (GND), U4.1 (GND), U4.10 (GND), U4.12 (GND), U5.5 (GND), U5.8 (GND), U6.5 (GND), U6.8 (GND), U7.4 (GND), U8.57 (GND), U10.18 (GND), U10.20 (RESV_GND), U11.3 (GND), U11.29 (GND), U13.2 (GND), U14.4 (GND), Y1.2, Y1.4, Y2.2, Y2.4
unnamed: C9.1, L1.2, R8.2
unnamed: C12.1, R11.1, Y1.1
unnamed: C18.1, L2.2, U8.2 (VDD3P3), U8.3 (VDD3P3)
unnamed: C40.1, R30.1, Y2.1
unnamed: D1.1 (K), R3.1
unnamed: D2.1 (K), R4.1
unnamed: D3.1 (K), R5.1
unnamed: C17.1, D5.2 (A2), R12.2, SW1.2 (B), U8.5 (GPIO0)
unnamed: D6.2 (A), R14.2
unnamed: C24.1, D7.2 (A2), R20.2, SW2.2 (B), U8.4 (CHIP_PU)
unnamed: D11.2 (A), FB2.1
unnamed: D12.2 (A), R31.1
unnamed: D13.2 (A), R32.1
unnamed: F2.1, FB2.2
unnamed: F2.2, J3.A4 (VBUS), J3.A9 (VBUS), J3.B4 (VBUS), J3.B9 (VBUS)
unnamed: R1.2, U1.7 (EN)
unnamed: R2.2, U2.7 (EN)
unnamed: L1.1, U4.14 (VCC_RF)
unnamed: R7.2, U4.6 (V_BCKP)
unnamed: R6.2, U4.9 (~RESET)
unnamed: R9.2, U5.7 (EN)
unnamed: R10.2, U6.7 (EN)
unnamed: R17.2, U8.33 (SPICLK)
unnamed: R19.2, U8.35 (SPID)
unnamed: R15.2, U8.30 (SPIHD)
unnamed: R18.2, U8.34 (SPIQ)
unnamed: R16.2, U8.31 (SPIWP)
unnamed: U9.51 (5V), U9.52 (5V)
unnamed: U9.49 (GND), U9.50 (GND), U9.72 (GND)
unnamed: C30.1, U10.10 (REGOUT)
unnamed: R22.2, U10.23 (SCL/SCLK)
unnamed: R21.2, U10.24 (SDA/MOSI)
unnamed: C21.1, C55.1, R14.1, U11.6 (VDD)
unnamed: R13.1, U11.9 (~RST)
unnamed: C42.2, U14.6 (BST)
unnamed: C42.1, L4.1, U14.5 (SW)
SPICS0: U7.1 (~CS), U8.32 (SPICS0)
SPID: R19.1, U7.5 (DI/IO_{0})
SPIHD: R15.1, U7.7 (~HOLD/~RESET/IO_{3})
SPIQ: R18.1, U7.2 (DO/IO_{1})
SPISCK: R17.1, U7.6 (CLK)
SPIWP: R16.1, U7.3 (~WP/IO_{2})
VDD_CPU: C1.1, C2.1, C3.1, C4.1, C5.1, C6.1, C7.1, C8.1, C10.1, C11.1, C13.1, C15.1, C16.1, C19.1, C20.1, C23.1, C26.1, C29.1, C31.1, C43.1, C44.1, C45.1, C46.1, C47.1, D3.2 (A), D4.2 (A2), L2.1, L4.2, R1.1, R2.1, R6.1, R7.1, R9.1, R10.1, R12.1, R13.2, R20.1, R21.1, R22.1, R31.2, R32.2, R33.2, R35.1, U1.6 (VDD), U2.6 (VDD), U3.3 (3V3), U4.7 (VCC_IO), U4.8 (VCC), U5.4 (L/R), U5.6 (VDD), U6.4 (L/R), U6.6 (VDD), U8.20 (VDD3P3_RTC), U8.46 (VDD3P3_CPU), U8.55 (VDDA), U8.56 (VDDA), U10.8 (VDDIO), U10.13 (VDD), U10.22 (~CS), U14.1 (FB)
VDD_SPI: C22.1, C25.1, U7.8 (VCC), U8.29 (VDD_SPI)

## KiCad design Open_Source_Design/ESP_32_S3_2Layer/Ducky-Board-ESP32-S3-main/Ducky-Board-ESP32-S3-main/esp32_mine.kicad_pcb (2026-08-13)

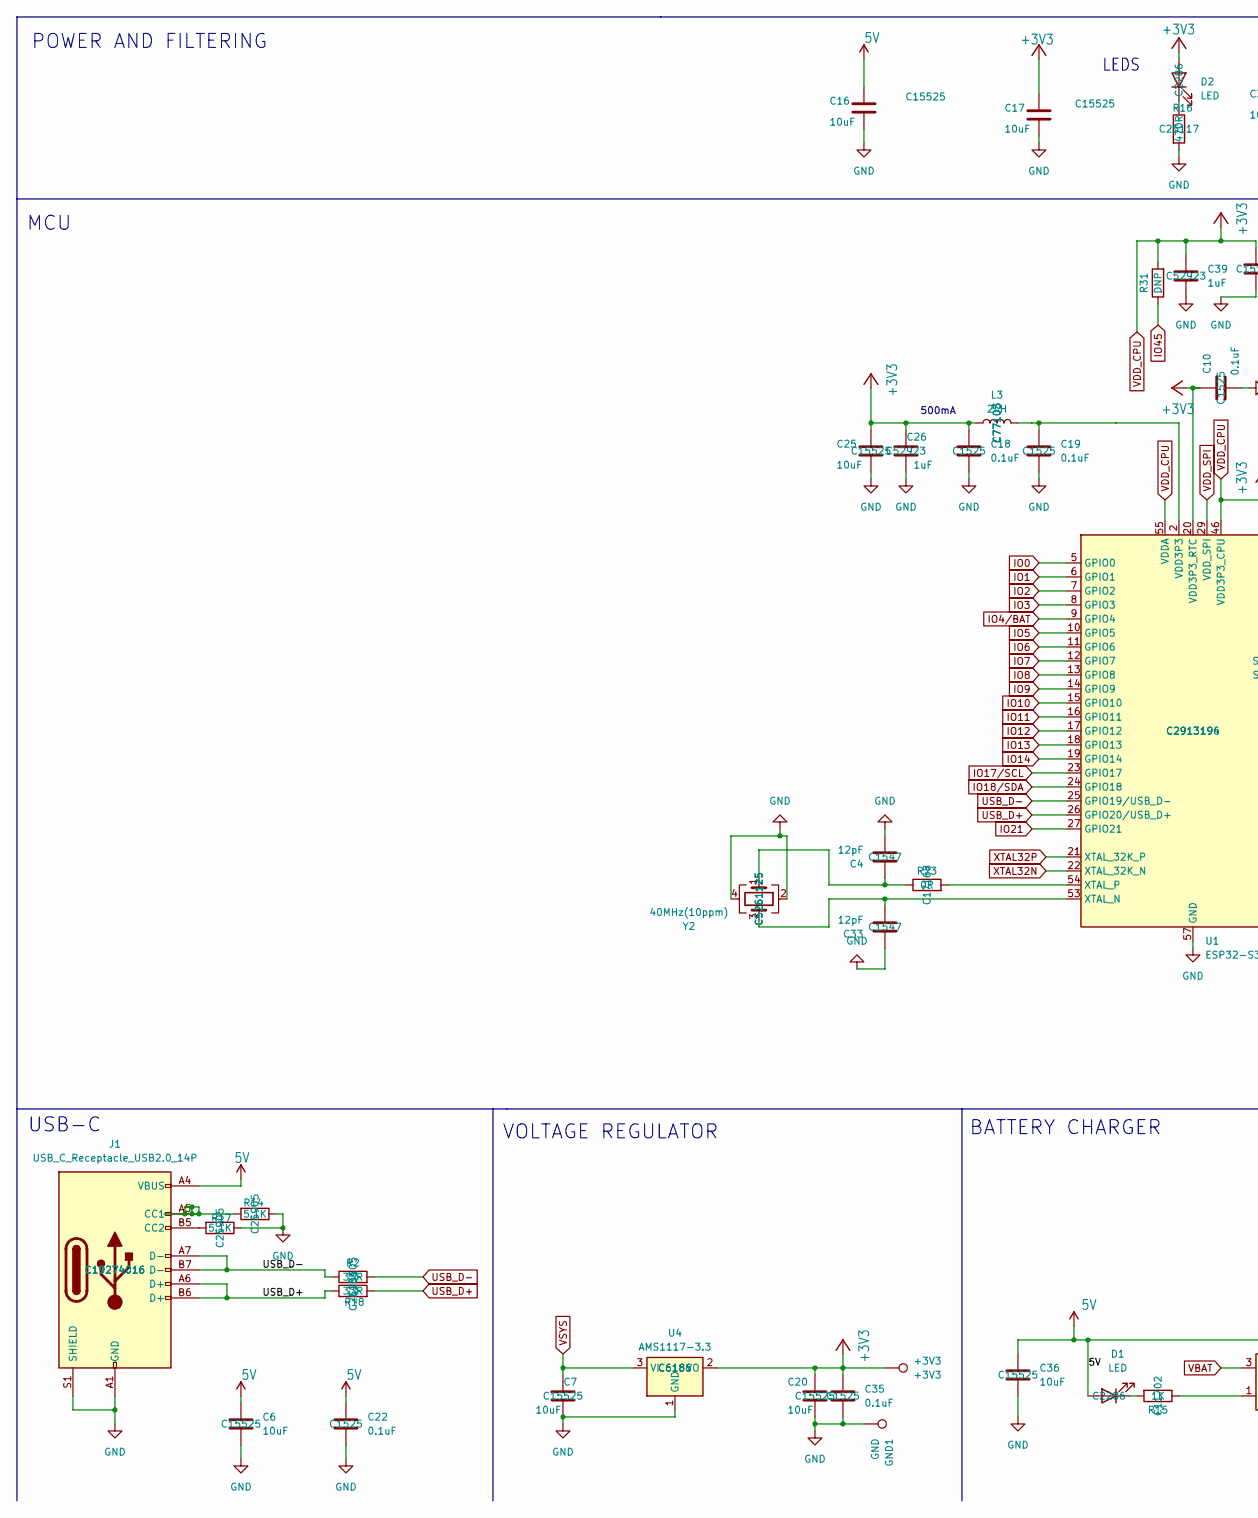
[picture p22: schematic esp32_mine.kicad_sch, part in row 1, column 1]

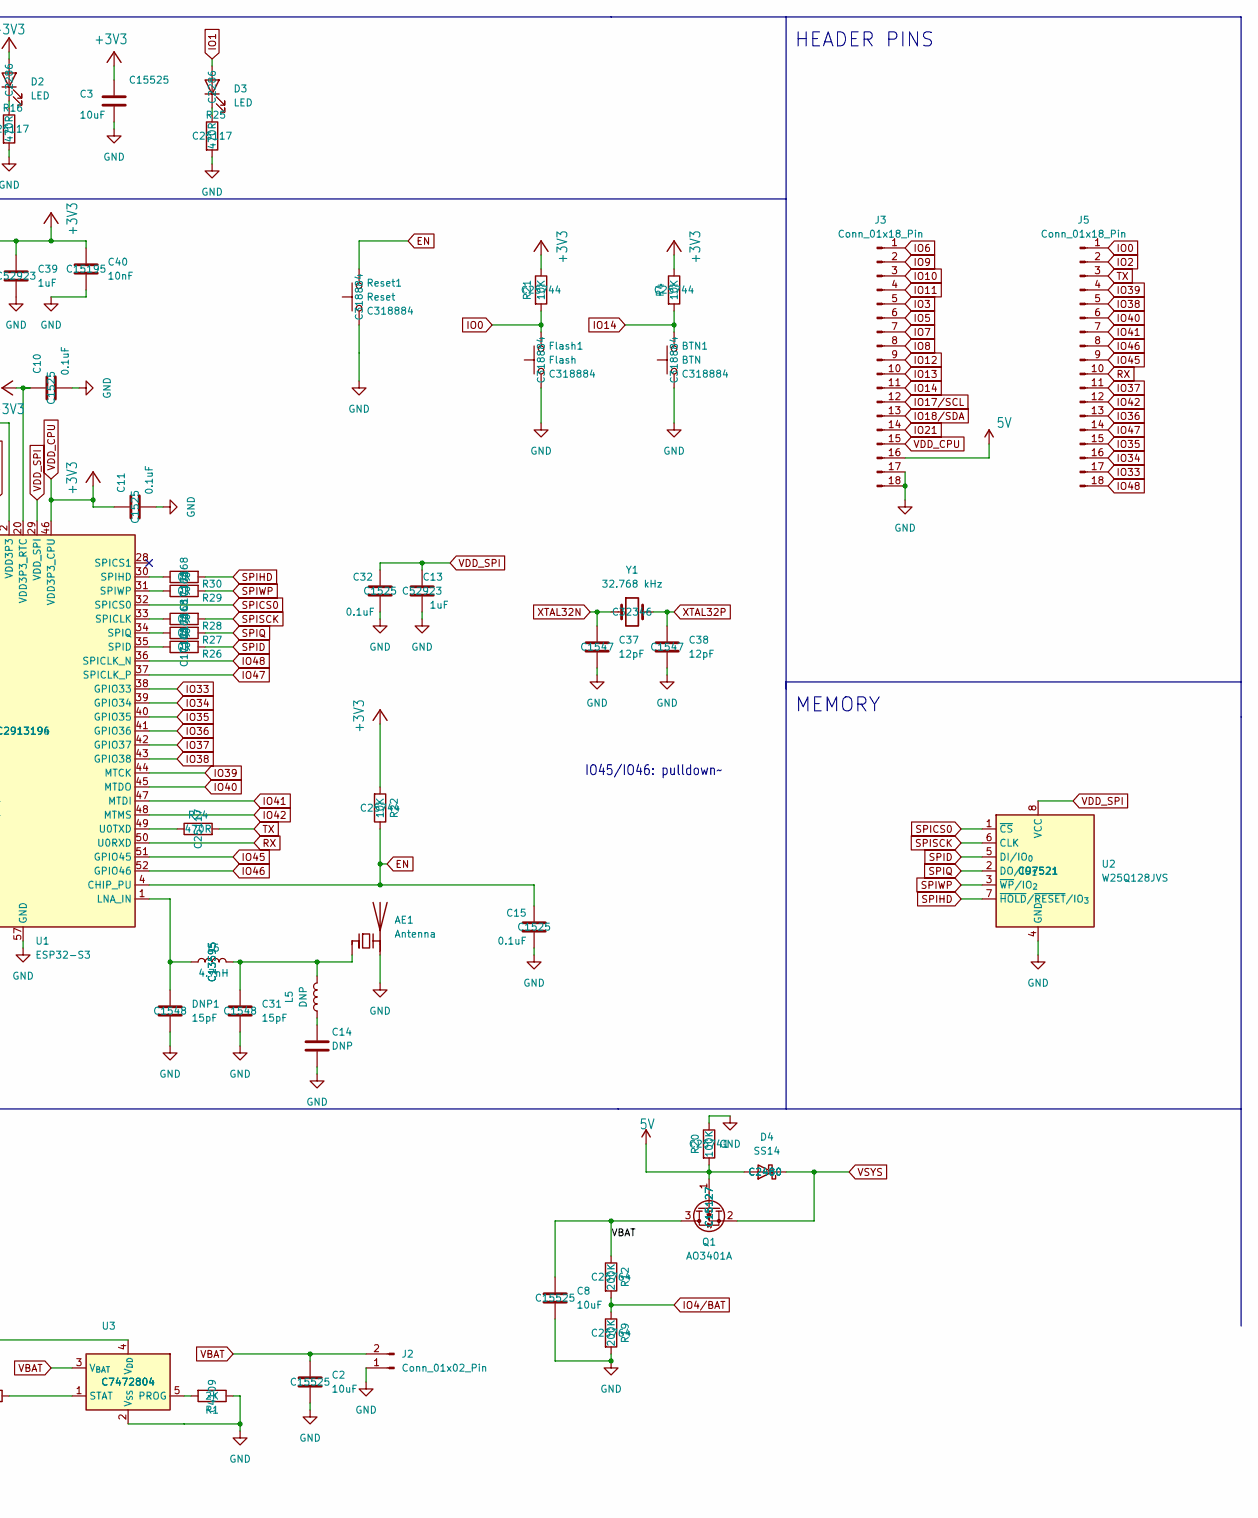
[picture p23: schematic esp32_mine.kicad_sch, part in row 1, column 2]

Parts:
+3V3: +3V3; TestPoint_Pad_D1.0mm
AE1: Antenna; Texas_SWRA117D_2.4GHz_Left
BTN1: BTN; SW_Push_1P1T_XKB_TS-1187A; MNF PART NUMBER C318884; LCSC C318884
C2, C3, C6, C7, C8, C16, C17, C20, C25, C36: 10uF; C_0402_1005Metric; MNF PART NUMBER C15525; LCSC C15525
C4, C33, C37, C38: 12pF; C_0402_1005Metric; MNF PART NUMBER C1547; LCSC C1547
C10, C11, C15, C18, C19, C22, C32, C35: 0.1uF; C_0402_1005Metric; MNF PART NUMBER C1525; LCSC C1525
C13, C26, C39: 1uF; C_0402_1005Metric; MNF PART NUMBER C52923; LCSC C52923
C14: DNP; C_0402_1005Metric
C31: 15pF; C_0402_1005Metric; MNF PART NUMBER C1548; LCSC C1548
C40: 10nF; C_0402_1005Metric; MNF PART NUMBER C15195; LCSC C15195
D1, D2, D3: LED; LED_0603_1608Metric; MNF PART NUMBER C2286; LCSC C2286
D4: SS14; D_SMA; MNF PART NUMBER C2480; LCSC C2480
DNP1: 15pF; C_0402_1005Metric; MNF PART NUMBER C1548; LCSC C1548
Flash1: Flash; SW_Push_1P1T_XKB_TS-1187A; MNF PART NUMBER C318884; LCSC C318884
GND1: GND; TestPoint_Pad_D1.0mm
J1: USB_C_Receptacle_USB2.0_14P; USB_C_Receptacle_HCTL_HC-TYPE-C-16P-01A; MNF PART NUMBER C19274016; LCSC C19274016
J2: Conn_01x02_Pin; PinSocket_1x02_P2.54mm_Vertical
J3, J5: Conn_01x18_Pin; PinHeader_1x18_P2.54mm_Vertical
L3: 2nH; L_0402_1005Metric; MNF PART NUMBER C77103; LCSC C77103
L5: DNP; L_0402_1005Metric
L6: 4.7nH; L_0402_1005Metric; MNF PART NUMBER C13595; LCSC C13595
Q1: AO3401A; SOT-23; MNF PART NUMBER C15127; LCSC C15127
R1: 2K; R_0402_1005Metric; MNF PART NUMBER C4109; LCSC C4109
R2, R18: 33R; R_0402_1005Metric; MNF PART NUMBER C25105; LCSC C25105
R4, R21, R22: 10K; R_0402_1005Metric; MNF PART NUMBER C25744; LCSC C25744
R12, R19: 200K; R_0402_1005Metric; MNF PART NUMBER C25764; LCSC C25764
R14, R17: 5.1K; R_0402_1005Metric; MNF PART NUMBER C25905; LCSC C25905
R15: 1K; R_0402_1005Metric; MNF PART NUMBER C11702; LCSC C11702
R16, R24, R25: 470R; R_0402_1005Metric; MNF PART NUMBER C25117; LCSC C25117
R20: 100K; R_0402_1005Metric; MNF PART NUMBER C25741; LCSC C25741
R23, R26, R27, R28, R29, R30: 0R; R_0402_1005Metric; MNF PART NUMBER C17168; LCSC C17168
R31: DNP; R_0402_1005Metric
Reset1: Reset; SW_Push_1P1T_XKB_TS-1187A; MNF PART NUMBER C318884; LCSC C318884
U1: ESP32-S3; QFN-56-1EP_7x7mm_P0.4mm_EP4x4mm; MNF PART NUMBER C2913196; LCSC C2913194
U2: W25Q128JVS; SOIC-8_5.3x5.3mm_P1.27mm; MNF PART NUMBER C97521; LCSC C97521
U3: MCP73831-2-OT; SOT-23-5; MNF PART NUMBER C7472804; LCSC C7472804
U4: AMS1117-3.3; SOT-223-3_TabPin2; MNF PART NUMBER C6186; LCSC C6186
Y1: 32.768 kHz; Crystal_SMD_3215-2Pin_3.2x1.5mm; MNF PART NUMBER C32346; LCSC C32346
Y2: 40MHz(10ppm); Crystal_SMD_2520-4Pin_2.5x2.0mm; MNF PART NUMBER C5261125; LCSC C5261125

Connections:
5V: C6.1, C16.1, C22.1, C36.1, D1.2 (A), D4.2 (A), J1.A4 (VBUS), J1.A9 (VBUS), J1.B4 (VBUS), J1.B9 (VBUS), J3.16, Q1.1 (G), R20.2, U3.4 (V_{DD})
EN: C15.1, R22.1, Reset1.2, U1.4 (CHIP_PU)
GND: AE1.2 (PCB_Trace), BTN1.1, C2.2, C3.2, C4.2, C6.2, C7.2, C8.2, C10.2, C11.2, C13.2, C14.2, C15.2, C16.2, C17.2, C18.2, C19.2, C20.2, C22.2, C25.2, C26.2, C31.2, C32.2, C33.1, C35.2, C36.2, C37.2, C38.2, C39.2, C40.2, DNP1.2, Flash1.1, GND1.1, J1.A1 (GND), J1.A12 (GND), J1.B1 (GND), J1.B12 (GND), J1.S1 (SHIELD), J2.1, J3.17, J3.18, R1.1, R14.1, R16.2, R17.1, R19.2, R20.1, R25.2, Reset1.1, U1.57 (GND), U2.4 (GND), U3.2 (V_{SS}), U4.1 (GND), Y2.2, Y2.4
IO0: Flash1.2, J5.1, R21.2, U1.5 (GPIO0)
IO1: D3.2 (A), U1.6 (GPIO1)
IO2: J5.2, U1.7 (GPIO2)
IO3: J3.5, U1.8 (GPIO3)
IO4/BAT: R12.2, R19.1, U1.9 (GPIO4)
IO5: J3.6, U1.10 (GPIO5)
IO6: J3.1, U1.11 (GPIO6)
IO7: J3.7, U1.12 (GPIO7)
IO8: J3.8, U1.13 (GPIO8)
IO9: J3.2, U1.14 (GPIO9)
IO10: J3.3, U1.15 (GPIO10)
IO11: J3.4, U1.16 (GPIO11)
IO12: J3.9, U1.17 (GPIO12)
IO13: J3.10, U1.18 (GPIO13)
IO14: BTN1.2, J3.11, R4.2, U1.19 (GPIO14)
IO17/SCL: J3.12, U1.23 (GPIO17)
IO18/SDA: J3.13, U1.24 (GPIO18)
IO21: J3.14, U1.27 (GPIO21)
IO33: J5.17, U1.38 (GPIO33)
IO34: J5.16, U1.39 (GPIO34)
IO35: J5.15, U1.40 (GPIO35)
IO36: J5.13, U1.41 (GPIO36)
IO37: J5.11, U1.42 (GPIO37)
IO38: J5.5, U1.43 (GPIO38)
IO39: J5.4, U1.44 (MTCK)
IO40: J5.6, U1.45 (MTDO)
IO41: J5.7, U1.47 (MTDI)
IO42: J5.12, U1.48 (MTMS)
IO45: J5.9, R31.1, U1.51 (GPIO45)
IO46: J5.8, U1.52 (GPIO46)
IO47: J5.14, U1.37 (SPICLK_P)
IO48: J5.18, U1.36 (SPICLK_N)
unnamed: AE1.1 (FEED), C31.1, L5.2, L6.2
unnamed: C4.1, R23.1, Y2.1
unnamed: C14.1, L5.1
unnamed: C19.1, L3.2, U1.2 (VDD3P3), U1.3 (VDD3P3)
unnamed: D1.1 (K), R15.2
unnamed: D2.1 (K), R16.1
unnamed: D3.1 (K), R25.1
unnamed: J1.A5 (CC1), R14.2
unnamed: J1.B5 (CC2), R17.2
unnamed: DNP1.1, L6.1, U1.1 (LNA_IN)
unnamed: R28.1, U1.33 (SPICLK)
unnamed: R26.1, U1.35 (SPID)
unnamed: R30.1, U1.30 (SPIHD)
unnamed: R27.1, U1.34 (SPIQ)
unnamed: R29.1, U1.31 (SPIWP)
unnamed: R24.1, U1.49 (U0TXD)
unnamed: C33.2, U1.53 (XTAL_N), Y2.3
unnamed: R23.2, U1.54 (XTAL_P)
unnamed: R1.2, U3.5 (PROG)
unnamed: R15.1, U3.1 (STAT)
RX: J5.10, U1.50 (U0RXD)
SPICS0: U1.32 (SPICS0), U2.1 (~CS)
SPID: R26.2, U2.5 (DI/IO_{0})
SPIHD: R30.2, U2.7 (~HOLD/~RESET/IO_{3})
SPIQ: R27.2, U2.2 (DO/IO_{1})
SPISCK: R28.2, U2.6 (CLK)
SPIWP: R29.2, U2.3 (~WP/IO_{2})
TX: J5.3, R24.2
USB_D+: J1.A6 (D+), J1.B6 (D+), R18.1, R18.2, U1.26 (GPIO20/USB_D+)
USB_D-: J1.A7 (D-), J1.B7 (D-), R2.1, R2.2, U1.25 (GPIO19/USB_D-)
VBAT: C2.1, C8.1, J2.2, Q1.3 (D), R12.1, U3.3 (V_{BAT})
VDD_CPU: +3V3.1, C3.1, C10.1, C11.1, C17.1, C18.1, C20.1, C25.1, C26.1, C35.1, C39.1, C40.1, D2.2 (A), J3.15, L3.1, R4.1, R21.1, R22.2, R31.2, U1.20 (VDD3P3_RTC), U1.46 (VDD3P3_CPU), U1.55 (VDDA), U1.56 (VDDA), U4.2 (VO)
VDD_SPI: C13.1, C32.1, U1.29 (VDD_SPI), U2.8 (VCC)
VSYS: C7.1, D4.1 (K), Q1.2 (S), U4.3 (VI)
XTAL32N: C37.1, U1.22 (XTAL_32K_N), Y1.1
XTAL32P: C38.1, U1.21 (XTAL_32K_P), Y1.2

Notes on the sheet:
BATTERY CHARGER
VOLTAGE REGULATOR
500mA
LEDS
MCU
HEADER PINS
MEMORY
POWER AND FILTERING
IO45/IO46: pulldown~~{}
USB-C

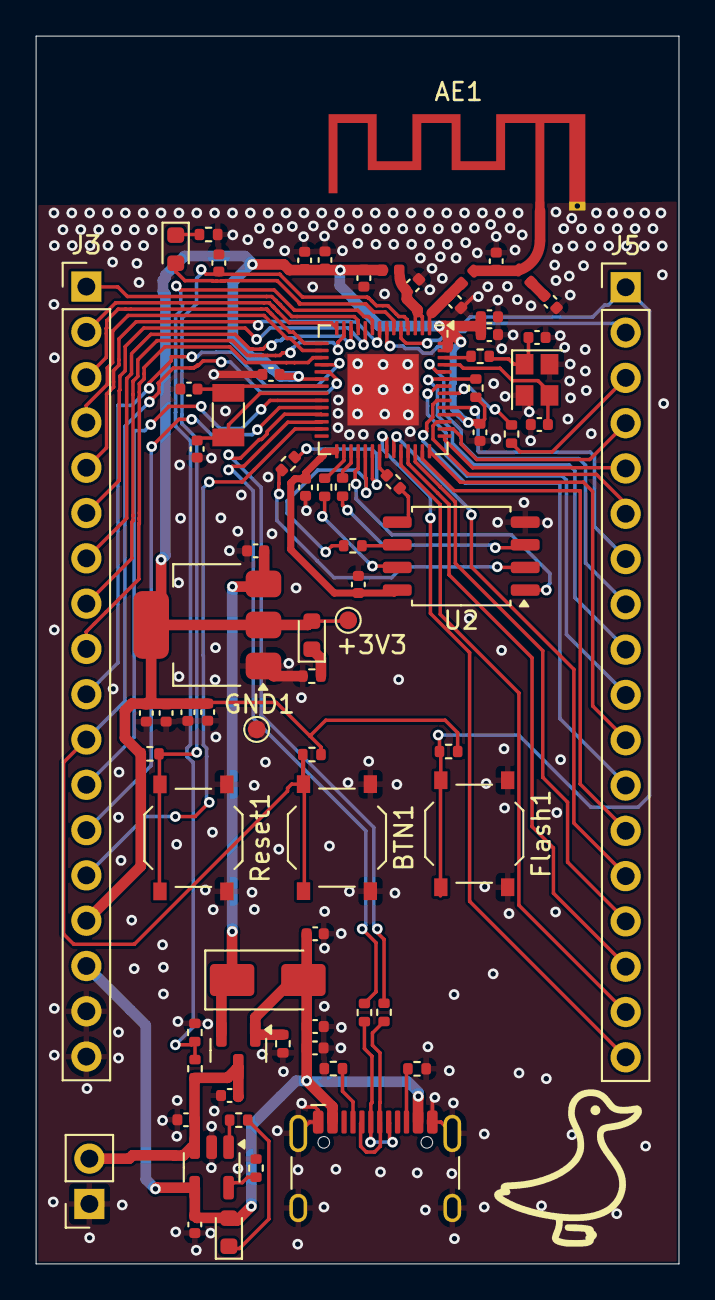
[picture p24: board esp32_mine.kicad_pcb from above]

Board: 2 copper layers, 36.0 x 68.8 mm, 75 parts (0 on the bottom side), 71 nets.

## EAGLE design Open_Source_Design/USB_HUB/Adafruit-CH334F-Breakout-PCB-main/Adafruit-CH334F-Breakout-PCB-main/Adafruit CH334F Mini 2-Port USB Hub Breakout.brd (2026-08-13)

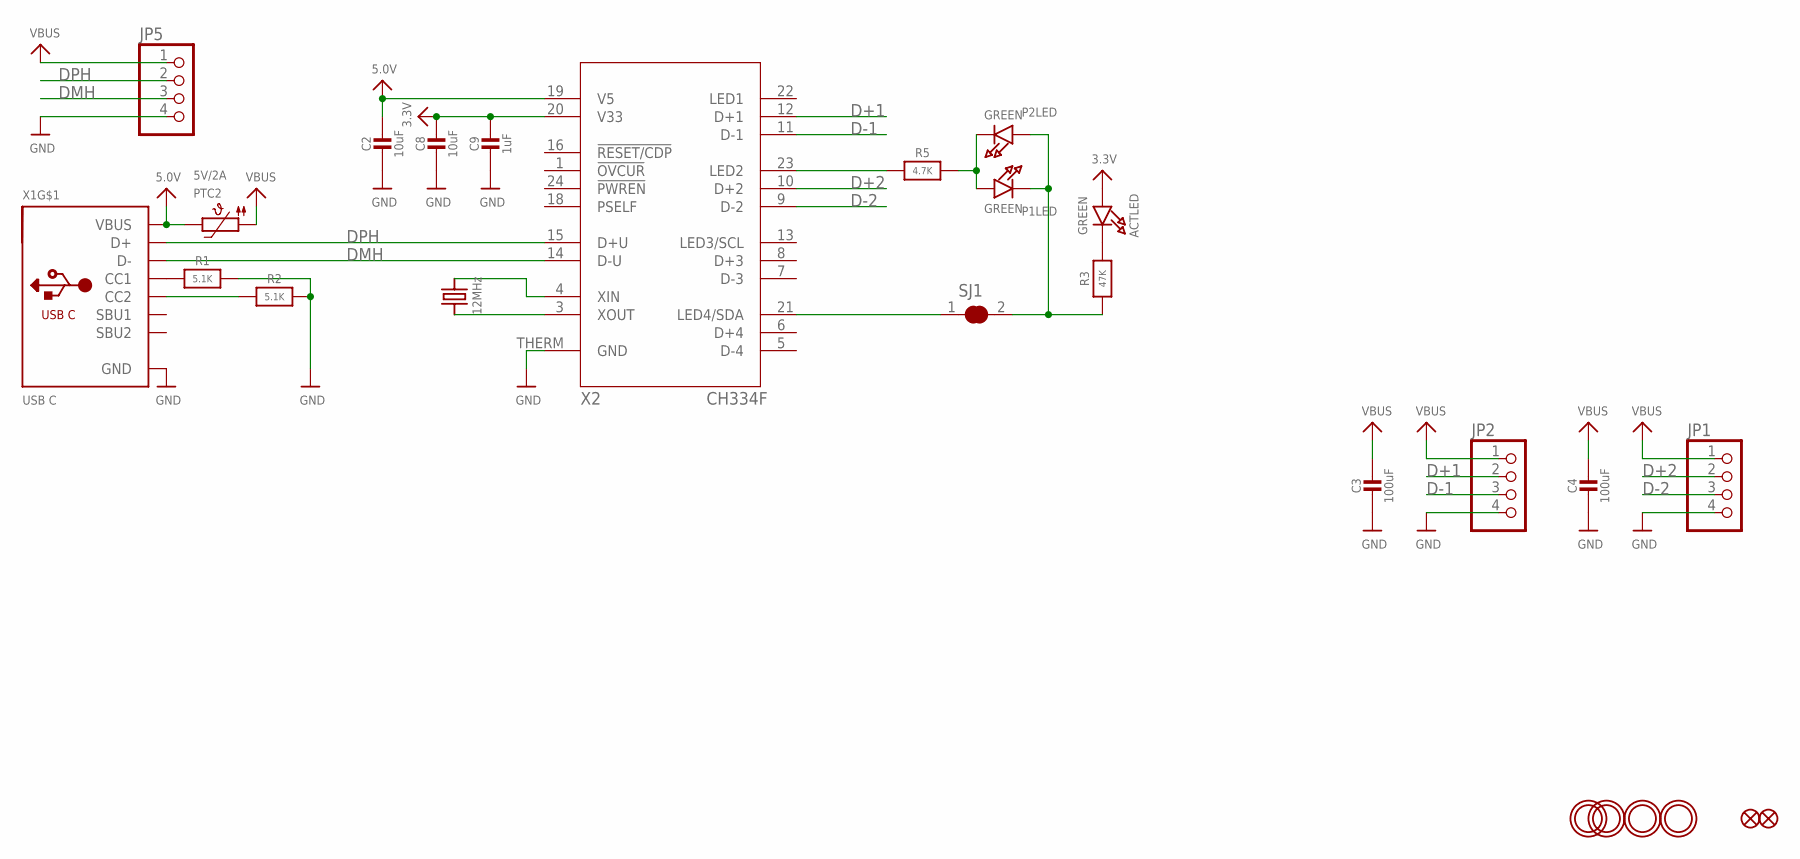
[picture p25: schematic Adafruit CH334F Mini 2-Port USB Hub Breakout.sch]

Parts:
ACTLED: GREEN; CHIPLED_0603_NOOUTLINE
C2, C8: 10uF; 0805-NO
C3, C4: 100uF; _1206
C9: 1uF; 0603-NO
FID1, FID2: FIDUCIAL_0.5MM
JP1, JP2, JP5: HEADER-1X4ROUND; 1X04_ROUND
P1LED, P2LED: GREEN; CHIPLED_0603_NOOUTLINE
PTC2: 5V/2A; 0805-NO
R1, R2: 5.1K; 0603-NO
R3: 47K; 0603-NO
R5: 4.7K; 0603-NO
SJ1: SOLDERJUMPER_CLOSED; SOLDERJUMPER_CLOSEDWIRE
U$23, U$28, U$29, U$31: MOUNTINGHOLE2.5; MOUNTINGHOLE_2.5_PLATED
X1: USB C; USB_C_CUSB31-CFM2AX-01-X
X2: CH334F; QFN24_4MM
Y1: 12MHz; CRYSTAL_2.5X2

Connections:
3.3V: ACTLED.A, C8.1, C9.1, X2.20 (V33)
5.0V: C2.1, PTC2.2, X1.A4B9 (VBUS), X1.B4A9 (VBUS), X2.19 (V5)
D+1: JP2.2, X2.12 (D+1)
D+2: JP1.2, X2.10 (D+2)
D-1: JP2.3, X2.11 (D-1)
D-2: JP1.3, X2.9 (D-2)
DMH: JP5.3, X1.A7 (D-), X1.B7 (D-), X2.14 (D-U)
DPH: JP5.2, X1.A6 (D+), X1.B6 (D+), X2.15 (D+U)
GND: C2.2, C3.2, C4.2, C8.2, C9.2, JP1.4, JP2.4, JP5.4, R1.2, R2.2, X1.A1B12 (GND), X1.B1A12 (GND), X2.THERM (GND)
unnamed: R1.1, X1.A5 (CC1)
unnamed: R2.1, X1.B5 (CC2)
unnamed: X2.3 (XOUT), Y1.1
unnamed: X2.4 (XIN), Y1.3 (2)
unnamed: ACTLED.C, R3.2
unnamed: P1LED.C, P2LED.A, R3.1, SJ1.2
unnamed: SJ1.1, X2.21 (LED4/SDA)
unnamed: P1LED.A, P2LED.C, R5.2
unnamed: R5.1, X2.23 (LED2)
VBUS: C3.1, C4.1, JP1.1, JP2.1, JP5.1, PTC2.1

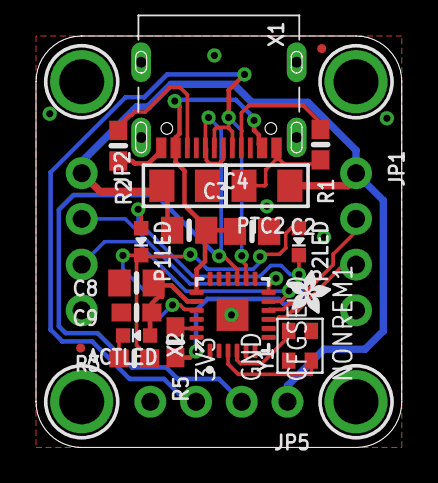
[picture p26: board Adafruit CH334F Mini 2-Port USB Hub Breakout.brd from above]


Board: 2 copper layers, 20.3 x 22.9 mm, 49 parts (9 on the bottom side), 19 nets.

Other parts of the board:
PLABEL0: PLABEL0
PLABEL1: PLABEL1
PLABEL3: PLABEL3
PLABEL5: PLABEL5
PLABEL6: PLABEL6
PLABEL7: PLABEL7
PLABEL8: PLABEL8
PLABEL11: PLABEL11
PLABEL13: PLABEL13
PLABEL19: PLABEL19
PLABEL21: PLABEL21
PLABEL22: PLABEL22
PLABEL23: PLABEL23
PLABEL24: PLABEL24
PLABEL26: PLABEL26
PLABEL27: PLABEL27
PLABEL30: PLABEL30
PLABEL31: PLABEL31
PLABEL32: PLABEL32
PLABEL33: PLABEL33
U$11: ADAFRUIT_2.5MM
U$33: ADAFRUIT_5MM
U$34: PCBFEAT-REV-040

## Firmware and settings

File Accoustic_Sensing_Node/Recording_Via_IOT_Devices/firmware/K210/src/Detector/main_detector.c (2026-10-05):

/*
 * main.c - K210 acoustic survivor detector. Everything runs on device.
 *
 * Captures four microphones SIMULTANEOUSLY, runs the three-feature voice
 * detector on one of them, and when it fires, computes a bearing from all
 * four. Sends a 16-byte result packet, not audio.
 *
 * ============================================================================
 * WHY SIMULTANEOUS, WHERE THE PREVIOUS BUILD CYCLED
 * ============================================================================
 * k210_1mic.c streams one mic at a time so the link stays at 21%
 * utilisation. That was right for collecting a per-mic dataset and for
 * proving the wiring. It is useless for direction finding: TDOA measures
 * the delay between microphones, so they must be the same instant.
 *
 * Streaming four channels would need 128 kB/s, 85% of the 1.5 Mbaud link.
 * Computing on device sidesteps that entirely - the bearing is 16 bytes at
 * 10 Hz, about 160 B/s, 0.1% of the link.
 *
 * ============================================================================
 * COST, MEASURED
 * ============================================================================
 *   DOA    4 x 1024-pt FFT + 2 lag searches = 110 k ops per estimate
 *          at 10 Hz that is 0.28% of a 400 MHz core
 *   VAD    harmonicity dominates: 227 lags x 512 samples x 31 frames
 *          ~3.6 M MAC per second of audio, roughly 1% duty cycle
 *   Total well under 2%. There is no need to economise here.
 *
 * ============================================================================
 * BEFORE THIS WILL MEAN ANYTHING
 * ============================================================================
 *   1. All four slots must pass the probe in k210_1mic.c. A wrong slot map
 *      gives a confident bearing rotated by an unknown amount, and nothing
 *      on screen will hint at it.
 *   2. MIC_EAST/WEST/NORTH/SOUTH below must match the physical positions.
 *      Tap each mic and confirm against the #tap lines.
 *   3. Both baselines must be EQUAL. The angle comes from a ratio of two
 *      delays, so the absolute spacing cancels - but only if dx == dy.
 * ========================================================================= */

#include <stdint.h>
#include <string.h>
#include <math.h>      /* log10f - the SDK builds with -Werror */
#include "fpioa.h"
#include "i2s.h"
#include "dmac.h"
#include "sysctl.h"
#include "uarths.h"

#include "sar_features.h"
#include "sar_doa.h"
#include "vad3_model.h"

/* ---- Pins: match what the Recorder proved ------------------------------ */
#define IO_SCLK      18
#define IO_WS        19
#define IO_SD1       23        /* I2S_CHANNEL_0 -> slots 0, 1 */
#define IO_SD2       22        /* I2S_CHANNEL_1 -> slots 2, 3 */

#define SAMPLE_SHIFT 13        /* smallest value with clip=0 on every slot */

/* Slot -> physical position, from the tap test.
 *
 * The two pairs must be OPPOSING corners, and the pairs perpendicular to
 * each other - that is what makes atan2(lag_y, lag_x) a bearing rather
 * than a number. Slots 0/3 are one diagonal, 1/2 the other. */
#define MIC_EAST     0
#define MIC_WEST     3
#define MIC_NORTH    1
#define MIC_SOUTH    2

#define NUM_SLOTS    4
#define BLK          256
#define SAMPLE_RATE  16000
#define SAMPLE_SHIFT 13        /* set from the k210_1mic.c #shift scan      */
#define DMA_CH       DMAC_CHANNEL1
#define PLL2_FREQ    49152000UL
#define BAUD_RATE    1500000UL



/* Which mic feeds the voice detector. Any will do; East is arbitrary. */
#define MIC_VAD      MIC_EAST

/* Emit a packet at most this often, and only while speech is detected. */
#define REPORT_HZ    20
#define BLOCKS_PER_REPORT ((SAMPLE_RATE / BLK) / REPORT_HZ)

/* Compute a bearing for ANY sound above this level, not only for speech.
 *
 * Gating DOA on the VAD was wrong for this application. The display shows
 * human AND non-human sources, so the bearing has to exist before the
 * classifier has an opinion - otherwise a machine running nearby is
 * invisible rather than shown as a blue circle. It also means one
 * mis-tuned threshold makes the whole screen empty, which is exactly what
 * happened.
 *
 * So: localise everything audible, classify separately, and let the host
 * decide where the human/non-human line sits. -45 dBFS is above the mic's
 * own noise floor but well below normal speech. */
#define DOA_LEVEL_GATE_DB  (-45.0f)

/* Stream one microphone's audio alongside the DOA packets. Costs 32 kB/s
 * against a 150 kB/s link - 21% utilisation, the same as the Recorder
 * build - so you can watch a waveform and a bearing at the same time.
 *
 * Set to 0 to send bearings only (160 B/s), which is what a deployed node
 * would do over LoRa. */
#define STREAM_AUDIO   1

/* Send a packet even with no detection, so the host can see we are alive.
 * Counted in REPORT ticks, not raw blocks: a block-based counter only fires
 * when it happens to coincide with a report tick, so most heartbeats are
 * silently skipped and the link looks dead during quiet periods. */
#define HEARTBEAT_REPORTS  REPORT_HZ               /* once a second */

static uint32_t g_raw[2][BLK * NUM_SLOTS];

/* DOA needs the last DOA_FFT_N samples of every mic, aligned. */
static float g_doa_ring[NUM_SLOTS][DOA_FFT_N];
static int   g_doa_head;

/* The VAD needs a 1 s window of one mic. */
static float g_vad_ring[SF_WINDOW];
static int   g_vad_head;
static int   g_vad_filled;

static sf_state_t g_sf[NUM_SLOTS];
static uint8_t    g_seq;


/* ============================================================================
 * Text and packet output
 * ========================================================================= */
static void put(const char *s) { while (*s) uarths_putchar(*s++); }

static void put_u32(uint32_t v)
{
    char b[11]; int i = 10; b[i] = 0;
    if (!v) { uarths_putchar('0'); return; }
    while (v && i) { b[--i] = (char)('0' + v % 10); v /= 10; }
    put(&b[i]);
}

/* Result packet, 16 bytes:
 *
 *   0-1  magic 0x5A 0xA6  (distinct from the audio magic 0x5A 0xA5)
 *   2    type 0x10 (detection report)
 *   3    seq, wraps at 256
 *   4-5  angle x10, int16, -10 means no confident bearing
 *   6-7  doa confidence x1000, int16
 *   8-9  vad score x100, int16 (the smoothed logit)
 *   10-11 level dBFS x10, int16
 *   12   speech flag
 *   13   warm flag - 0 while the noise floor is still filling
 *   14-15 lag_x x100, int16   } the raw per-axis delays, so a bad bearing
 *   16-17 lag_y x100, int16   } can be diagnosed without reflashing
 *   18    xor8 of bytes 2..17
 *   19    pad
 *
 * Same magic word as the audio format, but a distinct type byte, so a host
 * reading either can tell them apart without guessing from the length. */
/* Audio frame, byte-identical to the Recorder build's format so record.py
 * reads it unchanged:
 *   [0x5A][0xA5][seq:u8][blk:u16 LE][nch:u8][payload][sum16 LE]
 *
 * Note the DOA packet below uses a DIFFERENT magic word, 0x5A 0xA6. Sharing
 * one magic and distinguishing by a type byte would collide whenever an
 * audio sequence number happened to equal that type value - rare, and
 * therefore exactly the kind of fault that appears once during a demo and
 * cannot be reproduced afterwards. */
static uint8_t g_aseq;

static void send_audio(const float *x, int n)
{
    uint16_t sum = 0;
    uarths_putchar(0x5A);
    uarths_putchar(0xA5);
    uarths_putchar((char)g_aseq++);
    uarths_putchar((char)(n & 0xFF));
    uarths_putchar((char)((n >> 8) & 0xFF));
    uarths_putchar((char)1);
    for (int i = 0; i < n; ++i) {
        float v = x[i] * 32768.0f;
        if (v >  32767.0f) v =  32767.0f;
        if (v < -32768.0f) v = -32768.0f;
        const int16_t s = (int16_t)v;
        const uint8_t lo = (uint8_t)(s & 0xFF), hi = (uint8_t)((s >> 8) & 0xFF);
        uarths_putchar((char)lo); sum = (uint16_t)(sum + lo);
        uarths_putchar((char)hi); sum = (uint16_t)(sum + hi);
    }
    uarths_putchar((char)(sum & 0xFF));
    uarths_putchar((char)((sum >> 8) & 0xFF));
}

static void send_report(float angle, float conf, float score,
                        float level_db, int speech, int warm,
                        float lag_x, float lag_y)
{
    uint8_t p[20];
    int16_t a10 = (int16_t)(angle * 10.0f);
    int16_t c1k = (int16_t)(conf * 1000.0f);
    int16_t s100 = (int16_t)(score * 100.0f);
    int16_t l10 = (int16_t)(level_db * 10.0f);

    p[0] = 0x5A; p[1] = 0xA6; p[2] = 0x10; p[3] = g_seq++;
    p[4] = (uint8_t)(a10 & 0xFF);  p[5] = (uint8_t)((a10 >> 8) & 0xFF);
    p[6] = (uint8_t)(c1k & 0xFF);  p[7] = (uint8_t)((c1k >> 8) & 0xFF);
    p[8] = (uint8_t)(s100 & 0xFF); p[9] = (uint8_t)((s100 >> 8) & 0xFF);
    p[10] = (uint8_t)(l10 & 0xFF); p[11] = (uint8_t)((l10 >> 8) & 0xFF);
    p[12] = (uint8_t)speech;
    p[13] = (uint8_t)warm;
    int16_t lx = (int16_t)(lag_x * 100.0f), ly = (int16_t)(lag_y * 100.0f);
    p[14] = (uint8_t)(lx & 0xFF); p[15] = (uint8_t)((lx >> 8) & 0xFF);
    p[16] = (uint8_t)(ly & 0xFF); p[17] = (uint8_t)((ly >> 8) & 0xFF);
    uint8_t x = 0;
    for (int i = 2; i < 18; ++i) x ^= p[i];
    p[18] = x; p[19] = 0;
    for (int i = 0; i < 20; ++i) uarths_putchar((char)p[i]);
}


/* ============================================================================
 * Setup
 * ========================================================================= */
static void clocks_init(void)
{
    /* PLL0/PLL1 before uarths_config: the UART divisor is computed from the
     * CPU clock at that moment, so changing PLL0 later invalidates it. */
    sysctl_pll_set_freq(SYSCTL_PLL0, 320000000UL);
    sysctl_pll_set_freq(SYSCTL_PLL1, 160000000UL);
    sysctl_pll_set_freq(SYSCTL_PLL2, PLL2_FREQ);
}

static void uart_init(void)
{
    fpioa_set_function(4, FUNC_UARTHS_RX);
    fpioa_set_function(5, FUNC_UARTHS_TX);
    uarths_init();
    uarths_config(BAUD_RATE, UARTHS_STOP_1);
}

static void pins_init(void)
{
    fpioa_set_function(IO_SCLK, FUNC_I2S0_SCLK);
    fpioa_set_function(IO_WS,   FUNC_I2S0_WS);
    fpioa_set_function(IO_SD1,  FUNC_I2S0_IN_D0);
    fpioa_set_function(IO_SD2,  FUNC_I2S0_IN_D1);
}

static void i2s_setup(void)
{
    dmac_init();
    i2s_init(I2S_DEVICE_0, I2S_RECEIVER, 0xF);   /* 2 bits per stereo chan */

    i2s_rx_channel_config(I2S_DEVICE_0, I2S_CHANNEL_0,
                          RESOLUTION_32_BIT, SCLK_CYCLES_32,
                          TRIGGER_LEVEL_4, STANDARD_MODE);
    i2s_rx_channel_config(I2S_DEVICE_0, I2S_CHANNEL_1,
                          RESOLUTION_32_BIT, SCLK_CYCLES_32,
                          TRIGGER_LEVEL_4, STANDARD_MODE);

    /* Returns the BIT clock, not the sample rate - divide by 64 and allow
     * the PLL's rounding, or a healthy chain reports a mismatch over an
     * inaudible 0.08%. */
    const uint32_t bclk = i2s_set_sample_rate(I2S_DEVICE_0, SAMPLE_RATE);
    put("#i2s rate="); put_u32(bclk / 64u);
    put((bclk / 64u > 15900u && bclk / 64u < 16100u) ? " OK\r\n" : " *** BAD ***\r\n");
}


/* ============================================================================
 * Main
 * ========================================================================= */
int main(void)
{
    clocks_init();
    uart_init();
    put("\r\n#K210 detector: 4 mics simultaneous, VAD + DOA on device\r\n");
    put("#spacing_mm="); put_u32((uint32_t)DOA_SPACING_MM);
    put(" report_hz=");  put_u32(REPORT_HZ);
    put(" max_lag_x100="); put_u32((uint32_t)(DOA_MAX_LAG * 100.0f));
    put("\r\n#features:");
    for (int i = 0; i < VAD_N_FEATURES; ++i) {
        put(" "); put(VAD_FEATURE_NAMES[i]);
    }
    put("\r\n");

    pins_init();
    i2s_setup();

    for (int m = 0; m < NUM_SLOTS; ++m) sf_init(&g_sf[m]);
    memset(g_doa_ring, 0, sizeof(g_doa_ring));
    memset(g_vad_ring, 0, sizeof(g_vad_ring));
    g_doa_head = g_vad_head = g_vad_filled = 0;
    g_seq = 0;
    g_aseq = 0;

    static float chan[NUM_SLOTS][BLK];
    static float win[SF_WINDOW];
    static float dwin[NUM_SLOTS][DOA_FFT_N];

    int cur = 0;
    uint32_t blocks = 0;
    uint32_t reports = 0;
    float last_score = 0.0f;
    int   last_speech = 0;

    i2s_receive_data_dma(I2S_DEVICE_0, g_raw[cur], BLK * NUM_SLOTS, DMA_CH);
    put("#running\r\n");

    for (;;) {
        dmac_wait_done(DMA_CH);
        const int done = cur;
        cur ^= 1;
        /* Re-arm BEFORE processing, or capture stops for the duration and
         * you get dropouts with no error anywhere. */
        i2s_receive_data_dma(I2S_DEVICE_0, g_raw[cur], BLK * NUM_SLOTS, DMA_CH);

        /* --- de-interleave. All NUM_SLOTS words in a frame were captured on
         * the same word-select period, i.e. the same instant. That
         * simultaneity is the entire basis of the bearing, so the layout is
         * taken exactly as the hardware produced it. --- */
        for (int f = 0; f < BLK; ++f) {
            for (int m = 0; m < NUM_SLOTS; ++m) {
                int32_t v = (int32_t)g_raw[done][f * NUM_SLOTS + m] >> SAMPLE_SHIFT;
                if (v >  32767) v =  32767;      /* saturate, never truncate */
                if (v < -32768) v = -32768;
                chan[m][f] = (float)v / 32768.0f;
            }
        }

        /* --- high-pass each channel with ITS OWN filter state, identical
         * coefficients. Same filter means same phase shift on every channel,
         * so the DIFFERENCE between them - the only thing DOA measures -
         * survives untouched. Different coefficients per channel would
         * destroy the array while each waveform still looked healthy. --- */
        for (int m = 0; m < NUM_SLOTS; ++m) {
            sf_highpass(&g_sf[m], chan[m], BLK);
            for (int f = 0; f < BLK; ++f)
                g_doa_ring[m][(g_doa_head + f) % DOA_FFT_N] = chan[m][f];
        }
        g_doa_head = (g_doa_head + BLK) % DOA_FFT_N;

        /* --- VAD channel: noise floor first, then the ring --- */
        sf_update_noise_floor(&g_sf[MIC_VAD], chan[MIC_VAD], BLK);
        for (int f = 0; f < BLK; ++f)
            g_vad_ring[(g_vad_head + f) % SF_WINDOW] = chan[MIC_VAD][f];
        g_vad_head = (g_vad_head + BLK) % SF_WINDOW;
        if (g_vad_filled < SF_WINDOW) g_vad_filled += BLK;

#if STREAM_AUDIO
        /* Audio goes out every block. The DOA gate below only controls how
         * often a BEARING is computed - it must not gate the audio, or the
         * waveform arrives in 100 ms bursts with gaps. */
        send_audio(chan[MIC_VAD], BLK);
#endif

        blocks++;
        if ((blocks % BLOCKS_PER_REPORT) != 0) continue;
        if (g_vad_filled < SF_WINDOW) continue;
        reports++;

        /* --- unwrap the VAD ring oldest-first --- */
        for (int i = 0; i < SF_WINDOW; ++i)
            win[i] = g_vad_ring[(g_vad_head + i) % SF_WINDOW];

        float feat[SF_N_FEATURES];
        sf_extract(&g_sf[MIC_VAD], win, feat);

        /* vad3_model.h has the scaler folded into the weights - do NOT
         * normalise here, just dot and smooth the SCORE (not the boolean),
         * which is how the model was evaluated during training. */
        float score = vad_score(feat);
        score = sf_smooth_score(&g_sf[MIC_VAD], score, VAD_SMOOTH_K);
        const int speech = vad_is_speech(score);
        const int warm = sf_warm(&g_sf[MIC_VAD]);
        last_score = score;

        /* --- bearing, only when there is something worth pointing at.
         * Skipping DOA on silence is not about saving cycles - it stops the
         * correlator locking onto room noise and reporting a confident
         * direction to nothing. --- */
        float p = 0.0f;
        for (int i = 0; i < SF_WINDOW; ++i) p += win[i] * win[i];
        const float level_db = 10.0f * log10f(p / (float)SF_WINDOW + 1e-12f);

        doa_result_t doa;
        memset(&doa, 0, sizeof(doa));
        doa.angle_deg = -1.0f;

        if (warm && level_db > DOA_LEVEL_GATE_DB) {
            for (int m = 0; m < NUM_SLOTS; ++m)
                for (int i = 0; i < DOA_FFT_N; ++i)
                    dwin[m][i] = g_doa_ring[m][(g_doa_head + i) % DOA_FFT_N];
            doa_estimate(dwin[MIC_EAST], dwin[MIC_WEST],
                         dwin[MIC_NORTH], dwin[MIC_SOUTH], &doa);
        }

        /* Report every tick once warm. At 10 Hz that is 160 B/s - there is
         * no reason to be stingy, and a screen that only updates when the
         * VAD agrees looks broken while you are tuning it. */
        if (warm || (reports % HEARTBEAT_REPORTS) == 0) {
            send_report(doa.valid ? doa.angle_deg : -1.0f,
                        doa.confidence, score, level_db, speech, warm,
                        doa.lag_x, doa.lag_y);
        }
        last_speech = speech;
        (void)last_score; (void)last_speech;
    }
    return 0;
}

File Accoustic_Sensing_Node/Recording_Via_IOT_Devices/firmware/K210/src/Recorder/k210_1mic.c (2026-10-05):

/*
 * main.c - K210 4-mic array. Probes first, then streams ONE mic at a time.
 *
 * ============================================================================
 * WHAT THIS BUILD ADDS
 * ============================================================================
 *
 * (1) "#switch mic=0" IS NOW SENT BEFORE THE FIRST FRAME.  [BUG FIX]
 *
 *     The previous version only printed that line when the mic CHANGED. So
 *     the first window - three whole seconds of mic 0 - arrived at the host
 *     with no marker in front of it. record.py starts with current_mic =
 *     None and tags anything before the first marker as "UNKNOWN", so
 *     mic 0's opening audio went into a file called UNKNOWN and vanished
 *     from the per-mic split. Nothing errored. The recording just quietly
 *     lost its first slice.
 *
 * (2) LIVE MIC SELECTION over the same UART.
 *
 *     Send a key while it runs:
 *         0 1 2 3   lock onto that mic and stay there
 *         c         resume cycling every SWITCH_SECONDS
 *         p         print one #stat line per slot without stopping
 *         ?         reprint the key list
 *
 *     Locking is what you want for "listen to one mic at a time": pick a
 *     mic, leave it, tap that microphone, confirm the audio moves. Cycling
 *     is for unattended capture of all four in one pass.
 *
 *     Every selection re-emits "#switch mic=N", so the host stays in step
 *     whether the change came from the timer or from your keyboard.
 *
 * (3) DIAGNOSTICS RUN BEFORE STREAMING, NOT DURING.
 *
 *     Previously the raw dump and shift scan fired at block 4 - after four
 *     binary frames had already gone out - injecting text into the middle
 *     of the stream. record.py survives that, because it resyncs on the
 *     magic word and harvests '#' lines, but it is needless mess. There is
 *     now an explicit probe phase, then a single transition, then binary.
 *
 * (4) SAMPLE_SHIFT IS 13, NOT 15.
 *
 *     Measured on this board at 15: peak p2p 5005 of 65535, i.e. 7.6% of
 *     full scale, about four of sixteen bits doing any work. The boot scan
 *     showed clip=9 at shift 12 and clip=0 at 14, so 13 is the smallest
 *     safe step. Re-read the #shift lines after this change - the second
 *     data line was not part of the run that number came from.
 *
 * ============================================================================
 * THE FAULTS THE PROBE DISTINGUISHES
 * ============================================================================
 *   L/R STRAPPING. Two INMP441s share one SD line by taking opposite halves
 *     of the frame: one L/R to GND, the other to VDD. Strapped alike, they
 *     drive the same half simultaneously - two push-pull outputs fighting.
 *     That slot reads garbage, the other reads nothing.
 *   WRONG PIN. 18/19/20/21 are proven on this board.
 *   RESOLUTION vs SHIFT. 16_BIT puts the sample in the LOW 16 bits; 32_BIT
 *     puts 24 bits MSB-aligned high. One function below owns that
 *     conversion so the two cannot drift apart.
 *   WRAPPING vs CLIPPING. A cast to int16_t truncates, it does not clamp -
 *     0x3F0000 >> 13 = 129024 becomes -2048, so an overloaded channel
 *     turns into a sawtooth that looks exactly like a floating pin.
 *     word_to_sample saturates instead.
 *
 * ============================================================================
 * SEQUENCE
 * ============================================================================
 *   PROBE_SECONDS of text-only diagnostics, then streaming begins.
 *   Set PROBE_SECONDS to 0 once you trust the wiring.
 *   Set MIC_SLOT_OK to 0 to stay in the probe forever.
 */

#include <stdint.h>
#include <string.h>
#include "fpioa.h"
#include "i2s.h"
#include "dmac.h"
#include "sysctl.h"
#include "uarths.h"

/* ---- Build switches ---------------------------------------------------- */
#define NUM_DATA_LINES   2      /* both SD lines -> 4 mic slots             */
#define MIC_SLOT_OK      0      /* 0 = probe forever, 1 = probe then stream */

#define PROBE_SECONDS    6      /* text-only diagnostics before streaming   */

/* Which mic to start on, and whether to cycle.
 * START_MIC 0..NUM_SLOTS-1. START_CYCLING 0 means lock to START_MIC until
 * you press 'c'. Either can be changed live from the keyboard. */
#define START_MIC        0
#define START_CYCLING    1

#define USE_16_BIT       0      /* 0 = RESOLUTION_32_BIT, 1 = 16_BIT        */

#if USE_16_BIT
#  define SAMPLE_SHIFT   0      /* sample already sits in the low 16 bits   */
#else
/* 16 is unity for a 24-bit MSB-aligned sample; lower means more gain.
 * 13 measured as the smallest safe value on this board - see note (4). */
#  define SAMPLE_SHIFT   13
#endif

/* ---- Pins: match what the Recorder proved ------------------------------ */
#define IO_SCLK      18
#define IO_WS        19
#define IO_SD1       23        /* I2S_CHANNEL_0 -> slots 0, 1 */
#define IO_SD2       22        /* I2S_CHANNEL_1 -> slots 2, 3 */

#define SAMPLE_SHIFT 13        /* smallest value with clip=0 on every slot */

/* Slot -> physical position, from the tap test.
 *
 * The two pairs must be OPPOSING corners, and the pairs perpendicular to
 * each other - that is what makes atan2(lag_y, lag_x) a bearing rather
 * than a number. Slots 0/3 are one diagonal, 1/2 the other. */
#define MIC_EAST     0
#define MIC_WEST     3
#define MIC_NORTH    1
#define MIC_SOUTH    2

#define SAMPLE_RATE  16000
#define BLK          256
#define NUM_SLOTS    (NUM_DATA_LINES * 2)

/* One I2S frame is two 32-bit slots, so the bit clock is 64x the sample
 * rate. This is what i2s_set_sample_rate actually returns. */
#define BCLK_PER_SAMPLE  64

#define DMA_CH       DMAC_CHANNEL1
#define PLL2_FREQ    49152000UL
#define BAUD_RATE    1500000UL

#define SWITCH_SECONDS  3
#define BLOCKS_PER_SEC  (SAMPLE_RATE / BLK)
#define BLOCKS_PER_MIC  ((SWITCH_SECONDS * SAMPLE_RATE + BLK/2) / BLK)
#define PROBE_BLOCKS    ((uint32_t)PROBE_SECONDS * BLOCKS_PER_SEC)

/* Diagnostics ignore this many blocks at startup: whatever the DMA caught
 * before the clock settled is garbage, and reporting it as a fault sends
 * you chasing a problem that does not exist. */
#define SETTLE_BLOCKS  4

static uint32_t g_raw[2][BLK * NUM_SLOTS];
static int16_t  g_pcm[BLK];
static uint8_t  g_seq;

static uint8_t  g_mic     = START_MIC;
static int      g_cycling = START_CYCLING;
static int      g_want_stats = 0;


/* ============================================================================
 * Text output
 * ========================================================================= */
static void put(const char *s) { while (*s) uarths_putchar(*s++); }

static void put_hex32(uint32_t v)
{
    static const char H[] = "0123456789abcdef";
    for (int i = 28; i >= 0; i -= 4) uarths_putchar(H[(v >> i) & 0xF]);
}
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

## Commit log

2026-07-03 Created the repo
    Added the initial PCB Schematic and the Design Files with the Assets involved
    [capStone.kicad_pcb, capStone.kicad_sch]
2026-07-09 uploaded the 4 layer board
    [capStone.kicad_pcb, capStone.kicad_sch]
2026-08-13 Deleted Cap/capStone directory
    [capStone.kicad_pcb, capStone.kicad_sch]
2026-09-22 Revise README for two-board acoustic sensor design
    Updated the README to reflect changes from a single-board to a two-board design for the acoustic sensing node, including modifications to the architecture overview and hardware summary.
2026-10-05 Acoustic node: KiCad boards, K210 firmware, host tools, images
    [Accoustic_Sensing_Node-B_Cu.gbr, Accoustic_Sensing_Node-B_Mask.gbr, Accoustic_Sensing_Node-B_Paste.gbr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]

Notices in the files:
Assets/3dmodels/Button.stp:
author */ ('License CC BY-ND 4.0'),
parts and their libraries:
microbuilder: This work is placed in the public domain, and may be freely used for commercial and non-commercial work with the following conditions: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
